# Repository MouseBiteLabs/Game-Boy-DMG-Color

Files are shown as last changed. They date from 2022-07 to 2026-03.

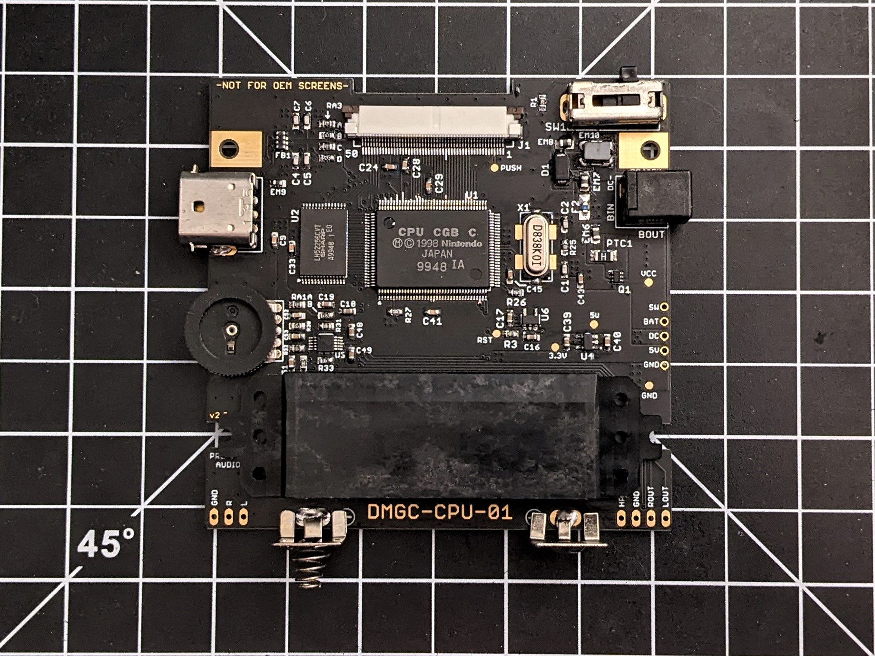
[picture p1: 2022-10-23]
DMGC-CPU-01/DMGC-CPU-01_2-0_FRONT.jpg

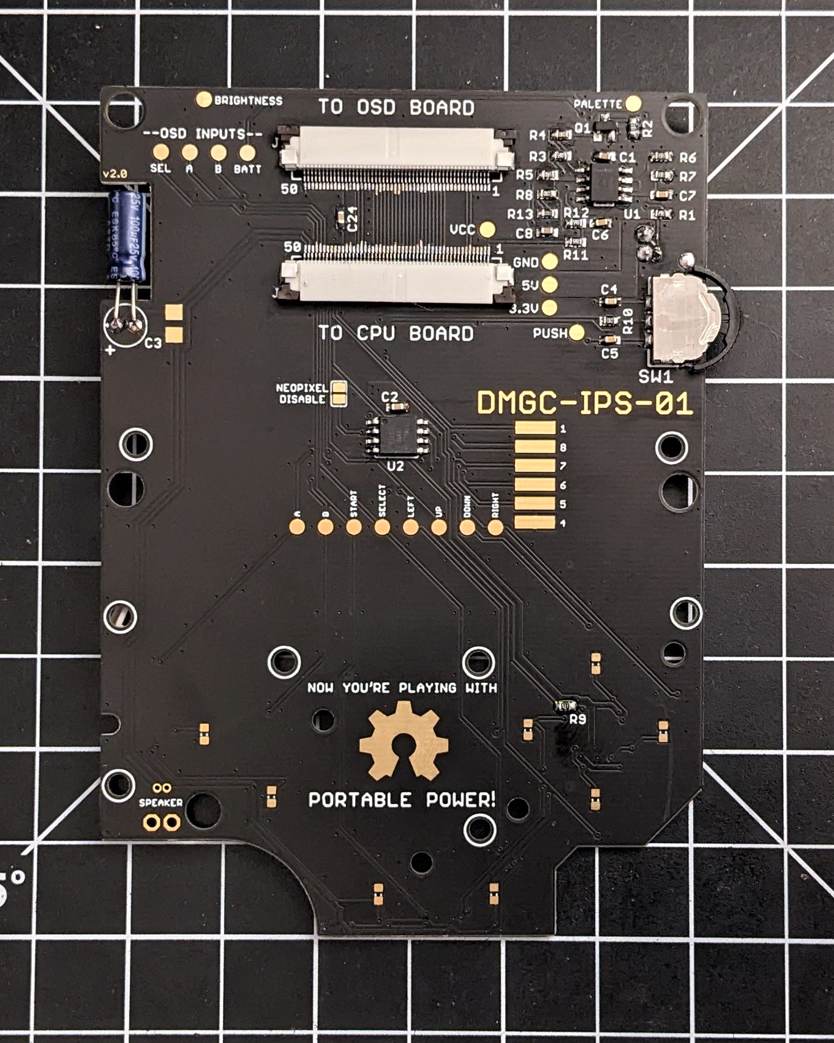
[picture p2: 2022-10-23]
DMGC-IPS-01/DMGC-IPS-01_2-0_BACK.jpg

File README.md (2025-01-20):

# Game Boy DMG Color

system

This is my design for an original Game Boy (model name DMG) with native Game Boy Color support, and a handful of improved features! This is an original creation - newly designed PCBs, with only some necessary components harvested from an original Game Boy and Game Boy Color (no hardware emulation – this project uses the original CPU). Here are the project goals:
-	An original Game Boy aesthetic, using the original Game Boy shell and interface (link port, volume wheel, power switch, etc.), but with the capability of playing both Game Boy and Game Boy Color games.
-	A nice, large IPS screen – the GBC Q5 XL IPS Backlight with OSD kit – with brightness and color palette control via the "navigation switch" housed where the contrast wheel used to be. (I will refer to the PCB attached to the Q5 screen as the “Q5 board”)
-	A modernized, efficient switch mode power supply that can run off 4x AA batteries or input from the DC jack, just like the original DMG. Testing shows that playing with NiMH AA batteries can yield more than 18 hours of gameplay at normal settings (AKA, the way I normally play it - maximum brightness and headphones). 
-	Louder, warmer sound through a modern audio amplifier.
-	The option for tactile switches for the face buttons - like the GBA SP.
-	The option for backlit buttons, with multiple color modes and brightness control.
-	No externally viewable case modifications, outside of trimming the DMG power switch cover for Game Boy Color game compatibility.

The code name for this project is DMGC. This console uses four PCBs, just as the original DMG model did - a CPU board (DMGC-CPU), display board (DMGC-IPS), power board (DMGC-PWR), and headphone board (DMGC-HDP). All circuit board assemblies have their own separate folders in this repository which contain detailed descriptions of operation, source files for schematics and board layouts (designed using Eagle), exported Gerber files, and some other relevant files. 

**Do you want to make one?** Then you NEED TO READ this entire page. Seriously. All your questions will be answered.

## Disclaimer

**Before I go any further, please read this VERY important disclaimer, if you are thinking about making this yourself. Don't let this picture happen to you!**



I made this project first and foremost **for my own purposes**. Nearly all of the features I have included are things I **personally** wanted. I have tried my hardest to make the project modular, if others would like to improve or change things easily, and I have also tried very hard to make the design somewhat less prone to potential errors during assembly (such as spacing out power pins on the FFC connectors). But in the end, every decision I made was for what I wanted the final product to be, with my skill level in mind.

Schematics, gerbers, and the BOM are provided in the various folders. If you choose to build this project yourself, be warned - this is a considerably advanced, and expensive build. You must be comfortable with the fact that you may lose or damage expensive components. **You are 100% liable for any damage done to your property or yourself. I am not responsible for any damage or loss of property incurred while attempting this project, or after completion of the project - you alone accept all risk.** While I am confident in this design, I cannot claim full compatibility with every system configuration. And there may be latent issues that have yet to crop up. I will update this repo if I encounter any, and if you see anything I may have missed, or some dubious design choice, feel free to ask questions or comment as such. Corrections are welcome. However, I **will not** obligate myself to providing tech support. You accept all risks and costs associated to this build if you choose to attempt it.



**DO NOT attempt this project if you are uncomfortable or inexperienced with detailed electronics troubleshooting, or are not proficient in soldering! You will AT MINIMUM need to be proficient in drag soldering and hot air reflowing. If you have not gained proficiency in these soldering skills, DO NOT ATTEMPT THIS PROJECT.**

If you attempt the build, start with trying to assemble DMGC-PWR-01. This is the toughest board to assemble, and it requires no donor components.

## Bill of Materials (BOM)

There are a handful of categories for the parts you need for this build. Please review all of them! The total BOM cost will come out to anywhere between $200 and $250 (NOT including the cost of a donor Game Boy Color console!) depending on the options you choose, which OEM parts you re-use, and any potential deals you can get on certain parts. Note that with the exception of a few components from a donor Game Boy Color, *most* of the electronic parts are brand new.

### I. Circuit Boards

First and foremost, the circuit boards. I have created these four boards myself, and you will need all of them:

1) <a href="https://mousebitelabs.etsy.com/listing/1317688422/game-boy-dmgc-cpu-board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">DMGC-CPU-01</a>: The CPU board, where the brains are held
2) <a href="https://mousebitelabs.etsy.com/listing/1331663235/game-boy-dmgc-ips-board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">DMGC-IPS-01</a>: The front display board
3) <a href="https://mousebitelabs.etsy.com/listing/1317694018/game-boy-dmgc-pwr-board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">DMGC-PWR-01</a>: The power supply board
4) <a href="https://mousebitelabs.etsy.com/listing/1331671237/game-boy-dmgc-hdp-board-headphone-board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">DMGC-HDP-01</a>: The board that holds the headphone jack

I have provided the zipped Gerbers and ordering details in each of the board folders above, <a href="https://www.pcbway.com/project/member/?bmbno=BC9D73E0-EF3D-4F">as well as shared projects on PCBWay.</a> For full disclosure, if you buy the PCBs from PCBWay, I will receive 10% of the total sale towards buying more boards from PCBWay. You can alternatively use these Gerbers at other PCB fabricators if you would like. 

<a href="https://www.pcbway.com/project/member/?bmbno=BC9D73E0-EF3D-4F">PCB from PCBWay</a>

I also sell them on my Etsy store, so you don't have to buy multiples! (Click the banner!)

<a href="https://mousebitelabs.etsy.com">PCB from Etsy</a> 

And finally, <a href="https://shop.insidegadgets.com/product/game-boy-dmg-color/">insideGadgets sells these boards partially assembled!</a>



### II. Brand New Electronic Parts

The DMGC uses mostly all-new parts. This isn't a direct-transfer style project! The master BOM with every electronic component required for the four circuit boards are provided in this root folder in Excel format. Furthermore, each folder for each board will contain their section of the BOM near the bottom of each README that contain all of the electronic components needed for that specific circuit board. Note that some parts may be out of stock at the links provided, but many can be found at alternate other retailers online, or have a proper substitute. <a href="https://www.mouser.com/ProjectManager/ProjectDetail.aspx?AccessID=6600c1bb14">Here is a saved cart from Mouser that contains all the parts in the BOM Excel, including some duplicates.</a> Double check to see if any parts are missing, and consider ordering multiples of some parts. There also may be some parts you want to remove (like the tactile switches).

**If a part is backordered, or out of stock** - check the Excel file, or the BOMs listed at the bottom of each board's folder in this repo. There may be alternate part options. You can also check for stock at places like Digikey. And you can always use Octopart.com to help find in-stock parts at other websites. I can't maintain the cart for every out-of-stock part, so please do some research :)

### III. Game Boy Electronic Parts

*This project requires at the very least a donor DMG console and a donor GBC console.*

There are a handful of parts that I have not located aftermarket substitutes for, and will therefore necessitate an original Game Boy console to salvage from. Please note that removing these parts is not a trivial task, and **requires advanced soldering and desoldering skills to be successful.**

The following parts are required from an original Game Boy Color console:

  -	U1 – CGB CPU (all revisions *except* REV E, which is *incompatible*)
  - X1 – 8.388 MHz crystal oscillator

The following parts can be salvaged from a Game Boy Color, but aftermarket options exist:

  - U2 – LH52256CVTXIZ (SRAM); alternate: https://mou.sr/3f8G0Mi
  - EM10 – input filter; alternate: https://mou.sr/3FiMvXw

The following parts are required from an original Game Boy (DMG) console:
  
  -	SW1 - Power switch
  -	DC jack
  -	Headphone jack

The following part is required from an original Game Boy (DMG), or a Game Boy Four Player Adapter:

  -	EXT port

The following parts can be salvaged from an original Game Boy (DMG), but aftermarket options exist:

  -	VR1 – Volume dial
  -	P1 – Cartridge connector

### IV. External Build Parts

The following is the high-level BOM - basically, the Game Boy part. Note that parts that deviate from the ones listed here (like different shell designs) might necessitate different fitment modifications, or end up being incompatible. Note that this list is not a comprehensive list of all the places you can get these parts. I encourage you to search around if you can't find what you want here.

-	**Shell:** I generally recommend the Funnyplaying "IPS Ready" ones if you don't want to trim anything, but the color and style options are limited. If you don't use these, then you're on your own for how to prepare it - generally, you can follow guides for preparing a Pocket for an IPS screen kit.
    - RGRS:	<a href="https://retrogamerepairshop.com/collections/game-boy-dmg-shells/products/game-boy-dmg-original-new-shells-factory-a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">Game Boy DMG Shell – Factory A</a> [Note: this one requires trimming!]
    - Funnyplaying: <a href="https://funnyplaying.com/products/dmg-ips-coustom-housing">DMG IPS Q5 Custom Housing</a>
- **Screen Kit:** This is the important one. You need this specific type of kit - the Q5 IPS with OSD. It goes by many names, the maker is Hispeedido (*not* FunnyPlaying). Kits that have the screen laminated to a GBC lens are *not* compatible, but kits that include a lit-up logo on the bottom part of the screen are fine to use. Make sure you DO NOT get any Game Boy DMG versions - they are not compatible! Also, be sure to test this screen kit before installing it, preferrably with an original Game Boy Color. Sometimes they arrive damaged, and once you've installed, it may not be possible to get a refund.
  - RGRS: <a href="https://retrogamerepairshop.com/products/game-boy-color-q5-ips-backlight-with-osd?variant=37646279213228">GBC Q5 XL IPS Backlight with OSD</a> OR <a href="https://retrogamerepairshop.com/collections/gbc-displays/products/game-boy-color-q5-osd-ips-kit-with-color-changing-logo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">Game Boy Color Q5 OSD IPS Kit with Color Changing Logo 
  - AliExpress: <a href="https://www.aliexpress.us/item/3256801650459088.html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">GBC Q5 IPS LCD Kit</a>
  - HHL: <a href="https://handheldlegend.com/products/game-boy-color-ips-lcd-q5-hispeedido">Game Boy Color IPS LCD Q5 - Hispeedido</a>  
- **Screen Centering Bracket:** You can find the design file for this bracket in the DMGC-IPS-01 folder. It's a custom designed bracket I made that *is required* for holding the screen in place. You will need access to a 3D printer for this part, or you can order it online from 3D printing services by uploading the file.
  - <a href="https://github.com/MouseBiteLabs/Game-Boy-DMG-Color/blob/main/DMGC-IPS-01/dmgc_q5_bracket.stl">DMGC Q5 Bracket 3D Model .stl File</a>
-	**Lens:** You must get the "IPS" style of lens, as the viewing area is larger.
    -	RGRS: <a href="https://retrogamerepairshop.com/collections/dmg-lenses/products/funnyplaying-dmg-q5-ips-lens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">FunnyPlaying DMG Q5 IPS Lens</a>
    - FunnyPlaying: <a href="https://funnyplaying.com/products/dmg-retro-pixel-ips-glass-lens">DMG RetroPixel IPS Glass Lens</a>
- **Buttons:** Funnyplaying models are generally OEM-like (IMO), but you can also use OEM ones. For the above build, I used Kitsch-Bent silicone buttons. Bonus: NES controller buttons fit inside the DMG.
  -	Kitsch-Bent: <a href="https://store.kitsch-bent.com/products/silicone-buttons?variant=40627510771907">Clear Silicone DMG Buttons</a>
  - RGRS: <a href="https://retrogamerepairshop.com/collections/dmg-buttons">DMG Buttons</a>
  - LabFifteen: <a href="https://labfifteenco.com/en-us/collections/game-boy-dmg-buttons">Game Boy DMG Buttons</a>
  - FunnyPlaying: <a href="https://funnyplaying.com/products/gb-dmg-custom-buttons">DMG Custom Buttons</a>  
- **Membranes:** Important, but very forgettable! You will need them even if you install tactile switches. You will, however, *not* need them if you use the Kitsch-Bent buttons.
  - RGRS: <a href="https://retrogamerepairshop.com/collections/dmg-buttons/products/funnyplaying-game-boy-dmg-silicone-button-contact-pad-membranes">FunnyPlaying Game Boy DMG Silicone Button Contact Pad Membranes
  - FunnyPlaying: <a href="https://funnyplaying.com/products/replacement-silicone-pads-for-gb-dmg">DMG Replacement Silicone Pads</a>  
- **Speaker:** There are tons of options for this as well, including using the OEM one.
  - RGRS: <a href="https://retrogamerepairshop.com/collections/dmg-audio/products/funnyplaying-clear-game-boy-dmg-original-speaker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">FunnyPlaying Clear Game Boy DMG Original Speaker</a>
  - FunnyPlaying: <a href="https://funnyplaying.com/products/clear-dmg-speaker">Clear DMG Speaker</a>
- **Battery Tabs:** This one is another part I commonly forget about. You can use a salvaged set of tabs, or order new ones.
  - RGRS: <a href="https://retrogamerepairshop.com/collections/dmg-power/products/game-boy-dmg-original-high-quality-replacement-battery-contact-terminals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">Game Boy DMG Original High Quality Replacement Battery Contact Terminals
- **Stickers:** Completely optional, but they can really bring a build together. Especially if you have custom DMG Color stickers!
  - Nextstopplease: <a href="https://nextstopplease.square.site/product/dmgc-label/230?cp=true&sa=true&sbp=false&q=false">DMGC Labels</a>

<b>Buying from RGRS? Consider helping out some cool people with these referral links:</b>
- <a href="https://retrogamerepairshop.com/?ref=ltyD2rUX">CodyWick</a>
- <a href="https://retrogamerepairshop.com/?ref=HSj4v5OO">JackV</a>

<b>Or use one of these discount codes at checkout:</b>
- Nataliethenerd
- B23N
- Tito

Note that the IPS kit I have listed is the *easiest* IPS kit to use that is compatible with this build. It includes an image centering feature, so you don't need to fiddle with centering it manually in the shell. Other kits likely would not center nicely in the DMG shell! <a href="https://retrogamerepairshop.com/collections/gbc-displays/products/game-boy-color-2-6-ips-high-brightness-drop-in-backlight-lcd-kit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">This kit works electrically, but requires you to center the image yourself.</a> If you end up making some sort of 3D-printed bracket to support this screen, feel free to share it here.

## Assembly

You can check out Tito's video on the DMGC to get an idea of how the assembly process generally goes.

MachoNacho DMGC Video (https://youtu.be/4U8Tqu7uxLo)

Here are some pictures of the assembly process *after* testing the functionality of all the boards separately. Detailed images of the circuit boards alone are shown in their respective folders. These pictures are of a previous revision, v1.2, but the process remains the same. You may notice some minor cosmetic differences in these pictures from the current revision boards.

**I highly recommend reading the information in the Troubleshooting and Testing folder above. In it, I detail the testing procedure that I follow before fully assembling a DMGC. It is far easier to do this than to have to disassemble things when something doesn't work.**

First, I started with the back half of the DMG shell. The PWR board needs five ~2.25" wires that wrap around the screw post on the side of the shell. In addition to the PWR board connections, the HDP board needs four ~2.6" wires. Also, the flat flex cable (FFC) should be inserted into the CPU board first, because the connector will be inaccessible after screwing the CPU board in the shell. After I soldered all the wires between the three boards and secured the FFC, I placed the assembly in the shell, and secured it with the proper screws. I put a game in the cartridge slot to keep the CPU board in place easier while assembling.

PXL_20220802_000205491 MP

Before placing the power switch cover in, I cut a notch in it so that it wouldn't prevent Game Boy Color games from being played in the system. In the left picture below I’m using Game Boy games, and in the right picture I'm using Game Boy Color. And you can see that the power switch is blocked from turning on by the GBC cartridge for the original model.



After the back half was done, I prepared the Q5 board solder pads. I cut six 30 gauge wire segments and soldered them on the brightness, palette, battery, and OSD input pads. These will be soldered to the rear of the IPS board after installed. You don't need to include a wire to the GND pad.



For the top half of the shell, as per instructions on a similar DMG IPS kit that uses the Q5 screen, I very carefully cut ~1 mm of plastic around the border of the viewing port, and trimmed any extra plastic to make the surface underneath the lens smooth (there are "IPS ready" shells that should not require this cut). I used a black paint marker to color in the edges of the newly cut plastic, so they would not be visible at an angle. And I trimmed two posts off of the shell so the screen would fit flush against it. 



Then I installed the front lens, and placed the screen, backed with the 3D printed bracket, into the front half of the shell. I made sure to clean up any stray fingerprints or dust while assembling this part. Once the bracket was placed and flush with the shell, I put the buttons in and placed the IPS board over top, slid the Q5 screen FFC into the connector on the PCB (making sure it fit without any added stress on any connections), and secured it all in place. Then I *very carefully* soldered the wires from the Q5 board onto the appropriate pads on the IPS board - making sure not to melt any plastic on the shell.



**Note: Be extremely careful with the screen. It is fragile. If you break it, you can sometimes buy one separately.

If you installed the 7-pin headers for programming the ATTINY easier, you might want to tape off the headers with kapton tape. If everything is installed correctly, these shouldn't interfere with anything on the CPU board after the halves are screwed together (C47 is the closest component), but you may want to consider it anyway.



After that, it was just a matter of connecting the FFC from the CPU to the IPS board, tucking it under the boards ensuring no kinks or sharp bends, and screwing it together. Once assembled, I opened the OSD menu for the IPS kit (Select + A + B) and changed the vertical and horizontal offsets (my values were 78 and 29, respectively) to center the image on the screen. The image centering function is one of the biggest reasons I chose this IPS kit.

I suggest running the color tests in the <a href="https://github.com/pinobatch/240p-test-mini/releases/">240p test suite ROM</a>, if you have a flash cart to run it on. It will tell you if you have any poor connections on the FFC lines - the screen might work, but you might be missing a connection on one of the 15 RGB pins! If your colors look off, reflow the connections on the top row of pins on the CPU and/or the FFC connectors (the issue may be on the CPU board, *or* the IPS board). This picture (provided by <a href="https://retrogamerepairshop.com/?ref=HSj4v5OO">JackV</a>) shows a before and after pic for reflowing a few mis-soldered color pins.



Next to an original DMG… one can really see the improvements!

PXL_20220816_034738908~2 (2)

## Auxilliary Controls
### Q5 XL IPS Backlight with OSD
-	Select + A + B: Open the OSD menu
-	Select + A: Enter
-	Select + B: Exit
-	A: Increase
-	B: Decrease

### Navigation Switch
-	Rock up: Advance screen brightness setting
-	Rock up/Hold: Toggle on-screen battery indicator
-	Rock down: Advance screen color pallete setting
-	Rock down/Hold: Toggle on-screen pixel grid
-	Push in: Toggle button LED color setting
-	Push in/Hold + D-pad Left: Decrease button LED brightness
-	Push in/Hold + D-Pad Right: Increase button LED brightness
-	Push in/Hold when turning on power switch: Disable LEDs until another power cycle

## Power Draw Measurements
For these estimates, battery life is calculated using four eneloop pro NiMH AA batteries (total of ~11800 mWh). Keep in mind that these are very rough estimates. I tried to be conservative in the power draw measurements, so hopefully these numbers represent a *mostly* worst case. Actual playtime *will* vary due to a variety of factors - changes in efficiency and performance as the battery voltage changes, differences in game audio, etc.

I measured the power draws using a MiniWare MDP-XP Mini Digital Power Supply, and estimated the average power draw shown on the display (I tried to bias towards a higher value). Input voltage was set to 4.4 V, just above the point where the power LED dims. I tested with the Legend of Zelda: Link's Awakening, letting the game sit on the title screen after the intro cinematic, where sound is relatively loud and the screen is mostly white. The audio gain on the test console is set to ~0.38 (see CPU board for more detail on this gain value - a higher gain can greatly impact power draw at high volumes out of the speaker).

| Test Criteria | Power Draw | Estimated Battery Life |
| --- | --- | --- |
| IPS max brightness, NeoPixel LEDs max brightness (white), speaker volume 100%, Everdrive X5	| 1150 mW	| 10.3 hr |
| IPS max brightness, NeoPixel LEDs off, speaker volume 100%, Everdrive X5 | 900 mW	| 13.1 hr |
| IPS max brightness, NeoPixel LEDs off, speaker volume 100%, original cartridge | 750 mW | 15.7 hr |
| IPS max brightness, NeoPixel LEDs off, headphones, Everdrive X5	| 725 mW	| 16.3 hr |
| IPS max brightness, NeoPixel LEDs off, headphones, original cartridge | 650 mW	| 18.2 hr |
| IPS min brightness, NeoPixel LEDs off, headphones, original cartridge	| 475 mW	| 24.8 hr |

*Note: If powering through the DC jack instead of batteries, an OEM adapter may not be able to supply enough power to the DMGC at maximum settings. Furthermore, <a href = "https://retrogamerepairshop.com/products/dmg-game-boy-original-dmg-usb-power-cord-adapter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">cables like these</a> will require at least ~200 mA output from the USB port for reliable operation at all settings. (USB 1.0 and 2.0 are likely not sufficient for higher loads, such as with the button LEDs on)*

## Audio Recordings and Spectrum
I mentioned the sound of the DMGC is "warmer" than an original GBC - it's bassier with less buzzing background noise (owing mostly to the modernized power supply). I connected the headphone jack to my computer's microphone input, and used Audacity to obtain line out recordings. Then I graphed the spectrum using Audacity's "plot spectrum" analysis tool. You can see the larger gain at the lower frequencies in the spectrum plot of the DMGC. I also took some recordings of the pro-sound output as well - it's even cleaner than from the amplifier. I'm not an audiophile, but I'm pretty sure the DMGC all-around sounds nicer, at least through headphones. Listen for yourself! (GitHub only allows for video files to be embedded, MP3 files are provided above)

### Original GBC Audio

https://user-images.githubusercontent.com/97127539/180215249-4b21aca1-a9fd-430a-a870-95bf4837e4da.mp4

### DMGC Audio

https://user-images.githubusercontent.com/97127539/180215280-5e533449-5116-4848-a94b-92f8979db334.mp4

### DMGC Audio (Pro-sound)

https://user-images.githubusercontent.com/97127539/197674317-792a8da5-ebd5-4ef6-9e8d-8eab0cbf9284.mp4

### Original GBC Audio Spectrum



### DMGC Audio Spectrum



### DMGC Audio (Pro-sound) Spectrum



## Possible Additions/Changes
Want to improve this project? Maybe try one of these things (because I probably won’t):
- This console uses 4x AAs instead of a single rechargeable battery in order to maintain the feel and weight of the original DMG model, but an obvious change to the build is to utilize a LiPo battery with proper battery management. The DC jack could be repurposed to charge the battery instead. With the advent of affordable rechargeable AAs, the appeal of the AC adapter is diminished, so this would be a good repurposing. However, the maximum output current of most DMG AC adapters is rated for ~200mA at ~6V, so charging would be considerably slower than, say, fast USB-C charging.
- Restoring the IR functionality of the GBC could also be done, as there is ample space for it on the circuit board and shell - I just do not trust myself with forming plastic to look nice, and it wasn't at all an important part of the build for me.
- Finding aftermarket equivalents for all the different required DMG parts would be ideal, instead of using a (hopefully broken) DMG for a donor console. For my personal build, I used original DMG components because I had a damaged console lying around, but you can easily find DMG-style volume wheels and cartridge connectors online. The tricky parts are as follows:
  - A GBC EXT port can be used in place of the DMG one (but would look kind of weird in the DMG EXT hole in the shell).
  - There are a few power switches I've ordered to try out in place of the DMG one, but I haven't gotten around to testing them yet. There's no one fully drop-in replacement that I've found, though, so it would require circuit modifications.
  - I haven't been able to locate a headphone jack exactly the same as the DMG one, but the circuit could be adapted to accept a different style.
  - The DC jack could be tricky. I haven't looked very hard for any kind of replacement for this.
- Any other of the various popular GBC mods could be incorporated if desired - bluetooth, overclocking, etc. With the ATTINY on the IPS board, one could incorporate button combinations to interface with these mods without the need of any additional buttons or (*shudder*) touch controls.
- I thought about adding LEDs to the *back* of the front PCB, so that light would emit out the edges of the console with a translucent or transparent shell, but I never got around to trying it out.

## Potential Issues/Annoyances
-	When the button LEDs are on max brightness, using the NeoPixel LEDs specifically (especially on the white color setting), a ~1 kHz whine can be heard through the speakers or headphones. I attempted to remove this whine with different methods – adding filtering to the supplies, using separate supplies for the audio/LEDs, etc. –  this lowered the noise amplitude, but I wasn’t able to remove it completely. And obviously adding a filter on the audio output is a no-go since 1 kHz is smack dab in the middle of the audible range. Changing to different color settings can reduce the volume of the whine, red in particular seems to be quite low, and setting the LEDs at lower brightness levels (or just completely off) removes it. So just don’t play with the LEDs on really bright if it bugs you! I kept the color sweep during power-on enabled on every color setting - if you want to disable the LEDs for the entire play session, hold the navigation dial in when you turn it on (but at that point... why did you bother adding the LEDs in the first place?)
-	The original DMG A/C adapter that plugs into the DC jack cannot support play with maximum settings (backlit buttons, maximum brightness, maximum speaker volume, flash cart). If you start up the Game Boy with less than maximum settings, then during gameplay increase the load on the power supply such as by increasing the screen brightness or maxing out the volume on the speakers, the console may shut off. If you're powering the console through the DC jack, I suggest using a USB adapter cable into a USB 3.0 port (or some style of USB wall charger)

## Frequently Asked Questions

I'll update this section as more people begin to build these.

**Q: How do I lower the brightness of the power LED? I can't see anymore.**

A: You can pick a different LED model with lower brightness, or you can simply increase the resistance of R1 on the IPS board. Higher resistance = lower brightness. I would try 10 kΩ first if 5.6 kΩ is too bright. (If you want to dim the low power level LED brightness, increase R2 resistance as well!)

**Q: My EM10 has an extra leg in-between two of the other ones. Can I use this part?**

A: Yes, just bend up the extra pin so that it doesn't contact any of the nearby pads. It is an unused anchor pin.

**Q: Why does the audio sound like [not normal]? (Usually asked while testing during the middle of a build)**

A: The audio will sound terrible if you do not have your IPS kit connected. You can use the CPU board's FFC connnector for the IPS kit if you would like to test it without the IPS board in the middle. Furthermore, the speaker will be muted if you do not install the headphone board.

**Q: Sometimes the power switch is finnicky and the system won't power on consistently. Sometimes the IPS screen will turn on, but only the backlight, not the actual image. What gives?**

A: Clean your power switch (without batteries inserted or power applied) by dripping isopropyl alcohol inside and flipping it off and on a few times. This will hopefully clear up debris or oxidation. Opening up a DMG power switch isn't the funnest thing to do. I have found that if the IPS kits receive intermittent power while turning on, it will lock out their image processing until you power cycle. It's not damaging, just annoying.

**Q: When I have the front and back halves of the DMGC separate, everything powers on correctly. But when I screw the two halves together, it doesn't turn on. Why?**

A: Check to make sure the wires connecting the CPU and PWR boards do not have long stubs of wire sticking up out of the CPU board. The IPS board's navigation dial has metal housing that can short these wire stubs together if they are too long. Trim them short so they don't touch the metal shielding.

**Q: Sometimes when I'm using batteries and turn the power switch on, nothing happens.**

-AND/OR-

**Q: Sometimes when I play my DMGC, and I set it on the table too hard, the game resets. Why?**

A: Usually this is because you're using NiMH AA batteries, like eneloop pros. These batteries have *slightly* shallower positive tabs than regular alkaline AA batteries. This makes contact from the batteries to the tabs not as robust as regular AA batteries. Unfortunately this is a problem on *ALL* DMG consoles, not specifically the DMGC. This could be due to a poor connection on any one of the four batteries inside the bay. You can swap out battery contacts that stick out a bit farther that make better contact with the batteries, or you can try reseating or literally spinning the batteries in the battery bay to make better contact. (Or, you could always use regular AA batteries or an A/C adapter!)

**Q: Can I use this with a DMG CPU?**

A: No, this is only for use with Game Boy Color CPUs. There are some other projects around that recreate the DMG, <a href="https://github.com/kamicane/DMG-01-B">like this one</a>.

**Q: I really like this project, but I just wish it was in a smaller, more cramped shell, with way worse battery life. Can you help?**

A: <a href="https://imgur.com/a/JgXPnYc">I'm working on it.</a>

## Acknowledgements
-	The board outlines and many of the footprints for the DMG components from <a href="https://gbdev.gg8.se/files/schematics/">this DMG recreation project</a> were used for reference on the original revision of the project, so very special thanks to Rolf, bit9, and nitro2k01!
-	Thank you to gekkio for their <a href="https://gbhwdb.gekkio.fi/">Game Boy repository</a> and <a href="https://github.com/Gekkio/gb-schematics">github</a>: I referenced many of the DMG and GBC resources during this build, even just for looking at pictures of different PCBs.
-	Immense thanks to the users of the r/Gameboy and gbdev discord servers for technical resources, troubleshooting/feedback, and suggestions. Could not have done this without your support. Shout out to kevtris for design feedback and lidnariq for troubleshooting support!
- Thank you to Tito, aka Macho Nacho, for <a href="https://www.youtube.com/watch?v=4U8Tqu7uxLo&ab_channel=MachoNachoProductions">his amazing video covering the project.</a>
-	Of course, huge thank you to everyone who has <a href="https://ko-fi.com/bucketmouse">donated and supported me</a>, and to those who have built their own DMGC! I love seeing pictures of builds, so feel free to share them with me on Twitter, <a href="https://discord.gg/Y5aDvCcpbX">discord</a>, or via email!

## License
<br />This work is licensed under a <a rel="license" href="http://creativecommons.org/licenses/by-sa/4.0/">Creative Commons Attribution-ShareAlike 4.0 International License</a>. You are able to copy and redistribute the material in any medium or format, as well as remix, transform, or build upon the material for any purpose (even commercial) - but you **must** give appropriate credit, provide a link to the license, and indicate if any changes were made.

This project is the culmination of nearly a full year of research, development, and testing. I have made this project completely open-source, and have put hundreds, if not *thousands* of hours of work into it, so that many people can enjoy it. **Please** give me appropriate credit where credit is due.

©MouseBiteLabs 2022

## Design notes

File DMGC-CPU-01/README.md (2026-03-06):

# DMGC-CPU-01

DMGC-CPU-01_2-3_scan
DMGC-CPU-01_2-0_ASSEMBLED

*The image above of the assembled board is of v2.0, not the current revision of v2.4. The differences in appearance are minor, see below.*

The CPU board houses the majority of the electronics in the DMGC. Parts harvested from the original GBC include the CPU, SRAM, and crystal oscillator. EM10 may be transferred as well, but a good enough replacement is included in the BOM if you need a new part. The power supply modifications, the new audio circuit, and a handful of omissions like the IR communication and some of the now-unnecessary LCD pins differentiate this build from the original GBC. But many connections and component values are pulled from the official GBC schematic (linked below).

For a technical explanation of the CPU board, please view the README in the Technical folder.

## Board Characteristics
The zipped folder contains all the gerber files for this board. 

-	Layers: 2
-	Thickness: 1.2 mm
-	Surface Finish: ENIG or HASL
-   **NOTE: For v2.4, when ordering PCBs, add this note to the order: "The file milling.gbr contains outlines for plated slots. Please add plated slots on the PCB according to this layer." V2.5 does not require this note.**

*HASL will work, but will potentially be more difficult for soldering fine-pitch parts like the CPU and FFC connector.*

<a href="https://www.etsy.com/listing/1317688422/game-boy-dmgc-cpu-board">**I sell this board on Etsy, so you don't have to buy multiples from board fabricators.**</a>

You can alternatively use the zipped folder at any board fabricator you like. You may also buy the board from PCBWay using this link (disclosure: I receive 10% of the  sale value to go towards future PCB orders):

<a href="https://www.pcbway.com/project/shareproject/Game_Boy_DMG_Color_DMGC_CPU_01_2f5c743d.html">PCB from PCBWay</a> 

## Customization Options

This section will explain all of the different customization options available on this board while assembling.

### Adjusting Volume Range

You can adjust the maximum volume coming out of the speakers and headphones by modifying R30 and R32 values. Increase R30 and R32 to decrease the maximum volume; decrease R30 and R32 to increase the maximum volume. Choose the same values for both of these resistors, otherwise you'll have lopsided audio channels. After some trial and error, here's my approximations of some different values of resistors:
- Choosing 100 kΩ for a gain of ~0.18 will yield about the same volume as a stock GBC. 
- Using 47 kΩ seemed to hit a sweet spot for my tastes for a gain of ~0.38 - not too loud, not too quiet.
- The lowest value I tried out was 33 kΩ, but this was *considerably* loud. It also began to have an actual impact in the battery voltage. I suspect values lower than about 20 kΩ will greatly reduce battery life.

### Pro-Sound Output

Added in version 2.0, opposite of the regular headphone outputs, are a set of audio outputs denoted as "pre-pot audio." The left and right channels connect directly to the VR1-S01 and VR1-S02 nodes, which allows you to grab the audio unfiltered, unamplified, right from the GBC CPU (through a protection resistor/capacitor combo). This is colloquailly known as the "pro-sound" mod, and is typically used in conjunction with a *second* audio jack. Audiophiles like to use this raw output with their audio equipment (note that using the pro-sound output as input to an external amplifier does not disable the speaker or headphones - the potentiometer still controls volume for those audio outputs). You could use this jack for headphones if you want (and it will disable the speaker), but it will always be one volume - about as loud as the original GBC at max volume. The audio coming out of these pins does sound incredibly clean - check out the recordings in the root folder. These outputs should make the system compatible with any pro-sound headphone boards, <a href="https://www.retromodding.com/products/gameboy-pcb-mount-pro-sound-v3">like this one.</a>

### Adding Reset Button Functionality

Version 2.0 also introduces a test pad labelled "RST" that connects directly to the /RESET pin. If this pin is pulled to GND, when it's released it the system will reset back to the boot screen. If you wire this pad to a button that connects the pad to GND when pressed, you basically have added a reset button to your DMGC. 

There are also pads near the FFC connector that are added labelled "PUSH" and "ROCK DOWN". These connect to the rocker switch on the DMGC-IPS-01 board (version 2.0 and later). The PUSH pad becomes connected to GND when the rocker switch is pushed in and floats when not pressed (as long as you remove R10 on the DMGC-IPS-01 board). The ROCK_DOWN pad connects to GND when the rocker switch is rocked down, and floats when not pressed (as long as you remove C5 on the DMGC-IPS-01 board).

In a normal configuration, pushing in on the rocker switch will control the button LEDs, and rocking down will swap the Q5 color settings, but if you don't want to use one of these features, then adding a wire from the PUSH or ROCK DOWN pad to RST pad will turn the rocker switch into a reset button for the system for that specific action and replace its normal function.

**CAUTION: Remember to remove R10 or C5 on the IPS board if you plan to use this feature!!!**





## Bill of Materials

Here, I have provided links to components I used personally (or suitable replacements). This BOM is also included in Excel format in the root folder.

| Reference Designators | Qty | Value/Part Number | Package | Description | Comment | Source |
| --- | --- | --- | --- | --- | --- | --- |
| +,- | 2 | | | Battery terminals  | Can be salvaged from DMG instead | [https://retrogamerepairshop.com/collections/dmg-power/products/game-boy-dmg-original-high-quality-replacement-battery-contact-terminals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](https://retrogamerepairshop.com/collections/dmg-power/products/game-boy-dmg-original-high-quality-replacement-battery-contact-terminals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) |
| C1 | 1 | 18pF | 0603 | Capacitor (MLCC) | Should be X5R (or better); at least 1% tolerance; at least 16V | [https://www.mouser.com/ProductDetail/YAGEO/CC0603FRNPO9BN180?qs=vTakOoo5QyL0KzYUzHPSUw%3D%3D](https://www.mouser.com/ProductDetail/YAGEO/CC0603FRNPO9BN180?qs=vTakOoo5QyL0KzYUzHPSUw%3D%3D) |
| C2 | 1 | 27pF | 0603 | Capacitor (MLCC) | Should be X5R (or better); at least 1% tolerance; at least 16V | [https://www.mouser.com/ProductDetail/603-C0603FRNPO9BN270](https://www.mouser.com/ProductDetail/603-C0603FRNPO9BN270) |
| C4 | 1 | 22pF | 0603 | Capacitor (MLCC) | | [https://www.mouser.com/ProductDetail/YAGEO/CC0603JRNPO9BN220?qs=vTakOoo5QyIVMYOUTI%2F4zA%3D%3D](https://www.mouser.com/ProductDetail/YAGEO/CC0603JRNPO9BN220?qs=vTakOoo5QyIVMYOUTI%2F4zA%3D%3D) |
| C5, C6, C7 | 3 | 100pF | 0603 | Capacitor (MLCC) | | [https://www.mouser.com/ProductDetail/YAGEO/CC0603JPNPO9BN101?qs=7s%252B3O6pAiyAo%2FUxNqKltRA%3D%3D](https://www.mouser.com/ProductDetail/YAGEO/CC0603JPNPO9BN101?qs=7s%252B3O6pAiyAo%2FUxNqKltRA%3D%3D) |
| C9, C10, C29, C33, C41, C45 | 6 | 0.01uF | 0603 | Capacitor (MLCC) | Should be X5R (or better), at least 16V | [https://www.mouser.com/ProductDetail/KEMET/C0603C103J5RACTU?qs=BimOss5pjlFJEfKhlb7g1g%3D%3D](https://www.mouser.com/ProductDetail/KEMET/C0603C103J5RACTU?qs=BimOss5pjlFJEfKhlb7g1g%3D%3D) |
| C16, C17, C18, C19, C39, C40, C48, C49, C51 | 9 | 1uF | 0603 | Capacitor (MLCC) | Should be X5R (or better), at least 16V | [https://www.mouser.com/ProductDetail/KEMET/C0603C105K4RACTU?qs=STjISULpmtZNMAZGR4X39Q%3D%3D](https://www.mouser.com/ProductDetail/KEMET/C0603C105K4RACTU?qs=STjISULpmtZNMAZGR4X39Q%3D%3D) |
| C24, C28, C43, C52, C53 | 5 | 0.1uF | 0603 | Capacitor (MLCC) | Should be X5R (or better), at least 16V | [https://www.mouser.com/ProductDetail/?qs=l5k%252BbMnNDknCtKnMv1oEgA%3D%3D](https://www.mouser.com/ProductDetail/?qs=l5k%252BbMnNDknCtKnMv1oEgA%3D%3D) |
| C47 | 1 | 150pF | 0603 | Capacitor (MLCC) | | [https://www.mouser.com/ProductDetail/KEMET/C0603C151J5GACTU?qs=V6nSPVTm7vxbAvL0weNH%252BQ%3D%3D](https://www.mouser.com/ProductDetail/KEMET/C0603C151J5GACTU?qs=V6nSPVTm7vxbAvL0weNH%252BQ%3D%3D) |
| D1 | 1 | PMEG2010AEH | SOD-123 | Schottky diode | Most schottky diodes should be suitable (at least 1A, 16V) | [https://www.mouser.com/ProductDetail/?qs=LOCUfHb8d9u7lcjEnyhX1g%3D%3D](https://www.mouser.com/ProductDetail/?qs=LOCUfHb8d9u7lcjEnyhX1g%3D%3D) |
| DC | 1 | | | DC jack | | Salvaged (DMG) |
| EM6-EM8 | 3 | FBMH2012HM221-T | 0805 | Filter | | https://mou.sr/3YT6y8F |
| EM9 | 1 | BLM18BD102SN1D | 0603 | Filter | | [https://www.mouser.com/ProductDetail/Murata-Electronics/BLM18BD102SN1D?qs=h3IWXJJGQQWi4eZyJq6ScQ%3D%3D](https://www.mouser.com/ProductDetail/Murata-Electronics/BLM18BD102SN1D?qs=h3IWXJJGQQWi4eZyJq6ScQ%3D%3D) |
| EM10 | 1 | 744235601 | | Common mode filter | Can be salvaged from GBC instead | [https://www.mouser.com/ProductDetail/Wurth-Elektronik/744235601?qs=BXmE%252BJ0Y7xYO4MPd53j2NQ%3D%3D](https://www.mouser.com/ProductDetail/Wurth-Elektronik/744235601?qs=BXmE%252BJ0Y7xYO4MPd53j2NQ%3D%3D) |
| F1 | 1 | 2.5A | 1206 | Fuse | | [https://www.mouser.com/ProductDetail/Panasonic/ERB-RG2R50V?qs=Z3CaLxJiOJK8SjHyp%252BdV%2FQ%3D%3D](https://www.mouser.com/ProductDetail/Panasonic/ERB-RG2R50V?qs=Z3CaLxJiOJK8SjHyp%252BdV%2FQ%3D%3D) |
| F2 | 1 | 1A | 1206 | Fuse | | [https://www.mouser.com/ProductDetail/Littelfuse/0466001.NR?qs=ar9f0rk5DXDy6tpNfF8WnQ%3D%3D](https://www.mouser.com/ProductDetail/Littelfuse/0466001.NR?qs=ar9f0rk5DXDy6tpNfF8WnQ%3D%3D) |
| FB1 | 1 | BLA31AG601SN4D | 1206 | Ferrite Bead | | [https://www.mouser.com/ProductDetail/Murata-Electronics/BLA31AG601SN4D?qs=2ahBf5rJw09FDcUVkQibEg%3D%3D](https://www.mouser.com/ProductDetail/Murata-Electronics/BLA31AG601SN4D?qs=2ahBf5rJw09FDcUVkQibEg%3D%3D) |
| P1 | 1 | | | Cart connector | Can be salvaged from DMG instead | [https://www.aliexpress.com/item/3256802533298738.html?spm=a2g0o.order_list.0.0.5ee21802yek6HF](https://www.aliexpress.com/item/3256802533298738.html?spm=a2g0o.order_list.0.0.5ee21802yek6HF) |
| P2 | 1 | | | Link port | | Salvaged (DMG) |
| P3 | 1 | 62684-502100AHLF  | | FFC connector | | [https://www.mouser.com/ProductDetail/?qs=HL%252BYNjdyZ0vzwc9E0QYY2g%3D%3D](https://www.mouser.com/ProductDetail/?qs=HL%252BYNjdyZ0vzwc9E0QYY2g%3D%3D) |
| PTC1 | 1 | 1.1A Hold | 1206 | Resettable Fuse | | [https://www.mouser.com/ProductDetail/Littelfuse/1206L110THYR?qs=CPcc0c%2Fon9HuH5Zb2mgbPg%3D%3D](https://www.mouser.com/ProductDetail/Littelfuse/1206L110THYR?qs=CPcc0c%2Fon9HuH5Zb2mgbPg%3D%3D) |
| Q1 | 1 | SI1443EDH | SOT363 | P-channel MOSFET | | [https://www.mouser.com/ProductDetail/Vishay-Semiconductors/SI1443EDH-T1-GE3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](https://www.mouser.com/ProductDetail/Vishay-Semiconductors/SI1443EDH-T1-GE3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) |
| R1 | 1 | 1k | 0603 | Resistor | | [https://www.mouser.com/ProductDetail/YAGEO/RC0603FR-071KL?qs=VU8sRB4EgwApHsk4rF%2F3zg%3D%3D](https://www.mouser.com/ProductDetail/YAGEO/RC0603FR-071KL?qs=VU8sRB4EgwApHsk4rF%2F3zg%3D%3D) |
| R3, R31, R33 | 3 | 18k | 0603 | Resistor | | [https://www.mouser.com/ProductDetail/YAGEO/RC0603FR-1018KL?qs=qpJ%252B%252B%252Bdg6p1T2VMMxU7GeA%3D%3D](https://www.mouser.com/ProductDetail/YAGEO/RC0603FR-1018KL?qs=qpJ%252B%252B%252Bdg6p1T2VMMxU7GeA%3D%3D) |
| R25 | 1 | 1.5M | 0603 | Resistor | Recommended at least 1% tolerance | [https://www.mouser.com/ProductDetail/YAGEO/RC0603FR-071M5L?qs=VU8sRB4EgwAP38Z8qzPx9Q%3D%3D](https://www.mouser.com/ProductDetail/YAGEO/RC0603FR-071M5L?qs=VU8sRB4EgwAP38Z8qzPx9Q%3D%3D) |
| R26 | 1 | 5.6k | 0603 | Resistor | | [https://www.mouser.com/ProductDetail/YAGEO/RC0603FR-075K6L?qs=2cAdsCoAWRHvOVv%2Fp%252BkS0g%3D%3D](https://www.mouser.com/ProductDetail/YAGEO/RC0603FR-075K6L?qs=2cAdsCoAWRHvOVv%2Fp%252BkS0g%3D%3D) |
| R27 | 1 | 100 | 0603 | Resistor | | [https://www.mouser.com/ProductDetail/YAGEO/RC0603FR-07100RL?qs=NEN%2FsE%2FLsvPIwIWKCOS4%2FA%3D%3D](https://www.mouser.com/ProductDetail/YAGEO/RC0603FR-07100RL?qs=NEN%2FsE%2FLsvPIwIWKCOS4%2FA%3D%3D) |
| R36 | 1 | 100k | 0603 | Resistor | | [https://www.mouser.com/ProductDetail/YAGEO/RC0603FR-07100KL?qs=e1ok2LiJcmaihem8Va5%2Fsw%3D%3D](https://www.mouser.com/ProductDetail/YAGEO/RC0603FR-07100KL?qs=e1ok2LiJcmaihem8Va5%2Fsw%3D%3D) |
| R30, R32 | 2 | 47k | 0603 | Resistor | | [https://www.mouser.com/ProductDetail/YAGEO/RC0603FR-1047KL?qs=EiqXWrxQq600ZhhpLJs%252BtA%3D%3D](https://www.mouser.com/ProductDetail/YAGEO/RC0603FR-1047KL?qs=EiqXWrxQq600ZhhpLJs%252BtA%3D%3D) |
| RA1A, RA1B | 2 | 510 | 0603 | Resistor | | [https://www.mouser.com/ProductDetail/YAGEO/RC0603FR-07510RL?qs=gt6vzsuosg04lV7mPQHzdw%3D%3D](https://www.mouser.com/ProductDetail/YAGEO/RC0603FR-07510RL?qs=gt6vzsuosg04lV7mPQHzdw%3D%3D) |
| RA3A-RA3D | 4 | 270 | 0603 | Resistor | | [https://www.mouser.com/ProductDetail/YAGEO/RC0603FR-07270RL?qs=diQw95jMAePl%252BPNr4oNP6Q%3D%3D](https://www.mouser.com/ProductDetail/YAGEO/RC0603FR-07270RL?qs=diQw95jMAePl%252BPNr4oNP6Q%3D%3D) |
| SW1 | 1 | | | Power switch | | Salvaged (DMG) |
| U1 | 1 | GBC CPU | QFP-128 | CPU | | Salvaged (GBC) |
| U2 | 1 | LH52256CVTXIZ | TSOP-28 | RAM | Replacement: https://mou.sr/3f8G0Mi | Salvaged (GBC) |
| U3 | 1 | LM4853 | VSSOP-10 | Audio amplifier | | [https://www.mouser.com/ProductDetail/Texas-Instruments/LM4853MM-NOPB?qs=QbsRYf82W3F2psFI2da2Dw%3D%3D](https://www.mouser.com/ProductDetail/Texas-Instruments/LM4853MM-NOPB?qs=QbsRYf82W3F2psFI2da2Dw%3D%3D) |
| U4 | 1 | NCP161ASN330T1G | SOT23-5 | LDO | Can also use TLV70233QDBVRQ1, probably | [https://www.mouser.com/ProductDetail/863-NCP161ASN330T1G](https://www.mouser.com/ProductDetail/863-NCP161ASN330T1G) |
| U6 | 1 | TPS3840DL35 | SOT23-5 | Supervisory IC | Could feasibly use TPS3840DL37 or 40 if 35 is out of stock | [https://www.mouser.com/ProductDetail/Texas-Instruments/TPS3840DL35DBVR?qs=7MVldsJ5UawbjRj7dP73rA%3D%3D](https://www.mouser.com/ProductDetail/Texas-Instruments/TPS3840DL35DBVR?qs=7MVldsJ5UawbjRj7dP73rA%3D%3D) |
| VR1 | 1 | 10k | | Volume wheel | Can be salvaged from DMG instead | [https://aliexpi.com/qg1M](https://aliexpi.com/qg1M) |
| X1 | 1 | 8.388608MHz | 7.5X5-4-PAD | Crystal oscillator | Potential replacement (not very space-friendly): https://mou.sr/3D5AUbH | Salvaged (GBC) |

## Revision History

### v2.5
- Added space for adding <a href="https://shop.insidegadgets.com/product/gba-clockxcontrol/">ClockxControl by insideGadgets</a>

### v2.4
- Changed some reference designators for more consistency to source PCBs
- Expanded slot for FFC to feed through to back of board

### v2.3

- Nudge volume dial to better center it in the shell

### v2.2

- Added more clearance on screwhole on cart connector
- Adjusted screwhole placement near power switch
- Removed unnecessary vestigal dots on X1 and EM10 silkscreen
- Fixed tstop layer offset on SRAM package
- Added CLK1/2 on backside silkscreen
- Adjusted X1 through-hole location
- Nudged volume dial out a bit
- Add note about trimming wire stubs on PWR board connections
- Cleaned up some trace layouts/silkscreen

### v2.1

- Fixed silkscreen text error on link port
- Added through-holes for potential crystal oscillator replacement
- Added test pad that connects to the rock-down function of the navigation dial on the IPS board
- Moved version number text above cart connector footprint

### v2.0

- Changed holes to slots where applicable
- Made board/part measurements more accurate
- Added dedicated output pins for pro-sound output next to the negative battery tab
- Updated crystal oscillator footprint to allow for later crystal packages
- Added a test pad that connects to the push-in trigger for the rocker switch on the IPS board
- Added a test pad connected to the reset line on the CPU for potential mods (pull to GND to reset the Game Boy)
- Added LP line from CPU to FFC connector for potential use with another IPS kit

### v1.3

- Added test points to back of the board
- Shifted FFC connector down a few mm

### v1.2

- Release version

## License
<br />This work is licensed under a <a rel="license" href="http://creativecommons.org/licenses/by-sa/4.0/">Creative Commons Attribution-ShareAlike 4.0 International License</a>. You are able to copy and redistribute the material in any medium or format, as well as remix, transform, or build upon the material for any purpose (even commercial) - but you **must** give appropriate credit, provide a link to the license, and indicate if any changes were made.

©MouseBiteLabs 2022

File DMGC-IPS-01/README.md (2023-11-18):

# DMGC-IPS-01

DMGC-IPS-01_2-3_scan
DMGC-IPS-01_2-0_ASSEMBLED

*The image above of the assembled board is of v2.0, not the current revision of v2.4. The differences are very minor, see below.*

The IPS board is in the front of the DMG shell. This holds the IPS screen kit (and has pads for interfacing with it), has the dimmable power LED, button inputs along with pads for optional LEDs, a navigation switch on the side for changing settings on the IPS screen and the backlit buttons, and the speaker.

For a technical explanation of the CPU board, please view the README in the Technical folder.

## Board Characteristics

The zipped folder contains all the gerber files for this board.
-	Layers: 2
-	Thickness: 1.2 mm
-	Surface Finish: ENIG or HASL (SEE NOTE!)

*ENIG is required for reliable button press detection; you can use HASL if you are using tactile switches.*

<a href="https://www.etsy.com/listing/1331663235/game-boy-dmgc-ips-board">**I sell this board on Etsy, so you don't have to buy multiples from board fabricators.**</a>

You can alternatively use the zipped folder at any board fabricator you like. You may also buy the board from PCBWay using this link (disclosure: I receive 10% of the  sale value to go towards future PCB orders):

<a href="https://www.pcbway.com/project/shareproject/Game_Boy_DMG_Color_DMGC_IPS_01_82a454c9.html">PCB from PCBWay</a>

## Customization Options

This section will explain all of the different customization options available on this board while assembling.

### Tactile Switches

Version 2.0 introduced the option for including tactile switches for the buttons, much like the Game Boy Advance SP had. If you do not wish to use these kinds of buttons, the button contacts are still set up to act just like the regular set up with membranes.



In this image, tactile switches are on the left, and pads for simple membranes are on the right. Either method for button presses works perfectly fine. But make sure you put them in the correct way. The little "wings" on the switches should be oriented where there is blank board space.

If you're doing tactile switches on the start and select buttons, you should do a trace cut as indicated where the white lines are pointing. If you don't, the membranes can still activate the start/select buttons on the exposed area without actuating the tactile switch. You may also want to tape over the exposed copper not underneath the switches while soldering them on to avoid getting stray solder on the exposed traces and ruin the A E S T H E T I C.



### Power LED Brightness

Increase the value of R1 to decrease the brightness of the power LED during normal battery levels. Increase the value of R2 to decrease the brightness of the power LED during low battery levels. It is suggested to try changing resistances in ~5 kΩ increments.

### Backlit Buttons

There are a few different avenues to take with respect to the button LEDs. You can use the RGB NeoPixels, discrete always-on LEDs, or none at all.

1) **No Button LEDs:** You do not need to populate LED10-LED17, R9, R22-R29, C2, or U2. Carry on.

2) **Always-on Single Color Backlit Buttons:** If you only want backlit buttons with non-controllable LEDs, you can omit R9, C2, and U2. 

You must isntead install R22-R29, as well as the discrete 0603 LEDs. An 0603 LED will fit on half of the 4-pin RGB LED pads, from VDD to DO. The pads for this are indicated by the arrows. The picture below shows which pads to use for discrete LEDs (view of the D-pad) - the A indicates the anode of the diode. There are spaces for a resistor for each LED on the back of the board (R22 to R29, circled in red below). If you're using the RGB LEDs, or no LEDs at all, the resistors aren't necessary. R22-R29 control the brightness of the LEDs, so keep in mind a higher resistance means lower brightness.



3) **RGB Backlit Buttons:** If you would like RGB LEDs behind the buttons, you must install LED10-LED17, R9, C2, and U2. Do not populate R22-R29.

When you solder the LEDs on, I recommend taping off the button contacts to make sure you don't get solder on them. It won't damage them to the point of non-function, but it can potentially reduce their useful lifetime and accurate detection depending on the severity. (But more importantly, it's not A E S T H E T I C)



If you install the LEDs and determine they just aren't for you, but don't want want to spend time removing the LEDs themsleves, then bridging the solder pad labeled "NEOPIXEL DISABLE" will ground the navigation switch push function, preventing the LEDs from turning on at all.

#### Programming the ATTINY85

An easy way to program the ATTINY with the code for the backlit buttons is to use an Arduino Uno or Arduino Mega. Check out these tutorials for how to program ATTINY chips with them:

-	<a href="https://www.instructables.com/How-to-Burn-ATTiny85-Using-Arduino-Mega/">Instructables post for programming an ATTINY85 with an Arduino Mega</a>
-	<a href="https://www.instructables.com/How-to-Program-an-Attiny85-From-an-Arduino-Uno/">Instructables post for programming an ATTINY85 with an Arduino Uno</a>

The code is provided above (the .ino file) and you will likely need to install Adafruit's NeoPixel library as well to get it to compile correctly. That can be found here:

- <a href="https://learn.adafruit.com/adafruit-neopixel-uberguide/arduino-library-installation">Installing Adafruit's NeoPixel Library to Arduino IDE</a>

If you're programming the ATTINY while it's installed on the IPS board, be sure to remove the cables from J1 and J2, otherwise your Arduino will attempt to backfeed the Gameboy and/or the IPS screen kit.

You can use the 7-pin connector on the side of the IPS board to connect to the ATTINY if it's already on the PCB. (You don't need the 3.3V pin to program, it's there for helping you develop your own ATTINY code if you want to use it)



**NOTE: VERSION DIFFERENCE**

On the v2.0 and v2.1 boards, pins 1 and 8 are flipped! And the 3.3V pin does not exist.



### Adding Reset Button Functionality

- If you are using the push function of the navigation switch to reset the console instead of controlling the button LEDs (see more info on the CPU README), then **make sure to remove R10.** You will not have the ability to control Neopixel LEDs with this change (without other code/hardware modifications).
- If you are using the rock down function of the navigation switch to reset the console instead of controlling the Q5 palette setting (see more info on the CPU README), then **make sure to remove C5.** You will not have the ability to use the palette swap function of the Q5 kit with this change (but who really cares, amirite?)





### Alternate OSD Controls

You don't need to use the SEL, A, and B pads at the top of the board for the OSD controls. You can alternatively use the button pads in the middle of the board instead. For example, if you intend to use LSDJ on the DMGC, you might run into a conflict with pressing A + B + Select. This is a specific combination for control in LSDJ. So instead for OSD control, you can run wires down to the middle of the board. Instead of A, B, and Select, you could pick A, B, and Start for example. Just keep in mind you have to press all three at the same time to open the menu, so don't pick Left and Right as two of the inputs, for example.



## Bill of Materials

Here, I have provided links to components I used personally (or suitable replacements). This BOM is also included in Excel format in the root folder.

| Reference Designators | Qty | Value/Part Number | Package | Description | Comment | Source |
| --- | --- | --- | --- | --- | --- | --- |
| B1-B8 | 8 | SKRRABE010 | | Tactile switch | Optional, can be omitted if you don't want clicky SP-style buttons (SKRRAA is less clicky, SKRRAC is more clicky) | [https://www.mouser.com/ProductDetail/688-SKRRAB](https://www.mouser.com/ProductDetail/688-SKRRAB) |
| C1, C2, C6, C7, C8, C24 | 6 | 0.1uF | 0603 | Capacitor (MLCC) | Should be X5R (or better), at least 16V | [https://www.mouser.com/ProductDetail/?qs=l5k%252BbMnNDknCtKnMv1oEgA%3D%3D](https://www.mouser.com/ProductDetail/?qs=l5k%252BbMnNDknCtKnMv1oEgA%3D%3D) |
| C3 | 1 | 100uF | | Capacitor (Aluminum electrolytic) | Board has space for a 100uF SMD tantalum electrolytic instead | [https://www.mouser.com/ProductDetail/KEMET/ESK107M010AC3AA?qs=9RUIYXQlAdBiO30krUyznA%3D%3D](https://www.mouser.com/ProductDetail/KEMET/ESK107M010AC3AA?qs=9RUIYXQlAdBiO30krUyznA%3D%3D) |
| C4, C5 | 2 | 100pF | 0603 | Capacitor (MLCC) | | [https://www.mouser.com/ProductDetail/YAGEO/CC0603JPNPO9BN101?qs=7s%252B3O6pAiyAo%2FUxNqKltRA%3D%3D](https://www.mouser.com/ProductDetail/YAGEO/CC0603JPNPO9BN101?qs=7s%252B3O6pAiyAo%2FUxNqKltRA%3D%3D) |
| C9, C10 | 2 | 27pF | 0603 | Capacitor (MLCC) | | [https://www.mouser.com/ProductDetail/603-C0603FRNPO9BN270](https://www.mouser.com/ProductDetail/603-C0603FRNPO9BN270) |
| FFC Cable | 1 | 15020-0541 | | Flat Flexible Cable | Gold plated preferred, but alternate part can work too. Note that 15020-0541 must be bent in the proper direction for good fitment | [https://www.mouser.com/ProductDetail/Molex/15020-0541?qs=pwzmk436yFR5fXbQvbR%2F1w%3D%3D](https://www.mouser.com/ProductDetail/Molex/15020-0541?qs=pwzmk436yFR5fXbQvbR%2F1w%3D%3D) |
| J1, J2 | 2 | 62684-502100AHLF  | | FFC connector | | https://www.mouser.com/ProductDetail/?qs=HL%252BYNjdyZ0vzwc9E0QYY2g%3D%3D |
| J3 | 1 | TSM-107-01-T-SH | | Surface Mount Terminal Strip | Optional for assembly, only helpful for programming the ATTINY | [https://www.mouser.com/ProductDetail/200-TSM10701TSH](https://www.mouser.com/ProductDetail/200-TSM10601TSH) |
| LED1 | 1 | 151033RS03000 | 3mm | Red LED | | [https://www.mouser.com/ProductDetail/Wurth-Elektronik/151033RS03000?qs=LlUlMxKIyB1%252BAw6bWFN43w%3D%3D](https://www.mouser.com/ProductDetail/Wurth-Elektronik/151033RS03000?qs=LlUlMxKIyB1%252BAw6bWFN43w%3D%3D) |
| LED10-LED17 | 8 | WS2812 | 2020 | RGB LED | Link leads to a 10-pack. Discrete 0603-size LEDs can be used instead | [https://www.mouser.com/ProductDetail/Adafruit/4684?qs=DPoM0jnrROWIv9%2FMCIm5vw%3D%3D](https://www.mouser.com/ProductDetail/Adafruit/4684?qs=DPoM0jnrROWIv9%2FMCIm5vw%3D%3D) |
| Q1 | 1 | 2N7002 | SOT23 | N-channel MOSFET | | [https://www.mouser.com/ProductDetail/Nexperia/2N7002NXBKR?qs=%252B6g0mu59x7J2ddJstTJGkQ%3D%3D](https://www.mouser.com/ProductDetail/Nexperia/2N7002NXBKR?qs=%252B6g0mu59x7J2ddJstTJGkQ%3D%3D) |
| R1, R14 | 2 | 10k | 0603 | Resistor | | [https://www.mouser.com/ProductDetail/YAGEO/RC0603FR-0710KL?qs=grNVn54RoB%252B3GtjbJj3wJQ%3D%3D](https://www.mouser.com/ProductDetail/YAGEO/RC0603FR-0710KL?qs=grNVn54RoB%252B3GtjbJj3wJQ%3D%3D) |
| R22-R29 | 8 | 10k | 0603 | Resistor | Only if using discrete LEDs for LED10-LED17 (adjust resistance for brightness) | [https://www.mouser.com/ProductDetail/YAGEO/RC0603FR-0710KL?qs=grNVn54RoB%252B3GtjbJj3wJQ%3D%3D](https://www.mouser.com/ProductDetail/YAGEO/RC0603FR-0710KL?qs=grNVn54RoB%252B3GtjbJj3wJQ%3D%3D) |
| R2, R6, R7 | 3 | 18k | 0603 | Resistor | | [https://www.mouser.com/ProductDetail/YAGEO/RC0603FR-1018KL?qs=qpJ%252B%252B%252Bdg6p1T2VMMxU7GeA%3D%3D](https://www.mouser.com/ProductDetail/YAGEO/RC0603FR-1018KL?qs=qpJ%252B%252B%252Bdg6p1T2VMMxU7GeA%3D%3D) |
| R3, R5, R11, R12 | 4 | 402k | 0603 | Resistor | | [https://www.mouser.com/ProductDetail/YAGEO/RC0603FR-07402KL?qs=e5TEs1AaK9ZgNZ9JLlILuQ%3D%3D](https://www.mouser.com/ProductDetail/YAGEO/RC0603FR-07402KL?qs=e5TEs1AaK9ZgNZ9JLlILuQ%3D%3D) |
| R4 | 1 | 100 | 0603 | Resistor | | [https://www.mouser.com/ProductDetail/YAGEO/RC0603FR-07100RL?qs=NEN%2FsE%2FLsvPIwIWKCOS4%2FA%3D%3D](https://www.mouser.com/ProductDetail/YAGEO/RC0603FR-07100RL?qs=NEN%2FsE%2FLsvPIwIWKCOS4%2FA%3D%3D) |
| R8, R10 | 2 | 100k | 0603 | Resistor | | [https://www.mouser.com/ProductDetail/YAGEO/RC0603FR-07100KL?qs=e1ok2LiJcmaihem8Va5%2Fsw%3D%3D](https://www.mouser.com/ProductDetail/YAGEO/RC0603FR-07100KL?qs=e1ok2LiJcmaihem8Va5%2Fsw%3D%3D) |
| R9 | 1 | 510 | 0603 | Resistor | | [https://www.mouser.com/ProductDetail/YAGEO/RC0603FR-07510RL?qs=gt6vzsuosg04lV7mPQHzdw%3D%3D](https://www.mouser.com/ProductDetail/YAGEO/RC0603FR-07510RL?qs=gt6vzsuosg04lV7mPQHzdw%3D%3D) |
| R13 | 1 | 15k | 0603 | Resistor | | [https://www.mouser.com/ProductDetail/YAGEO/RC0603FR-1015KL?qs=EiqXWrxQq61HhvsANs7j4w%3D%3D](https://www.mouser.com/ProductDetail/YAGEO/RC0603FR-1015KL?qs=EiqXWrxQq61HhvsANs7j4w%3D%3D) |
| Speaker | 1 | 8Ω | | Speaker | Can also used salvaged DMG speaker | [https://retrogamerepairshop.com/products/funnyplaying-clear-game-boy-dmg-original-speaker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](https://retrogamerepairshop.com/products/funnyplaying-clear-game-boy-dmg-original-speaker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) |
| SW1 | 1 | COM-08184 | | Navigation switch | | [https://www.mouser.com/ProductDetail/SparkFun/COM-08184?qs=WyAARYrbSnYOIhcg6ARCiQ%3D%3D](https://www.mouser.com/ProductDetail/SparkFun/COM-08184?qs=WyAARYrbSnYOIhcg6ARCiQ%3D%3D) |
| U1 | 1 | LMV358 | SOIC-8 | Op-amp | | [https://www.mouser.com/ProductDetail/Texas-Instruments/LMV358IDR?qs=EIjG%252BN7kn%252BmCHnTyCQRw3Q%3D%3D](https://www.mouser.com/ProductDetail/Texas-Instruments/LMV358IDR?qs=EIjG%252BN7kn%252BmCHnTyCQRw3Q%3D%3D) |
| U2 | 1 | ATTINY85 | SOIC-8 (5.3mm wide) | Microcontroller | Only if using NeoPixels (might need to buy the ATTINY from eBay or AliEx) | [https://www.mouser.com/ProductDetail/556-ATTINY85V10SU](https://www.mouser.com/ProductDetail/556-ATTINY85V10SU) |

## Revision History

### v2.4

- Added desensitizing capacitors (C9, C10) to reduce accidental touch inputs on IPS kit

### v2.3

- Moved R9 to avoid interference with post
- Moved warning text
- Added more power LED polarity indication

### v2.2

- Removed start button from PB5 on ATTINY85, added pull-up resistor
- Added 3.3V connection to programming header
- Added option for larger tactile switch on start/select
- Expanded pads for tactile switches for easier soldering

### v2.1

- Fixed cosmetic error in A button tstop layer
- Added options for start/select tactile switches
- Added warning about programming on silkscreen text
- Added trace that connects to a test pad on the CPU board for the rock-down function of the navigation dial
- ~~Connected start button to PB5 on ATTINY85~~ Reworked

### v2.0

- Made board/part measurements more accurate
- Added option for tactile switches for D-pad and A/B buttons
- Added extra ground and LP line on FFC connectors for potential use with another IPS kit
- Added optional solder pad to disable NeoPixel LEDs permanently
- Added pads for kinked header pins to program the ATTINY85 easier
- Added plated vias for potential Micro JST connector for the speaker

### v1.3

- Fixed Schmitt trigger circuit for power LED dimming
- Moved Q5 battery detection (BATT) to op-amp output instead of voltage divider output

### v1.2

- Release version

## License
<br />This work is licensed under a <a rel="license" href="http://creativecommons.org/licenses/by-sa/4.0/">Creative Commons Attribution-ShareAlike 4.0 International License</a>. You are able to copy and redistribute the material in any medium or format, as well as remix, transform, or build upon the material for any purpose (even commercial) - but you **must** give appropriate credit, provide a link to the license, and indicate if any changes were made.

©MouseBiteLabs 2022

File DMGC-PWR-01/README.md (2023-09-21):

# DMGC-PWR-01

DMGC-PWR-01_2-0_black
DMGC-PWR-01_2-0_ASSEMBLED_black

*Note: This image shows v2.0. There is minimal difference between this and v2.3.*

The PWR board has gone through a few iterations. Because the system will run with 4x AA batteries or the DC jack input, the range of input voltages is relatively wide - anywhere between ~4 V up to ~8 V, plus margin. The output voltage must be maintained at 5 V. The logical choice would be a buck-boost converter. Thus, the DMGC-PWR-01 utilizes the TPS630702 (or TPS63070 or TPS630701) – a buck-boost converter with only a few external parts required for operation, that accepts anywhere between 2 V and 16 V to produce a 5 V output.

This board is likely the most complex part of the build. I spent a lot of time tuning the circuit to produce the exact results I wanted with ample protection downstream of the converters.

For a technical explanation of the CPU board, please view the README in the Technical folder.

## Board Characteristics
The zipped folder contains all the gerber files for this board.
-	Layers: 2
-	Thickness: 1.2 mm or smaller
-	Surface Finish: ENIG or HASL

*HASL is acceptable, but might introduce a bit of difficulty soldering the QFN chip owing to the possibly uneven surface compared to an ENIG finish.*

<a href="https://www.etsy.com/listing/1317694018/game-boy-dmgc-pwr-board">**I sell this board on Etsy, so you don't have to buy multiples from board fabricators.**</a>

You can alternatively use the zipped folder at any board fabricator you like. You may also buy the board from PCBWay using this link (disclosure: I receive 10% of the sale value to go towards future PCB orders):

<a href="https://www.pcbway.com/project/shareproject/Game_Boy_DMG_Color_DMGC_PWR_01_f8f2e84a.html">PCB from PCBWay</a>

## Configuring for Different TPS chips on U2

For TPS63070 or TPS630702, R8 needs to be 523k and R9 needs to be 100k, as indicated in the BOM.

For TPS630701, you need to short R8 with a solder bridge/wire or a zero ohm resistor, and remove R9 completely.

**It is critical you configure the board correctly, otherwise you may damage your system.**

## Using in an Original DMG (UNTESTED!)

This board can (probably) be used as a replacement to the original DMG power board, provided you are using an IPS screen that only requires a 5 V output. This board will not supply voltages for the LCD, so it cannot be used in an unmodded DMG.



Follow the silkscreen on the back of the board to connect wires to the DMG motherboard, as shown below (image from Gekkio's Game Boy Hardware Database: https://gbhwdb.gekkio.fi/consoles/dmg/). The red wire on the main DMG CPU board indicates pin 1. The blue box on the back of the DMG CPU board indicates the connection for the BAT hole.



IF you happen to test this (at your own risk!) let me know your results.

## Bill of Materials

Here, I have provided links to components I used personally (or suitable replacements). This BOM is also included in Excel format in the root folder.

| Reference Designators | Qty | Value/Part Number | Package | Description | Comment | Source |
| --- | --- | --- | --- | --- | --- | --- |
| C1, C5, C6 | 3 | 10uF | 0603 | Capacitor (MLCC) | Should be X5R (or better), at least 16V | [https://www.mouser.com/ProductDetail/Murata-Electronics/GRM188R61E106KA73J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](https://www.mouser.com/ProductDetail/Murata-Electronics/GRM188R61E106KA73J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) |
| C3, C4 | 2 | 22uF | 1206 | Capacitor (MLCC) | Should be X5R (or better), at least 16V | [https://www.mouser.com/ProductDetail/Samsung-Electro-Mechanics/CL31A226KAHNNNE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](https://www.mouser.com/ProductDetail/Samsung-Electro-Mechanics/CL31A226KAHNNNE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) |
| C7 | 1 | 47uF | 1206 | Capacitor (MLCC) | Should be X5R (or better), at least 16V | [https://www.mouser.com/ProductDetail/Murata-Electronics/GRM31CR61C476ME44K?qs=QzBtWTOodeVeYV6UhCOqow%3D%3D](https://www.mouser.com/ProductDetail/Murata-Electronics/GRM31CR61C476ME44K?qs=QzBtWTOodeVeYV6UhCOqow%3D%3D) |
| C8, C9, C11 | 3 | 0.1uF | 0603 | Capacitor (MLCC) | | [https://www.mouser.com/ProductDetail/?qs=l5k%252BbMnNDknCtKnMv1oEgA%3D%3D](https://www.mouser.com/ProductDetail/?qs=l5k%252BbMnNDknCtKnMv1oEgA%3D%3D) |
| C10 | 1 | 0.01uF | 0603 | Capacitor (MLCC) | | [https://www.mouser.com/ProductDetail/KEMET/C0603C103J5RACTU?qs=BimOss5pjlFJEfKhlb7g1g%3D%3D](https://www.mouser.com/ProductDetail/KEMET/C0603C103J5RACTU?qs=BimOss5pjlFJEfKhlb7g1g%3D%3D) |
| F1 | 1 | 1A | 0603 | Fuse | | [https://www.mouser.com/ProductDetail/Vishay-Beyschlag/MFU0603FF01000P100?qs=oI046glRurtlP8n%252B3l7CPg%3D%3D](https://www.mouser.com/ProductDetail/Vishay-Beyschlag/MFU0603FF01000P100?qs=oI046glRurtlP8n%252B3l7CPg%3D%3D) |
| L1 | 1 | 1.5uH | 1212 | Inductor | Saturation current should be at least 2A | [https://www.mouser.com/ProductDetail/70-IHLP1212BZER1R5M1](https://www.mouser.com/ProductDetail/70-IHLP1212BZER1R5M1) |
| Q1 | 1 | MMBT3906 | SOT23 | PNP BJT | | [https://www.mouser.com/ProductDetail/Micro-Commercial-Components-MCC/MMBT3906HE3-TP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](https://www.mouser.com/ProductDetail/Micro-Commercial-Components-MCC/MMBT3906HE3-TP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) |
| Q2, Q4, Q5 | 3 | 2N7002 | SOT23 | N-channel MOSFET | | [https://www.mouser.com/ProductDetail/Nexperia/2N7002NXBKR?qs=%252B6g0mu59x7J2ddJstTJGkQ%3D%3D](https://www.mouser.com/ProductDetail/Nexperia/2N7002NXBKR?qs=%252B6g0mu59x7J2ddJstTJGkQ%3D%3D) |
| Q3 | 1 | MMBT3904 | SOT23 | NPN BJT | | [https://www.mouser.com/ProductDetail/Nexperia/MMBT3904VL?qs=cnAQGvEIVkKbCwIpHJoHxQ%3D%3D](https://www.mouser.com/ProductDetail/Nexperia/MMBT3904VL?qs=cnAQGvEIVkKbCwIpHJoHxQ%3D%3D) |
| Q6 | 1 | SI1443EDH | SOT363 | P-channel MOSFET | | [https://www.mouser.com/ProductDetail/Vishay-Semiconductors/SI1443EDH-T1-GE3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](https://www.mouser.com/ProductDetail/Vishay-Semiconductors/SI1443EDH-T1-GE3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) |
| R1, R4, R7, R9, R10, R11, R16 | 7 | 100k | 0603 | Resistor | R9 should have at least 1% tolerance | [https://www.mouser.com/ProductDetail/YAGEO/RC0603FR-07100KL?qs=e1ok2LiJcmaihem8Va5%2Fsw%3D%3D](https://www.mouser.com/ProductDetail/YAGEO/RC0603FR-07100KL?qs=e1ok2LiJcmaihem8Va5%2Fsw%3D%3D) |
| R2, R3, R5, R13, R14 | 5 | 10k | 0603 | Resistor | | [https://www.mouser.com/ProductDetail/YAGEO/RC0603FR-0710KL?qs=grNVn54RoB%252B3GtjbJj3wJQ%3D%3D](https://www.mouser.com/ProductDetail/YAGEO/RC0603FR-0710KL?qs=grNVn54RoB%252B3GtjbJj3wJQ%3D%3D) |
| R15 | 1 | 1k | 0603 | Resistor | | [https://www.mouser.com/ProductDetail/YAGEO/RC0603FR-071KL?qs=VU8sRB4EgwApHsk4rF%2F3zg%3D%3D](https://www.mouser.com/ProductDetail/YAGEO/RC0603FR-071KL?qs=VU8sRB4EgwApHsk4rF%2F3zg%3D%3D) |
| R8 | 1 | 523k | 0603 | Resistor | At least 1% tolerance. Not needed if using TPS630701 | [https://www.mouser.com/ProductDetail/YAGEO/RC0603FR-07523KL?qs=TkC2zyCLazpzUFWuXe7EHg%3D%3D](https://www.mouser.com/ProductDetail/YAGEO/RC0603FR-07523KL?qs=TkC2zyCLazpzUFWuXe7EHg%3D%3D) |
| R12 | 1 | 20k | 0603 | Resistor | | [https://www.mouser.com/ProductDetail/YAGEO/RC0603FR-0720KL?qs=VU8sRB4EgwCsxfrjtEIKPQ%3D%3D](https://www.mouser.com/ProductDetail/YAGEO/RC0603FR-0720KL?qs=VU8sRB4EgwCsxfrjtEIKPQ%3D%3D) |
| U1 | 1 | TPS3840DL35 | SOT23-5 | Supervisory IC | Could feasibly use TPS3840DL32 if 35 is out of stock | [https://www.mouser.com/ProductDetail/Texas-Instruments/TPS3840DL35DBVR?qs=7MVldsJ5UawbjRj7dP73rA%3D%3D](https://www.mouser.com/ProductDetail/Texas-Instruments/TPS3840DL35DBVR?qs=7MVldsJ5UawbjRj7dP73rA%3D%3D) |
| U2 | 1 | TPS63070, TPS630701, TPS630702 | 15-VQFN-HR | Buck-boost converter | Might be difficult to find. TPS630702 preferred, but all will work. Check https://octopart.com/search?q=tps63070&currency=USD&specs=0 | [https://www.mouser.com/ProductDetail/Texas-Instruments/TPS630702RNMT?qs=vLWxofP3U2wR9GhA3fXurw%3D%3D](https://www.mouser.com/ProductDetail/Texas-Instruments/TPS630702RNMT?qs=vLWxofP3U2wR9GhA3fXurw%3D%3D) |
| U3 | 1 | TPS3702CX50 | SOT23-6 | Supervisory IC | Optional IF you fully test the power board and confirm proper 5V operation | [https://www.mouser.com/ProductDetail/595-TPS3702CX50DDCR](https://www.mouser.com/ProductDetail/595-TPS3702CX50DDCR) |

## Revision History

### v2.3
- Moved some components
- Removed C2 (not needed on previous revisions either)
- Fixed DMG connection silkscreen
- Changed RC time constant for undervoltage detection
- Added test points across the board

### v2.2
- Added F1 back
- Added DMG connections notation on silkscreen

### v2.1
- Moved R12/R13 to front of the board
- Removed F1

### v2.0 (for sale)
- Release version

## License
<br />This work is licensed under a <a rel="license" href="http://creativecommons.org/licenses/by-sa/4.0/">Creative Commons Attribution-ShareAlike 4.0 International License</a>. You are able to copy and redistribute the material in any medium or format, as well as remix, transform, or build upon the material for any purpose (even commercial) - but you **must** give appropriate credit, provide a link to the license, and indicate if any changes were made.

©MouseBiteLabs 2022

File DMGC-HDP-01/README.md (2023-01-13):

# DMGC-HDP-01



*The image above is of v2.0, not the current revision of v2.1. The differences are very minor, see below.*

This little board is quite simple. You can transplant all of the parts from the original DMG headphone board to this one. This board also uses an original DMG headphone jack. Modifications to the circuit would be required to use an off-the-shelf jack.

## Board Characteristics
The zipped folder contains all the gerber files for this board.
-	Layers: 2
-	Thickness: 1.2 mm or 1.6 mm
-	Surface Finish: HASL
- **NOTE: When ordering PCBs, add this note to the order: "The file milling.gbr contains outlines for plated slots. Please add plated slots on the PCB according to this layer."**

<a href="https://www.etsy.com/listing/1331671237/game-boy-dmgc-hdp-board-headphone-board">**I sell this board on Etsy, so you don't have to buy multiples from board fabricators.**</a>

You can alternatively use the zipped folder at any board fabricator you like. You may also buy the board from PCBWay using this link (disclosure: I receive 10% of the  sale value to go towards future PCB orders):

<a href="https://www.pcbway.com/project/shareproject/Game_Boy_DMG_Color_DMGC_HDP_01_bdacd78d.html">PCB from PCBWay</a>

## Circuit Overview



On the top of the board: pin 1 is the left output, pin 2 is the right output, pin 3 is the GND reference, and pin 4 is the headphone detect pin which is normally connected to GND through the headphone jack (when headphones are placed in the jack, pin 4 will be disconnected from GND).

R1 and R2 are included to pull down the negative sides of the DC blocking capacitors C1 and C2 when headphones are not connected – without them, the outputs would be floating. This will prevent inrush current during headphone insertion, which I have seen cause issues with the LM4853 in the past.

On v2.1, C1 and C2 can be replaced with tantalum electrolytic capacitors if you would like - the pads are for size 1411 (3528 metric).

## Using the Original DMG Headphone Board

You can easily use the original DMG board instead of ordering this one, just be sure to put 1 kΩ resistors from the right output and left output to ground. Otherwise, when plugging in headphones, the system might shut itself off.



## Bill of Materials

All of the parts from the original headphone board can be transplanted here (except the two 1k resistors). You can even use the original headphone board if you want, just add the 1k resistors as indicated on the schematic. This BOM is also included in Excel format in the root folder.

| Reference Designators | Qty | Value/Part Number | Package | Description | Comment | Source |
| --- | --- | --- | --- | --- | --- | --- |
| C1, C2 | 2 | 100uF | | Capacitor (Aluminum electrolytic) | Can be salvaged from DMG instead | [https://www.mouser.com/ProductDetail/Panasonic/ECE-A0JKA101I?qs=WYPlz5ezODCWQbvWRFj8Mg%3D%3D](https://www.mouser.com/ProductDetail/Panasonic/ECE-A0JKA101I?qs=WYPlz5ezODCWQbvWRFj8Mg%3D%3D) |
| L1, L2, L3 | 3 | 3.3uH | | Filter | Surface mount replacement: https://www.mouser.com/ProductDetail/Murata-Electronics/BLM18BD102SN1D?qs=h3IWXJJGQQWi4eZyJq6ScQ%3D%3D | Salvaged (DMG) |
| JACK | 1 | | | Headphone jack | | Salvaged (DMG) |
| R1, R2 | 2 | 1k | 0603 | Resistor | | [https://www.mouser.com/ProductDetail/YAGEO/RC0603FR-071KL?qs=VU8sRB4EgwApHsk4rF%2F3zg%3D%3D](https://www.mouser.com/ProductDetail/YAGEO/RC0603FR-071KL?qs=VU8sRB4EgwApHsk4rF%2F3zg%3D%3D) |

## Revision History

### v2.1 (for sale)

- Add surface mount pads for tantalum capacitors, size 1411 (3528 metric)

### v2.0

- Changed holes to slots where applicable
- Made board/part measurements more accurate
- Added pads for SMT inductors for L1-L3

### v1.2

- Tented a single via

### v1.1

- Release version

## Resources
-	<a href="https://gbdev.gg8.se/files/schematics/">Rolf, bit9, and nitro2k01’s DMG schematics and layouts</a>

## License
<br />This work is licensed under a <a rel="license" href="http://creativecommons.org/licenses/by-sa/4.0/">Creative Commons Attribution-ShareAlike 4.0 International License</a>. You are able to copy and redistribute the material in any medium or format, as well as remix, transform, or build upon the material for any purpose (even commercial) - but you **must** give appropriate credit, provide a link to the license, and indicate if any changes were made.

©MouseBiteLabs 2022

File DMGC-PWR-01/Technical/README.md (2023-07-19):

# Technical Design Document

This write-up serves as a technical explainer for the DMGC-PWR-01. This board is the powerhouse of the cell.

## Schematic and CPU Board Interfacing

There are five wires that connect to the CPU board power supply circuitry. Pin 1 is the GND reference and pin 2 is the 5 V output from the PWR board. Pin 4, VCC, is the input voltage, which is always powered from the CPU board. SW is the output of half the power switch on the CPU board - connected to VCC when on, floating when off (ultimately tied to GND through R16 on the PWR board). On the CPU board, pin 3 is connected to the DC jack output, but on this board I connect this to VCC as well, so that either batteries or the DC jack will power this board. A different revision might utilize the DC jack for something else, such as charging a LiPo battery, which is why I left these pins separate.



The battery voltage, VCC, is applied to the buck-boost input voltage pin, without routing through the power switch on the CPU. Instead, the power switch controls the buck-boost converter’s enable pin through a load switch circuit.

## Buck-Boost Converter (U2)

U2 can be TPS63070, TPS630701, or TPS630702. TPS630701 is a fixed 5 V buck-boost, while the other two have adjustable output via a voltage divider. The only difference between TPS63070 and TPS630702 is that the latter has an output discharge function - when the output is disabled, a low impedance (~200 Ω) is connected to the rail internally to quickly discharge the output capacitors. If you have a choice, I would recommend using the TPS630702 over the other two, and the TPS630701 over the TPS63070 just because it's a bit more convenient (and foolproof) to use the fixed output version of the chip. But any three of them will work perfectly fine.

The bottom third of the schematic is the entire buck-boost stage. I followed the TPS63070 datasheet for choosing values of the input and output capacitance, the inductor, and the feedback resistors. R8 and R9 set up a voltage divider for setting the output of the adjustable TPS630702 or TPS63070 – if the TPS630701 is used instead, which is the 5 V fixed output version, then R8 should be short circuited and R9 can be removed. **If you leave R8 and R9 at the values they are with the fixed 5 V chip, the output will shoot up to ~11V. I strongly recommend testing this power supply board separately from the rest of the system to ensure the 5 V output is correct and steady, without frying anything else downstream.**

The buck-boost chip is activated when the EN pin is higher than 800 mV (there is an internal ~70 microsecond delay before activation after this voltage is reached). This pin is controlled by the PSU_EN net, which is influenced by two chips – U3 (overvoltage protection) and U1 (undervoltage detection). If no errors are detected in the power supply, then PSU_EN will pull up to VCC_LATCH and activate U2. If either an overvoltage on the 5 V line or an undervoltage on the battery supply is detected, the PSU_EN net is pulled to GND and latched off until the power switch is cycled. R5, R12, and R13 set up voltage dividers that ensure if the EN pin passes 800 mV, the gate-source voltage on Q2 will be at least 2.4 V, meaning the latching circuit will be set up before the 5 V supply is generated (VGSth of Q2 is ~2.1 V, max). R13 also ensures the EN pin is pulled to GND when the power switch is turned off. Detailed operation on the PSU_EN net can be found below. 

F1 is a 1 A fuse on the 5 V output, which in hindsight is probably overkill, since the CPU board has protections that will likely always trip first (the 1 A PTC specifically). When testing the PWR board, I shorted the 5 V supply to GND to see if the fuse would pop, and the PTC opened up first every time I tried. But, I have plenty of 1 A fuses lying around, so there’s little reason not to include it just in case, since the TPS63070 chips can output up to 3.6 A. A fuse could prevent a feed-the-fault type of error, however rare that scenario likely is.

## Overvoltage Protection (U3)

Onto the protection circuitry - let's get the easy one out of the way first. U3 is a TPS3702 IC. This chip monitors the 5 V output on the SENSE pin. If it’s above a certain value, the output on the OV pin will be pulled low. Otherwise, OV is left floating (it's an open-drain output), so it doesn’t affect the output of the PSU_EN net during normal operation.

The specific part I have chosen is the TPS3702CX50. With the SET pin tied to GND, this sets the overvoltage threshold to 5.45 V. If the supply ever passes this point, then the overvoltage pin will pull PSU_EN low, and the latching circuit will keep it off until the power switch is cycled.

The overvoltage protection is likely overkill as well, as long as the buck-boost circuit is set up correctly and soldered properly. Since the adjustable TPS63070 chips measure the feedback through the FB pin, it will maintain the 5 V as long as no solder bridges or poor solder connections cause the wrong voltage to be measured by the chip (assuming the rest of the circuit is set up properly). You can omit U3, C9, and C10 to remove the overvoltage detection without impacting the operation of rest of the circuit.

## Undervoltage Detection (U1)

U1 is a TPS3840 chip which monitors the voltage on the batteries via the VDD pin. When it detects the voltage has gone below a specific threshold, the /RESET pin is pulled low. This output is open-drain, so it does not affect the PSU_EN net while not in an error state.

The specific part I chose was the TPS3840DL35. The DL indicates the /RESET is an active-low open-drain output. (PL would indicate active-low push-pull output, PH would indicate active-high push-pull, both of which aren’t suitable for my specific application). The threshold voltage is determined by the last two numbers, which for my selection is 35 for 3.5 V. I chose this threshold based on the guidelines from <a href="https://data.energizer.com/pdfs/nickelmetalhydride_appman.pdf">this application note from Energizer.</a> This documentation recommends using a voltage cutoff of ~75% of nominal voltage for a pack of NiMH AA batteries (what I will most commonly be using in my personal console). Nominal voltage of a NiMH AA battery is 1.2 V, so for four of them in series, the 75% level is 3.6 V. So the 3.5 V cutoff is close enough, and as a bonus, it's a part used on the CPU board already.

The VDD pin of U1 isn’t directly powered by the battery voltage. C1 and R7 on the battery voltage filter out any fast power supply transients. I found that during the start-up sequence, the loads on the 5 V supply will draw a considerable amount of current from the batteries, causing their voltage to dip about a volt max (this is normal, and the PTC on the CPU board does not drop the supply more than a few tens of millivolts). Furthermore, loud audio can introduce kHz range ripple on the battery voltage when their charge is low, so the low pass filter will smooth that out. It's not important for undervoltage lockout to occur immediately after the 3.5 V threhold is passed during a transient event, so this doesn't negatively impact performance or protection while the console is being used. Also, the current draw of the TPS3840 is less than a microamp, so the voltage drop across R7 is negligible and it also won't have any perceptible impact to battery life despite always being connected to the batteries.

The CT pin on this chip introduces a delayed start function. Adding a 1 uF capacitor to this pin will cause the /RESET output to be held low for approximately 620 milliseconds no matter what the supply voltage is. This is really only useful in the event you put the batteries in while the power switch is already on, because the delay only applies the first time power is applied to the chip. The wait period lets all the input capacitors charge up sufficiently and allows enough time for the input undervoltage latch to be set up before trying to generate the 5 V supply.

You might be asking - why am I including external input undervoltage detection on this board? Can't you just put a voltage divider on the enable pin of U2? Well...

## Latching Circuit

The original design of the PWR board had a funny problem, and didn't include the undervoltage lockout chip or latching circuitry. When the buck-boost enable pin was pulled low to disable the output once the batteries discharged enough, everything would turn off and thus remove the load from the batteries. When the current draw out of the batteries suddenly dropped to almost nothing, the battery voltage would rise back up, as expected. Unfortunately, this voltage would soon re-enable the buck-boost chip, starting up the 5 V supply. But... that would increase the load on the batteries, the voltage would drop below the enable pin threshold, and the system would shut off again. And that cycle would repeat. A bootloop! Not the graceful death the original Game Boy experienced when the batteries ran out of juice.

So in order to fix this, I introduced the undervoltage detection chip along with a latching circuit, so that as soon as the batteries died the *first* time, the system would keep itself shut off until the power switch was cycled. I found this strategy in <a href="https://www.ti.com/lit/an/snva836a/snva836a.pdf">this very helpful application note from Texas Instruments</a>. (You know, Texas Instruments should have sponsored this project, because I sure do use a lot of their parts)

The latching circuit consists of Q1 through Q4 and R1 through R4. You can read the application note for the full series of events, but basically turning on Q2 with a sufficient gate-source voltage sets up the latch. The next time the gate of Q2 (the PSU_EN net) is pulled to GND by the /RESET pin, Q4 is turned on to conduct and the /MR pin (master reset) is also pulled low. On the TPS3840, whenever /MR is low, /RESET will also automatically be pulled low no matter if VCC is above or below the undervoltage trip point. So even if the voltage rises back up above the trip limit, /RESET will keep Q4 conducting, which keeps /MR low as well. So the only way to reset the whole thing is to turn the power switch off and reset the latch.

## Load Switch

VCC is applied to the latching circuit through a load switch circuit, rather than the power switch directly. The power switch, which is connected to the SW net, controls the gate-source voltage of Q5, an N-channel FET. R15 and C11 set up an RC delay for switch debouncing, and R16 is a pull-down resistor for when the power switch is turned off. R14 is a pull-up resistor that keeps Q6, a P-channel FET, off whenever Q5 is off. When the power switch is turned on, Q5 conducts and pulls the gate of Q6 to GND. This allows the battery voltage VCC to turn on the latching circuit. Furthermore, if PSU_EN is not being pulled to GND by the supervisory ICs (if the battery voltage is higher than 3.5 V), then the enable pin of the buck-boost will pass the 800 mV threshold needed to turn on the 5 V supply (after a built-in 70 microsecond delay).

The benefit to using a load switch instead of the power switch directly is the contact resistance of the 30+ year old power switches is no longer a factor in operation. One common issue in old Game Boys is a voltage drop across a dirty power switch, because the entire system current flows through the switch. Sometimes, if the switch is particularly oxidized or dirty, the entire Game Boy could fail to turn on. Instead of having to clean out a power switch, a non-trivial task (especially for a DMG), a dirty power switch will still be able to properly control Q5, as long as contact resistance isn't higher than like, 100 kΩ. (And in that case, increase R16 to like 1 MΩ, and you might be ok!)

## Resources
-	<a href="https://www.ti.com/lit/ds/symlink/tps63070.pdf?ts=1647052355945">TPS63070 datasheet</a>
-	<a href="https://www.ti.com/lit/ds/symlink/tps3840.pdf?ts=1656386735143">TPS3840 datasheet</a>
-	<a href="https://www.ti.com/lit/ds/symlink/tps3702.pdf?ts=1656335717520">TPS3702 datasheet</a>
-	<a href="https://www.ti.com/lit/an/snva836a/snva836a.pdf">Latching a Voltage Supervisor Application Note</a>
-	<a href="https://data.energizer.com/pdfs/nickelmetalhydride_appman.pdf">Nickel Metal Hydride (NiMH) Handbook and Application Manual</a>

## License
<br />This work is licensed under a <a rel="license" href="http://creativecommons.org/licenses/by-sa/4.0/">Creative Commons Attribution-ShareAlike 4.0 International License</a>. You are able to copy and redistribute the material in any medium or format, as well as remix, transform, or build upon the material for any purpose (even commercial) - but you **must** give appropriate credit, provide a link to the license, and indicate if any changes were made.

©MouseBiteLabs 2022

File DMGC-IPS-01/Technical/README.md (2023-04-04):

# Technical Design Document

This write-up serves as a technical explainer for the DMGC-IPS-01. This board is mainly responsible for user interface.

## FFC Connectors
There are two FFC connectors on the board - one to take the input from the CPU board, the other is for the Q5 board to connect to. The former is detailed in the CPU board section, and the latter simply omits a few pins to connect to the Q5 board, such as the speaker and button inputs. Notably, the connector going to the CPU board must be reversed due to the FFC cable connecting it to the CPU board.



## Speaker
I detail the operation of the audio amplifier on the CPU board in that corresponding README. I mention that a DC blocking capacitor needs to be included in series with the speaker output. That’s what C3 is for, a 100 uF capacitor. There are two capacitors called out as C3 – a space for an aluminum electrolytic capacitor, and one for an electrolytic tantalum (or other surface mount varieties - do you fancy yourself a film cap?). The surface mount pad is size 3528, sized up for compatibility with many different types of SMT capacitor sizes. If you install the through-hole electrolytic, bend it down into the notch on the board. I have a ton of aluminums and they’re cheaper, so that’s the one I used. The speaker itself is an aftermarket FunnyPlaying model.



## Power LED and Dimming Circuit
The power LED is a standard 3mm red LED. For low power detection, I used a simple Schmitt trigger circuit.



When the power switch on the CPU board is turned on, the input to the buffer (U1B) is half the battery voltage, from the voltage divider made from R11 and R12 (C6 is for noise filtering purposes). This output is connected to the Q5 board's BATT solder pad for battery level indication. Since the Q5 kit expects a GBC battery voltage, which uses 2x AA batteries, cutting the 4x AA battery voltage in half will scale it properly. The Q5 board itself uses a voltage divider for scaling the battery voltage, so the voltage on the BATT pad must be from a low impedance source so as not to ruin the scaling factor - therefore, it must come off of the op-amp output itself, rather than the voltage divider.

The ½ battery voltage is then cut in half again via the voltage divider made by R6 and R7. The ¼ battery voltage is compared with the inverting input on the other half of U1. R3 provides hysteresis on the comparator circuit (i.e. Schmitt trigger), and C7 and C8 are for noise filtering (can likely be omitted). When the combined voltage of the 4x AAs drops below ~4.35 V, the battery level is considered low and the LED will noticeably dim. My testing came up with this voltage as approximately 30 to 45 minutes of playtime left if at max brightness with headphones in, testing from fully charged batteries.

The output of the op-amp is set at 5 V when the battery level is high, which turns on Q1; it is driven to GND when the battery level is low, which turns Q1 off. Therefore, the brightness of the LED during normal power is dictated only by the resistance of R1. When the combined battery voltage drops below the low battery threshold, R2 is placed in series with the LED as well, which dims the LED. I played around with these values to find ones that didn't burn my retinas for normal brightness, and produced a noticeably dimmed power LED when the low voltage detection is tripped.

## Navigation Switch
This takes place where the contrast wheel used to be. On the Q5 board, there are two capacitive touch sensors - one for changing brightness, one for changing the color palette. Instead of using the touch sensors in the DMGC, the navigation switch will toggle these inputs by connecting a series capacitance to ground to simulate a touch. This also has the benefit of not having to modify the driver board in any way, and instead just requiring soldered wires to the board where capacitive sensors were connected.



Rocking up on the dial will toggle the brightness setting, rocking it down will toggle the color palette setting. Rocking up and holding it will toggle the battery level display on the screen, and rocking it down and holding it will toggle the pixel grid. Pushing in on the switch grounds the ATTINY85's PB3 pin (which is pulled up externally to 3.3V), if installed. Using the code I provide in the main IPS folder, pushing in will advance to the next color of the button LEDs, and holding it while pressing left or right on the D-pad will change the brightness of the LEDs.

## Q5 Board Pads
There are six test points at the top of the IPS board for short wires to connect to the Q5 board. The Q5 board includes pads for the select, B, and A buttons for navigation in the OSD. There's also a battery pad, which is for measuring the battery life, as mentioned. And finally, there are two pads for brightness control and color palette swapping, which connect to the capacitive touch sensor inputs on the Q5 board. Before installation, stripped wires should be soldered to these corresponding pads on the Q5 board, so they may be soldered to the IPS board after assembly.



## Button LEDs and ATTINY85
One popular feature for Game Boy mods are backlit buttons. On the front PCB I included spaces for eight WS2812B-2020 RGB LEDs. These are controlled via an ATTINY85 with the Adafruit NeoPixel library. You can program the ATTINY in any number of ways, but I added pads for <a href="https://www.mouser.com/ProductDetail/200-TSM10601TSH">kinked header pins</a> to hopefully make it a bit easier. You may want to tape off these pins with kapton tape, but they should not interfere with any component on the CPU board when assembled if installed correctly.



There are nine color settings - red, orange, yellow, green, cyan, blue, purple, white, and off. These settings can be changed in the code (or additional settings could be appended) by changing the RGB values in the arrays. Pushing in on the navigation switch will toggle between these settings. Pushing and holding it in, and then pressing left or right will change the brightness of the LEDs. The settings are saved every time the brightness or color is changed, and will be reloaded when turning on the Game Boy. This feature was inspired by NiceMitch's RGB LED flex PCB for GBC.

Code for the ATTINY85 is located in the main IPS folder, however because I wrote this months ago (and forgot to comment it sufficiently...) I have forgotten how some of the code actually works. There's certainly room for improvement (and some really dumb inclusions). But there *is* a nice startup effect to match the Game Boy Color boot sequence that a friend (jokingly) suggested I include. *Are you happy, Mike?*

*NOTE: If you are programming the ATTINY after it is already soldered to the IPS board, be sure to disconnect the ribbon cable going to the CPU board and the ribbon cable going to the Q5 kit.*

If you hold the navigation switch in as you turn on the console, the LEDs will be disabled until power is cycled. (This is probably more for my benefit as I used it while testing very discharged batteries to skip the start-up LED sequence)

Always-on discrete LEDs are also an option - an 0603 LED will fit on half of the 4-pin RGB LED pads, from VDD to DO. The pads for this are indicated by the arrows. The picture below shows which pads to use for discrete LEDs (view of the D-pad) - the A indicates the anode of the diode. There are spaces for a resistor for each LED on the back of the board (R22 to R29, circled in red below). If you're using the RGB LEDs, or no LEDs at all, the resistors aren't necessary.



## Q5 IPS Screen Bracket
I designed a bracket for holding the screen in place. This is placed between the screen and the DMGC-IPS-01 board. The model is available for download in the main IPS board folder. <a href="https://funnyplaying.com/products/dmg-retro-pixel-ips-lcd-holder">It is similar to Funnyplaying's model.</a>



## Resources
-	<a href="https://gbdev.gg8.se/files/schematics/">Rolf, bit9, and nitro2k01’s DMG schematics and layouts</a>
-	<a href="https://learn.adafruit.com/adafruit-neopixel-uberguide/downloads">Adafruit NeoPixel Resources</a>
-	<a href="https://github.com/HandHeldLegend/gbc-rgb-led-2.0">NiceMitch’s RGB LED flex PCB for GBC</a>
-	<a href="https://www.instructables.com/How-to-Burn-ATTiny85-Using-Arduino-Mega/">Instructables post for programming an ATTINY85 with an Arduino</a>

## License
<br />This work is licensed under a <a rel="license" href="http://creativecommons.org/licenses/by-sa/4.0/">Creative Commons Attribution-ShareAlike 4.0 International License</a>. You are able to copy and redistribute the material in any medium or format, as well as remix, transform, or build upon the material for any purpose (even commercial) - but you **must** give appropriate credit, provide a link to the license, and indicate if any changes were made.

©MouseBiteLabs 2022

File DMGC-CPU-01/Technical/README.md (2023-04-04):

# Technical Design Document

This write-up serves as a technical explainer for the DMGC-CPU-01. This board houses the CPU and all associated main functions of the DMGC.

## Power Supply
The majority of the crucial power supply circuitry is on the PWR board, but the CPU board still has some portion of power supply interfacing. 



(I know the symbols for the fuses and filters are incorrect. I needed an 0603 package for the board and was too lazy to assign the parts the correct symbols. But I guess technically… they are all resistors in some form.)

-	As mentioned on the main README, the DMGC uses the power switch to control the enable pin on the converters on the PWR board. Therefore, the battery voltage is always connected to the PWR board converter inputs. This way, system current does not pass through the switch, which can be dirty or oxidized and introduce unwanted voltage drops at higher currents.
-	A downside of connecting the batteries directly to the input of the converter – as soon as the last battery completes the circuit by touching the terminals, the input capacitance is immediately charged up. This causes a considerably large inrush current – up to about 2 A by my measurements. In order to limit this inrush current, I utilize PTC1, a Polyswitch. This is a resettable overcurrent protection device. As current reaches 1 A, the resistance of the PTC will increase until power to the console is essentially cut off. For short bursts, like for the inrush current from the batteries, the resistance will quickly return to its normally low value. Nominal operation of the DMGC should only see currents up to 250 mA at worst cases - meaning the voltage drop across the PTC under normal operation will be negligible.
-	Furthermore, because the batteries are always connected to at least some of the system, the current draw while the switch is off must be as small as possible to reduce the amount of quiescent current that would drain the batteries. Only capacitors and high impedance loads are therefore connected to the VCC line on the CPU and PWR boards.
-	Because there is still a risk of the batteries being short circuited before reaching the PTC on the board, the positive battery terminal is immediately followed by a ~2.5 amp fuse to open the circuit if the batteries are accidentally short circuited. Also, F2 is in series with the output of the DC jack to protect from overcurrents if batteries aren’t being used to power the console.
-	Pins 3 and 4 on the DC jack are normally closed when the AC adapter is not plugged in, and open when it is plugged in. This ensures the batteries and AC adapter cannot power the Game Boy simultaneously, and prevent accidental backfeeding into the opposing power source.
-	Q1 is a P-channel FET used for reverse polarity protection. This is more efficient than a series diode because while the P-FET is conducting, there is a much smaller voltage drop than if a diode was being used. D1 is reverse polarity protection for the DC jack input, where efficiency is much less important than running on batteries. 
-	R1 connects to the 5 V rail when the power switch is turned off, ensuring quick discharge and reducing the chance of strange operation during a slower power down.
-	U4 is a simple linear regulator for generating the 3.3 V supply necessary for the RAM and the CPU core. I considered using a SMPS instead, but the current requirements are so low, it seemed slightly overkill.
-	The filters (EM6, 7, 8, and 10) are likely fine to exclude, but it doesn't hurt to include them just in case some weird high frequency components have the potential to screw something up down the line. I don't really have the capability (or desire) to properly test what effects removing them may have, but I suspect they're mostly for FCC compliance.
-	Finally, there are five wires leading from the CPU board to the PWR board – VCC (battery voltage), SW (battery voltage after switch), DC (input from the DC jack), 5V (supply from the PWR board), and a GND reference. I also added test points for each of the three voltages as well for troubleshooting purposes.

## FFC Connector

For this build, as mentioned, I'm using the GBC Q5 XL IPS Backlight with OSD kit. It comes with a separate circuit board to properly drive the IPS screen (which I’m henceforth calling the “Q5 board”). In order to determine which pins were necessary for the Q5 board, I looked at the cable connected to the board and noted which traces actually go somewhere. The pins in red are unused, the ones in blue are used. The pin names are from the GBC schematic. Some of the unused pins are used for other functions on the connector to connect to the IPS board.



-	Pin 1 and 2 are connected to the output of the power switch. This is sent to the IPS board, which uses it for battery level detection to control the brightness of the power LED, and has a pad for connection to the OSD kit (after a voltage divider). As the kit is for the GBC, cutting the battery voltage in half simulates 2x AA batteries like the GBC uses.
-	Pins 33 and 34 are used for GND. This just reduces the current through one individual pin on the FFC connector. Probably not necessary, but who knows. Maybe you'd want to put bluetooth or Wi-Fi or a media server on the front display board, I'm not your dad.
-	Pins 38 and 39 are similarly doubled up for the 5 V supply. I wanted to keep some empty space around these pins to reduce the likelihood of shorting something to the power rail when soldering the FCC connector on, specifically the buttons (which are referenced to the 3.3 V supply in the CPU).
-	Pins 41 to 48 are used for the face buttons.
-	Pins 49 and 50 are for the speaker.
-	TEST1 is used for GND on this cable, but I kept the ground connection to just a few pins to reduce the chance for ground loops between the CPU and IPS boards. But on the IPS board connector to the Q5 board, this TEST1 pin is connected to GND.
-   Pin 4 connects to a test pad called PUSH. This pad connects to the rocker switch on the IPS board through the FFC, specifically the push-in function of the rocker switch. You can use this for all sorts of shenanigans if you want to try being clever with it.
-	The CLS and LP pins aren’t used by this kit, but is by another kit that is potentially usable.

## Audio Amplifier
The new audio driver on the CPU board is powered by the LM4853. This TI chip is perfectly suited for the Game Boy - it has stereo inputs and headphone outputs, and mono speaker output. Makes it quite easy to implement without extra circuitry shenanigans.



-	The four outputs on the right are for the DMGC-HDP board. (This board has the DC blocking capacitors needed for the headphones)
-	The headphone detect pin (HP_SWITCH) is connected to GND when the headphone jack is empty, and is pulled up to 5 V via R36 when headphones are inserted. This switches the output on the audio amplifier between the speakers and headphones. C51 is for debouncing the headphone detection.
-	C18/C19 are DC blocking capacitors and RA1A/RA1B are current limiting resistors, so when the volume is turned all the way down, the S01 and S02 pins aren’t overloaded.
-	C52/C53 are DC blocking capacitors so only the AC audio signal passes to the amplifier.
-	The ratio of R30/R31 and R32/R33 set the amplification of the audio amp - increase R30 and R32 to decrease the output volume.
    - The audio gain has quite a large effect on the power draw of the system when using the speaker. I did not do any tests with an audio gain greater than ~0.6. A sufficiently larger gain than this will drain batteries faster if the volume is turned up.
-	The shutdown pin should be tied to GND to allow the amp to work. I made two different revisions that tied this to 5 V instead. Oops. (The output on the headphones will sound really quiet and the speaker won't work if the chip is shutdown)
-	The speaker output *shouldn't* need a DC blocking capacitor, as the LM4853 outputs to the speaker as a bridge tied load (BTL). However, I found that if a DC blocking capacitor is not included, a strange issue is possible in specific situations. There’s a very brief moment when plugging the headphones in where the right output channel is shorted to ground (ring and sleeve are connected inside the jack). When this happens, the right output DC blocking cap is connected to GND, and causes a large surge of current from the power supply to charge it up. In my testing, this sometimes would cause a brownout, causing the power supply to shut off. So I have included a spot for one of these caps in series with the speaker on the IPS board.
-	Added in version 2.0, opposite of the regular headphone outputs, are another set of audio outputs that are completely optional. These are denoted as "pre-pot audio," and include a left, right, and ground connection. The left and right connect directly to the VR1-S01 and VR1-S02 nets, which allows you to grab the audio unfiltered, unamplified, right from the GBC CPU (through a protection resistor/capacitor combo). This is colloquailly known as the "pro-sound" mod, and is typically used in conjunction with a *second* audio jack. Audiophiles like to use this raw output with their audio equipment (note that using the pro-sound output as input to an external amplifier does not disable the speaker or headphones - the potentiometer still controls volume for those audio outputs). You could use this jack for headphones if you want (and it will disable the speaker), but it will always be one volume - about as loud as the original GBC at max volume. The audio coming out of these pins does sound incredibly clean - check out the recordings in the root folder. 

## CPU Reset
The last major change to the CPU board is the reset IC. I’ve replaced the original PST9135N with a TPS3840DL35. These chips pull the /RESET pin on the CPU low when the voltage supply drops below 3.5 V (/RESET set to low turns off the CPU). The TPS3840DL35 does the same thing. The reason this chip is included is to hold the CPU off while powering down so no random instructions are made while the game is turning off.

R3 and C17 introduces a time delay on the /RESET pin during start-up, to allow the rest of the power supplies to stabilize before letting the CPU operate. This is called a "power-on reset" circuit, and I used values that the original GBC schematic used. (The DMG, GBC, and GBA all use the same odd 18 ms time constant!)

As described in the main CPU README, you can modify the board to manually reset the DMGC by pulling the /RESET pin to GND with the rocker switch.



## Resources
-	<a href="https://console5.com/techwiki/images/e/e6/Nintendo_GBC_Schematic.png">GBC schematic</a>
-	<a href="https://gbdev.gg8.se/files/schematics/">Rolf, bit9, and nitro2k01’s DMG schematics and layouts</a>
-	<a href="https://www.ti.com/lit/ds/symlink/lm4853.pdf?ts=1656384256966&ref_url=https%253A%252F%252Fwww.google.com%252F">LM4853 datasheet</a>
-	<a href="https://www.youtube.com/watch?v=IrB-FPcv1Dc&ab_channel=Afrotechmods">Reverse polarity protection explanation</a>

## License
<br />This work is licensed under a <a rel="license" href="http://creativecommons.org/licenses/by-sa/4.0/">Creative Commons Attribution-ShareAlike 4.0 International License</a>. You are able to copy and redistribute the material in any medium or format, as well as remix, transform, or build upon the material for any purpose (even commercial) - but you **must** give appropriate credit, provide a link to the license, and indicate if any changes were made.

©MouseBiteLabs 2022

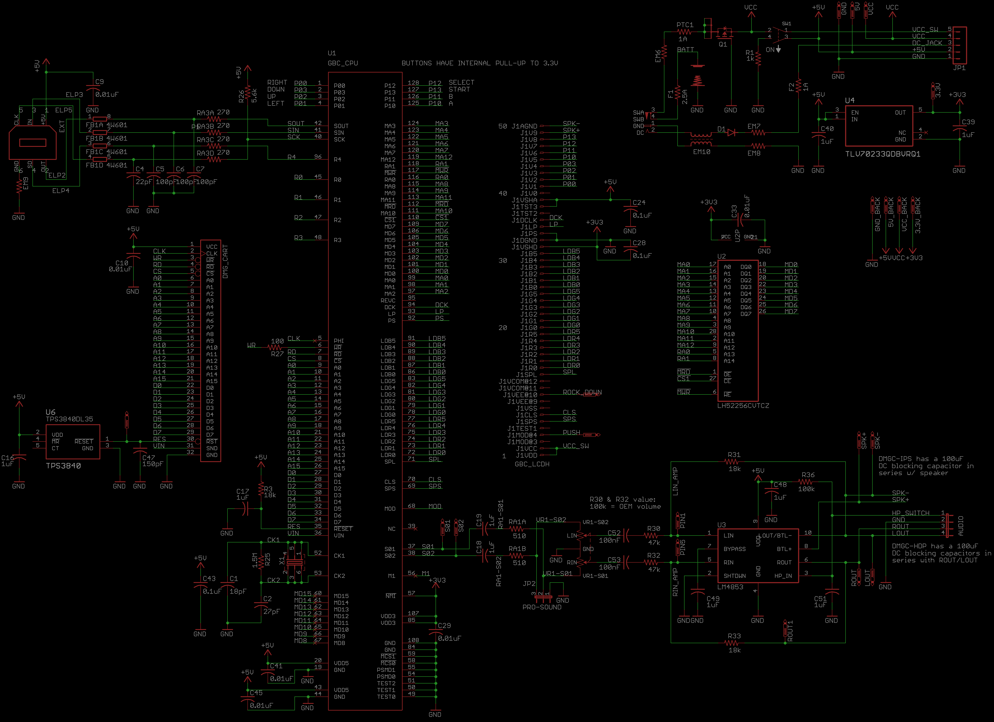
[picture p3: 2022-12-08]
DMGC-CPU-01/Technical/schematic.png

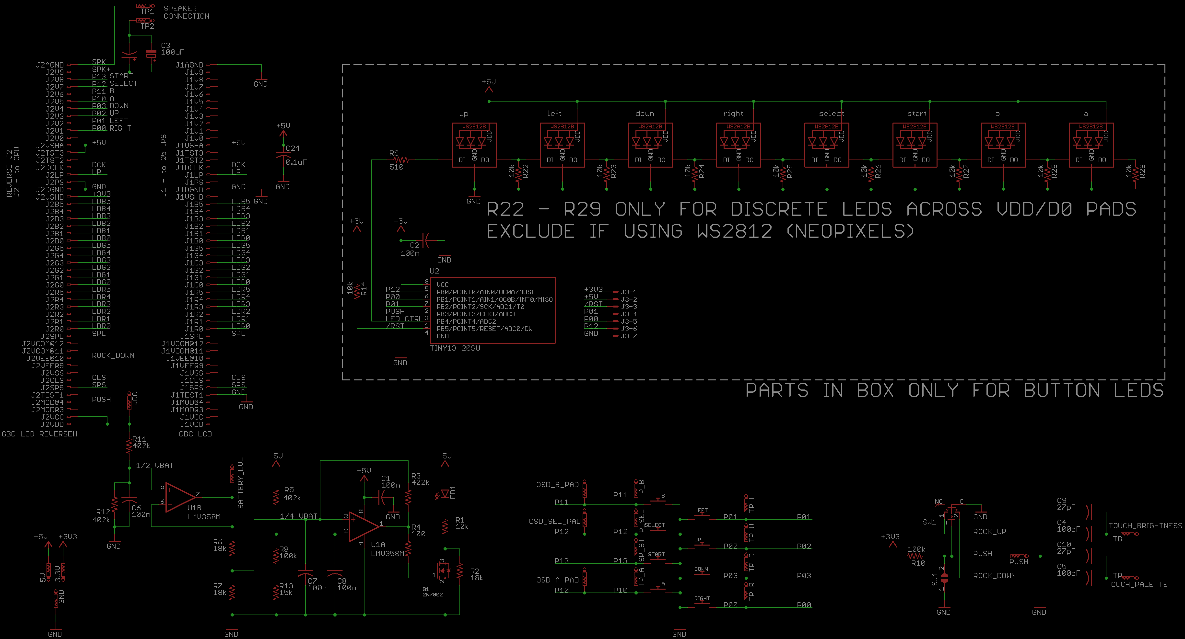
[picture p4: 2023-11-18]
DMGC-IPS-01/schematic.png

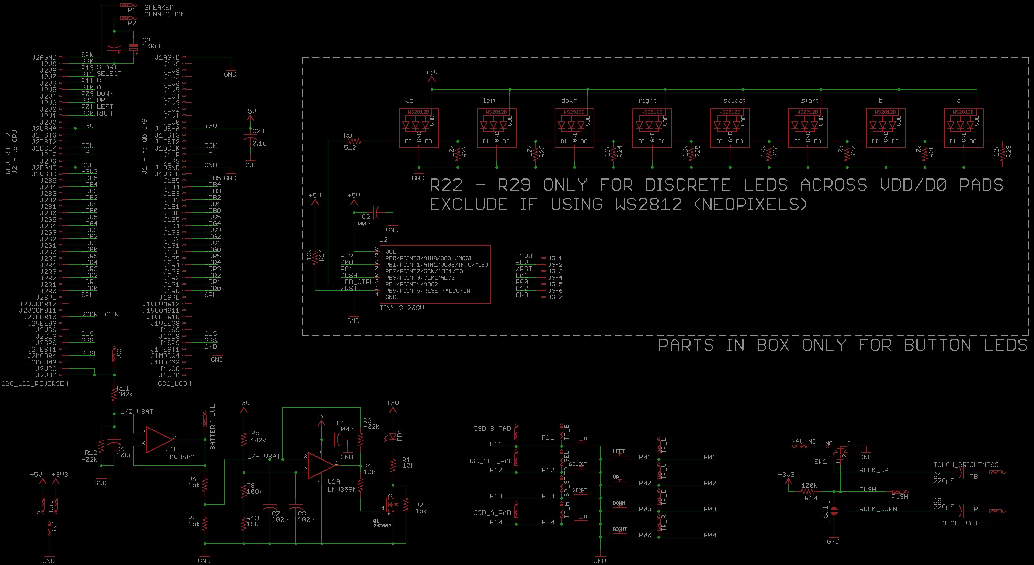
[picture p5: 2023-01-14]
DMGC-IPS-01/Technical/schematic.png

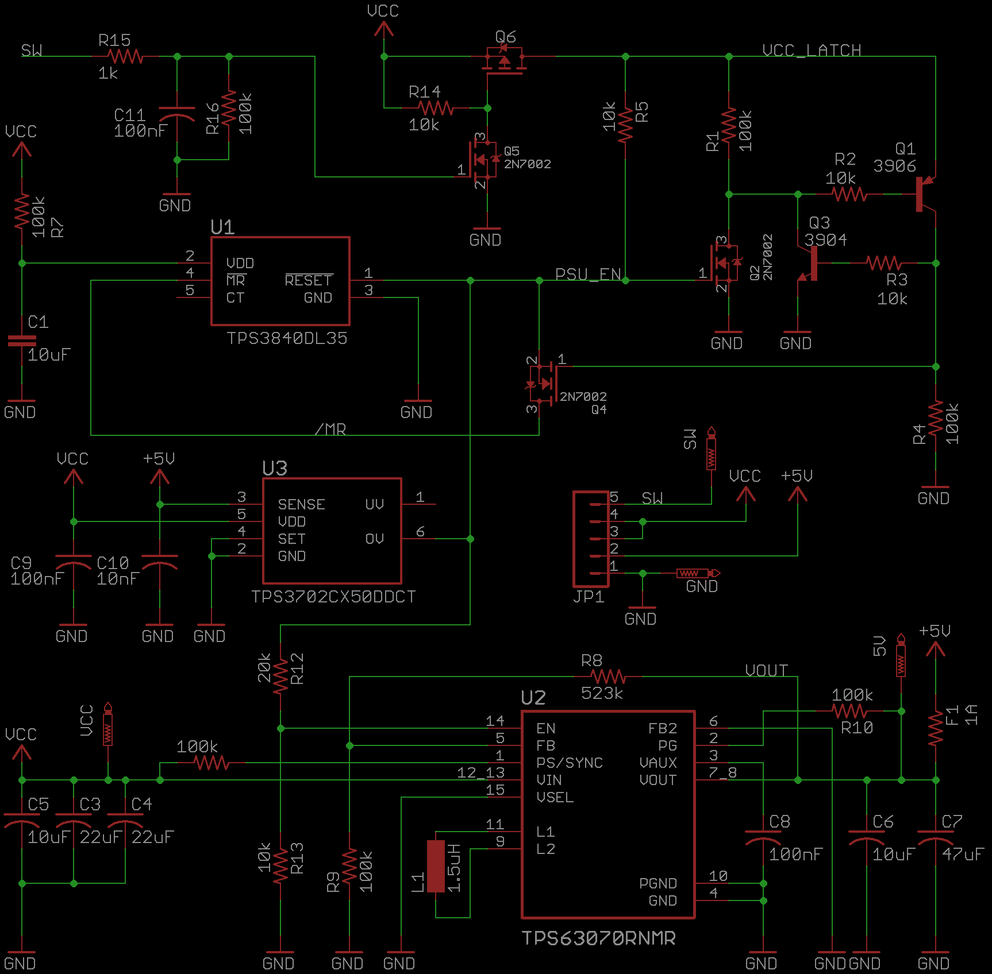
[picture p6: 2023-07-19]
DMGC-PWR-01/Technical/schematic_2-3.png

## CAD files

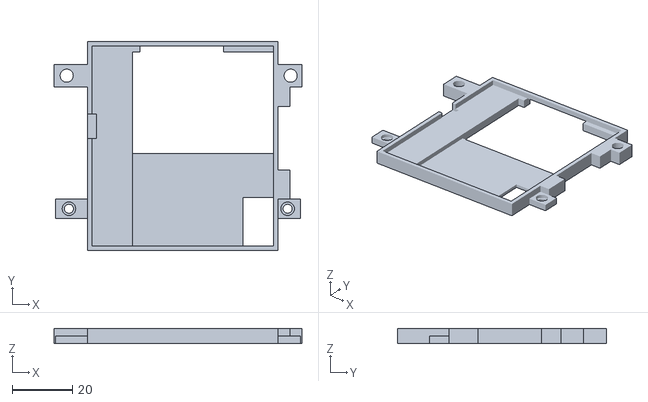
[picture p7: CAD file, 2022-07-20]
DMGC-IPS-01/dmgc_q5_bracket.stl
82.0 x 69.0 x 5.00

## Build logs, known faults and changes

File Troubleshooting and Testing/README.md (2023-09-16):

# Troubleshooting and Testing

Here is where I will collect some troubleshooting advice. I may expand the sections as time goes on for specific board troubleshooting advice. For now, this should cover most issues.

## Suggested Testing Before Final Assembly

This is the order of testing I usually go in when assembling a DMGC. I recommend testing boards as you go *before* you completely connect everything together and put into the DMG shell. This way you can easily catch errors early on, making troubleshooting easier, and lowering the chance for catastrophic mistakes. I'm not going to give detailed troubleshooting instructions here, just some general tips, mostly for catching power issues. This should cover the most common issues.

*If you're taking on this project in the first place, I expect you'll be able to take troubleshooting further than what I detail here ;D*

### 1) Testing the output of the power switch

First, you should populate the following parts on the CPU board:



Then, if you place the CPU board (by itself) in the DMG shell and insert batteries, you can check the voltage with a multimeter on the VCC pad and SW hole that go to the PWR board. If you are testing with an A/C adapter, then you'll only be able to measure the voltage on the DC pin, so test with batteries first. 

VCC should *always* read the battery voltage, and SW should read zero when the power switch is off, and the same voltage as VCC when the power switch is on.

If VCC does not read any voltage, measure the voltage right at the battery terminals and check if it's zero there as well - sometimes using NiMH batteries in DMG shells causes poor contact with the battery tabs, because some NiMH batteries have shallower positive terminals than alkalines. If you get voltage at the terminals, then check all the parts in line between the battery tab and the VCC net in the diagram.

- Check if F1 is blown.
- Check Q1 orientation.
- Check EM10 orientation. (Check with a meter in continuity mode if the top two pins are connected, and if the bottom two pins are connected - the ones connected by a horizontal line are the ones that should show connectivity).
- Check if pins 3 and 4 on the DC jack are connected. If they are not, then the switch is likely dirty, corroded, or damaged somehow. If you don't want to use the DC jack, you can connect pins 3 and 4 together with a wire.
- If you are testing voltages by using an A/C adapter plugged into the DC jack, make sure D1 is in the correct orientation and F2 isn't blown.

If SW doesn't read a voltage with the switch on, your power switch is potentially damaged or too dirty/oxidized.

If you want to test the power board by itself without the CPU board, use this set up to test.



You need to switch voltage onto the SW pin - you cannot short SW to the input power and start up the board. Doing so will activate the undervoltage lockout, and it'll appear that the board does not work.

### 2) Testing DMGC-PWR-01

*This step assumes you have the correct voltages on VCC and SW from step 1.*

This step will test the 5 V output of the PWR board. Connect the PWR board to the CPU board with the requisite five wires (they should measure ~2.25"), but remove the 5 V wire from the CPU board side. This way, you can apply the input voltage (battery or DC jack) to the PWR board without powering the rest of the CPU board.
Place the CPU board in the back DMG shell and insert batteries, or use the DC jack input. Turn the power switch on, and check with a multimeter that the 5 V wire indeed reads 5 V.

If you get something else, check these things:
- Check for good solder joints on all parts.
- Check the orientation of Q6. Pins 1, 2, 5, and 6 should all have continuity, and should not have continuity with pins 3 and 4. It's a small part with hard to read markings, so it might be backwards.
- Are you using TPS630701? If you are, make sure you have shorted R8 with a solder bridge, and didn't actually include a resistor there. You also don't need R9 in the circuit, but it won't hurt to include it. If you don't short R8 and you use the TPS630701, your output will shoot past 5 V.
- Check the resistance across R9, or the pads of R9. If it's short circuited, that means you likely have a solder bridge from U2's feedback pin to GND (which would cause the output to shoot higher than 5 V). Also check for continuity across R13. If it's shorted, that means you have shorted the enable pin to GND, which will always keep U2 off.
	- Generally, U2 is usually at the heart of most problems, at least as far as I've seen. It's a difficult chip to solder properly. If you detect any shorts, reflow U2 with flux, or consider removing it completely and resoldering it.
- If you don't have a short across R8 or R9 and you're using the TPS63070 or TPS630702, check the resistance values of these resistors. If they are wrong, you can get the incorrect voltage on the 5V output.
- Check the orientation of U3. Also, if it's easy to do, try removing U3 completely and checking the output again with the power switch on. If the output now reads *above* 5 V, then double check R8 and R9 mentioned earlier.

### 3) Testing DMGC-CPU-01

*This step assumes you have a stable 5 V coming out of the PWR board.*

First, without the batteries or DC jack inserted, do a resistance check on the 5 V pad on the CPU board to GND. When the power switch is off, it should read 1 kΩ. When the power switch is on, you should get a higher resistance, tens or hundreds of kΩ. If you get a very low resistance in either position, you have a short circuit somewhere on the CPU board, and the PWR board will shut off. If you don't have that issue, connect the 5 V wire to the CPU board.

**NOTE: Trim all five wire stubs poking out of the CPU board holes so they are flush against the CPU board after soldering them in. If the stubs stick out too far, they can touch the IPS board's navigation dial metal shielding and short circuit.**

Turn power on, and do a voltage check on the CPU board's 5 V pad and 3.3 V pad to verify you're getting 5 V and 3.3 V, respectively. If you don't, this could point to a solder bridge somewhere on the CPU board, or a dead part. (Hopefully it's not your CPU!)

### 4) Testing operation of the IPS kit

*This step assumes you have a stable 5 V and 3.3 V supply on the CPU board.*

Before testing anything, if you have a stock Game Boy Color, consider testing the kit in that before using it here. These kits can come defective.

Did you know you can connect the Q5 IPS kit to the CPU board directly, without the DMGC-IPS-01? Well, you can, at least at the time of writing. Plug it into the FFC connector, J1, and make sure no metallic surface is shorting between the kit's board or the back of the display and the CPU board. Turn power on, and you should get the GBC splash screen.

You can test a game at this point too. If you put a game in the cart slot, it should start to run normally. If you get a garbled logo, or it otherwise doesn't start up properly, then you might have a dirty cart slot or poor connection from the cart connector to the CPU.

If the screen doesn't turn on at all - no backlight or anything - check to make sure your 5 V output is still at 5 V. If it's not, then turn off power, remove the screen kit, and test again to see if the 5 V output comes back. Again, if you have a working GBC to test with, you should check to see if the kit does the same thing there.

If you get a garbled image, or no image at all (but the screen still lights up), check these things:

- Make sure the bales of the FFC connectors are in all the way, and the cable is seated all the way in. Try to clean out any flux that might be hiding inside the connector.
- Check for solder bridges on all the pins of the CPU, FFC connector, and RAM. *Note that some adjacent pins are supposed to be connected together on the FFC connector - check the schematic.*
- Check to make sure all legs of the CPU, FFC, and RAM have a good connection to the board. Missing any one of these pins could cause the screen to not work.
- Once again, try the IPS kit inside an actual Game Boy Color, if you have one available to test.

If you have an image on the screen, but it has odd colors, or freezes, or something else, check the section at the bottom of this post for information on specific troubleshooting tips for the CPU and RAM.

If you still have problems with the IPS kit not working properly, you can continue to step 5 to check the audio output. This might point you to a problem elsewhere on the CPU board.

### 5) Testing DMGC-HDP-01 and audio output

*This step assumes you have a stable 5 V and 3.3 V supply on the CPU board.*

As mentioned in the previous step, you can check this without a screen kit installed. **If you do not include the screen kit, the audio will likely sound a bit distorted. This is normal.**

Connect the headphone board to the CPU board with the four requisite wires (they should measure ~2.6"). Then, you can plug in headphones to the headphone jack to see if the CPU is operating normally. Make sure the volume dial isn't turned all the way down. If you're unsure which way turns the volume up, just put it somewhere in the middle.

When you turn the power on, you should hear the GBC start-up chime. If you don't:

- Do a resistance check between the HP and GND pins on the audio board (or on the connections on the CPU board). When headphones are removed, you should read a short circuit. When headphones are plugged in, you shouldn't - you can read anywhere from 1 kΩ to something higher (depending on the type of headphone board you're using). If this check fails, you likely have a dirty or damaged headphone jack (especially if it's a salvaged DMG jack).
- Check the resistances of the volume dial pins.
	- Check the resistance between pins VR1-S01 and RIN, and then again for VR1-S02 and LIN. You should read a resistance between 0 and 10 kΩ depending on where the volume dial is. Reading 0 ohms means maximum volume, 10 kΩ is minimum volume.
	- Check the resistance from VR1-S01 to GND, and VR1-S02 to GND. This should be 10 kΩ.
	- Getting any resistance higher than 10 kΩ means you have a damaged or dirty volume dial.
- Check your soldering around U3 on the CPU board, and make sure all the correct parts are included and placed in the right positions.
- Check to make sure there are no solder bridges on the CPU or anywhere else on the CPU board, and make sure there are solid connections on each leg of the CPU to the board. Some crucial pins may be lifted.
- If you have the parts, you can check the audio out of the pro-sound output. If you get sound out of the pro-sound outputs, but not the regular headphone outputs, then you have an issue somewhere between the CPU and the headphone board. Follow the schematic to troubleshoot.
- You can solder a DMG speaker, in series with a 100 uF capacitor, to the back of the DMG board (pads SPK+ and SPK-). Make sure HP is connected to GND. You should get audio out of the speaker this way.

If you can't get an image on the IPS screen, and you also still cannot get audio output from the headphone jack, then you likely have some kind of issue with the CPU - not necessarily a dead CPU, but something that affects it, like a solder bridge, lifted pin, wrong part value, or a damaged part.

### 6) Testing DMGC-IPS-01

*This step assumes the IPS kit works on the CPU board.*

At this point, you have the majority of systems tested on the build. The IPS board doesn't have much else to test. Note that when testing the IPS board outside of the shell, you *need to make sure you aren't short circuiting anything between the IPS and CPU boards.* So if you're going to place the board on top of the CPU board for testing, make sure you put a piece of paper or non-conductive material between the boards. Or, just keep the IPS board off of the CPU board.

Make sure the power LED turns on when you turn the power on (did you put it in backwards?) and make sure you get a good image on the screen kit. If the image appears garbled, or doesn't appear at all, do the checks I mentioned in the CPU board troubleshooting sections:

- Check for any solder bridges on the two FFC connectors. When checking for shorts, some adjacent pins on the connectors are supposed to be connected - check the schematic. 
- Check for any lifted pins or poor solder joints on the FFC connector pins. The connectors themselves sometimes have the pins lifted a bit when you place them on the board, so you might have to bend them down a bit before soldering. You can even check for continuity from the pin to the board using a meter - it's small and tight, but can be helpful.
- Make sure the cables are inserted in the connectors all the way and the bales are pressed in all the way. Clean out any leftover flux that might be inside the connectors when you soldered them on.

At this point you should also have the speaker installed. If after turning the system on, you don't get any sound, check the HP and GND pins on the headphone board or CPU board - the HP pin should be shorted to GND when headphones are not inserted. If the HP pin is not shorted to GND, then the speaker won't output any sound. You have a dirty or damaged headphone jack - clean or replace. You can manually short HP to GND with a wire to check the audio output of the speaker if you'd like.

## Troubleshooting Common Issues Related to CPU and RAM

Depending on the problem you're encountering, it could be worth reflowing the pins on the CPU that correspond to the aspect you're having problems with.
- For miscolored screens, reflow the top display pins.
- For *glitchy* screens, or frozen/all-white screens, reflow the SRAM pins.
- If you're missing button inputs, reflow the bottom left corner button pins.
- If you have games that don't start up properly and hang at the Nintendo logo during start-up, display a glitchy Nintendo logo, or randomly freeze during gameplay, reflow the cartridge pins and clean your cartridge connector. The freezing may also be caused by poorly connected SRAM as well.
- Three link port pins are on the bottom right, but there is one lone one at the top.
- In general, reflowing the clock and power pins (colored red, pink, and black) can solve problems as well.



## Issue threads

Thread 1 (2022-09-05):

Add ProSound mod by default

8lall0, 2022-09-05:
Hi,
i was thinkin' that adding by default the prosound mod on a pcb level would be a nice improvement.

For reference: https://guides.brit.co/guides/mod-your-dmg-gameboy-with-prosound-stereo-jack

That's with the help of an external audio jack, but can be done with internal jack too (i modded two DMGs with that, no issues)

MouseBiteLabs, 2022-09-06:
The problem with doing that is you lose the amplification from the LM4853 for the headphones, so the max volume isn't as high as I would like it. That's why I added the solder pads so you could cut the traces and jumper to the potentiometer outputs if you wanted the speaker to still be amplified, but the headphone output to be the "pro-sound" quality.

Or if you wanted a second jack, you could just grab LOUT, ROUT, and GND from the pot just like in the link you sent!

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

MouseBiteLabs, 2022-10-14:
Just an update - I was thinking about your comment more, and checked the site you linked again and realized you meant just adding a more convenient location for connection to a "pro-sound" headphone jack. So I've included that! Also working on a headphone board with an optional pro-sound headphone jack. New rev of boards should be arriving soon.

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

Closed 2022-09-06.

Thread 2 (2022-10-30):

LSDJ Specific - conflict with ips shortcuts

8lall0, 2022-10-30:
I use LSDJ to make music, and i was thinking that select+a+b is both an LSDJ action and the ips menu shortcut, probably there is a conflict that should at least be noted on the readme :)

8lall0, 2022-10-30:
Closing because i got confused, Sorry!

MouseBiteLabs, 2022-10-31:
I can add a note for that definitely! I've never used that software before but adding the pro-sound output was partly motivated by users of LSDJ so I guess I should note it haha.

The only reason I used A/B/Sel is because that's the default the IPS kit uses.

It is worth noting that you don't *have* to use the A/B/Sel pads at the top of the board for the OSD menu. You could run longer wires down to the middle of the board and pick whatever buttons you want, I put pads for each button there for specifically that reason. You could do left, down, and A if you really wanted lol.

Closed 2022-10-30.

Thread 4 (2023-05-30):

Wrong thickness - Can i have trouble?

8lall0, 2023-05-30:
I accidentaly made boards with the wrong thickness (1.6), is it gonna affect my build?

Closed 2023-05-30.

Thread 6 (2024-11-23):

Adding to optional 10K resistors to bypass the touch sensor of the IPS Q5 screen

ahmadexp, 2024-11-23:
I
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
 was getting false clicks by the touch sensor of the IPS Q5 screen.
I removed the TTP223 chip (both sides) and shorted pin 1 and 3 on the foot print, then I added a 10k pull-up between pin 1 and 5.
Then on the IPS-01 PCB board I removed C4 and C5 and used a 10 ohm instead (can be shorted as well) and everything works very well.
Now I was wondering, maybe we can have the pull up resistors added to the IPS-01 PCB as an optional feature. I attached a sketch for more clarity.

MouseBiteLabs, 2024-11-23:
Doing that would endanger the Q5 driver board, since it generates its own 3.3V supply independent of the one on the DMGC. In fact, I killed a Q5 driver board in this exact manner.

C4 and C5 are meant to desensitize the touch inputs, if you're still getting triggers you can try upping the capacitance to 220pF

MouseBiteLabs, 2024-11-23:
Edited the comment, mislabeled the desensitizing caps.
Also to be clear, removing the touch ICs on the driver board is perfectly fine. Originally I was going to have that as part of the process for building but didn't want people to potentially endanger a $50 screen kit if I could help it lol

ahmadexp, 2024-12-03:
Makes Total sense. I appreciate your comment and I am super thankful to your project.
One other trick I found which makes it safe[r] is to have the pull up on the IPS board done after removing the touch IC and placing two 0402 resistors directly on the pads of the touch IC. That way things should be safe for the IPS board. Anyways, I got rid of the the touch sensor once for all.

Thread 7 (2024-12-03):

Power LED suggestion

ahmadexp, 2024-12-03:
First of all, I LOVE my DMGC so much and I am the world thankful to you.
I was wondering, if you would consider adding a 3mm RGB LED driven by a WS2811 IC, placed on the chain of the rest of the Neo Pixel LEDs. That would, the color and the brightness of the power LED can be adjusted too. Just an idea though.
I will try to dead bug the WS2811 chip on mine to see how that turns and share the result with you.

MouseBiteLabs, 2024-12-04:
Are there 3mm addressable RGB LEDs? I haven't seen any

On Tue, Dec 3, 2024, 12:43 AM Ahmad Byagowi ***@***.***>
wrote:

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

ahmadexp, 2024-12-05:
I have never tested it myself but I came across this; the WS2811 is an IC with NeoPixel interface and the LED PWM outputs. So, a 3mm LED can be driven by it. What I am not sure about is the voltage requirements.

ahmadexp, 2024-12-06:
I also looked into the 3mm RGB LEDs and they are much harder to find that what I thought. There is one available that is also common anode which can be used with the WS2811
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

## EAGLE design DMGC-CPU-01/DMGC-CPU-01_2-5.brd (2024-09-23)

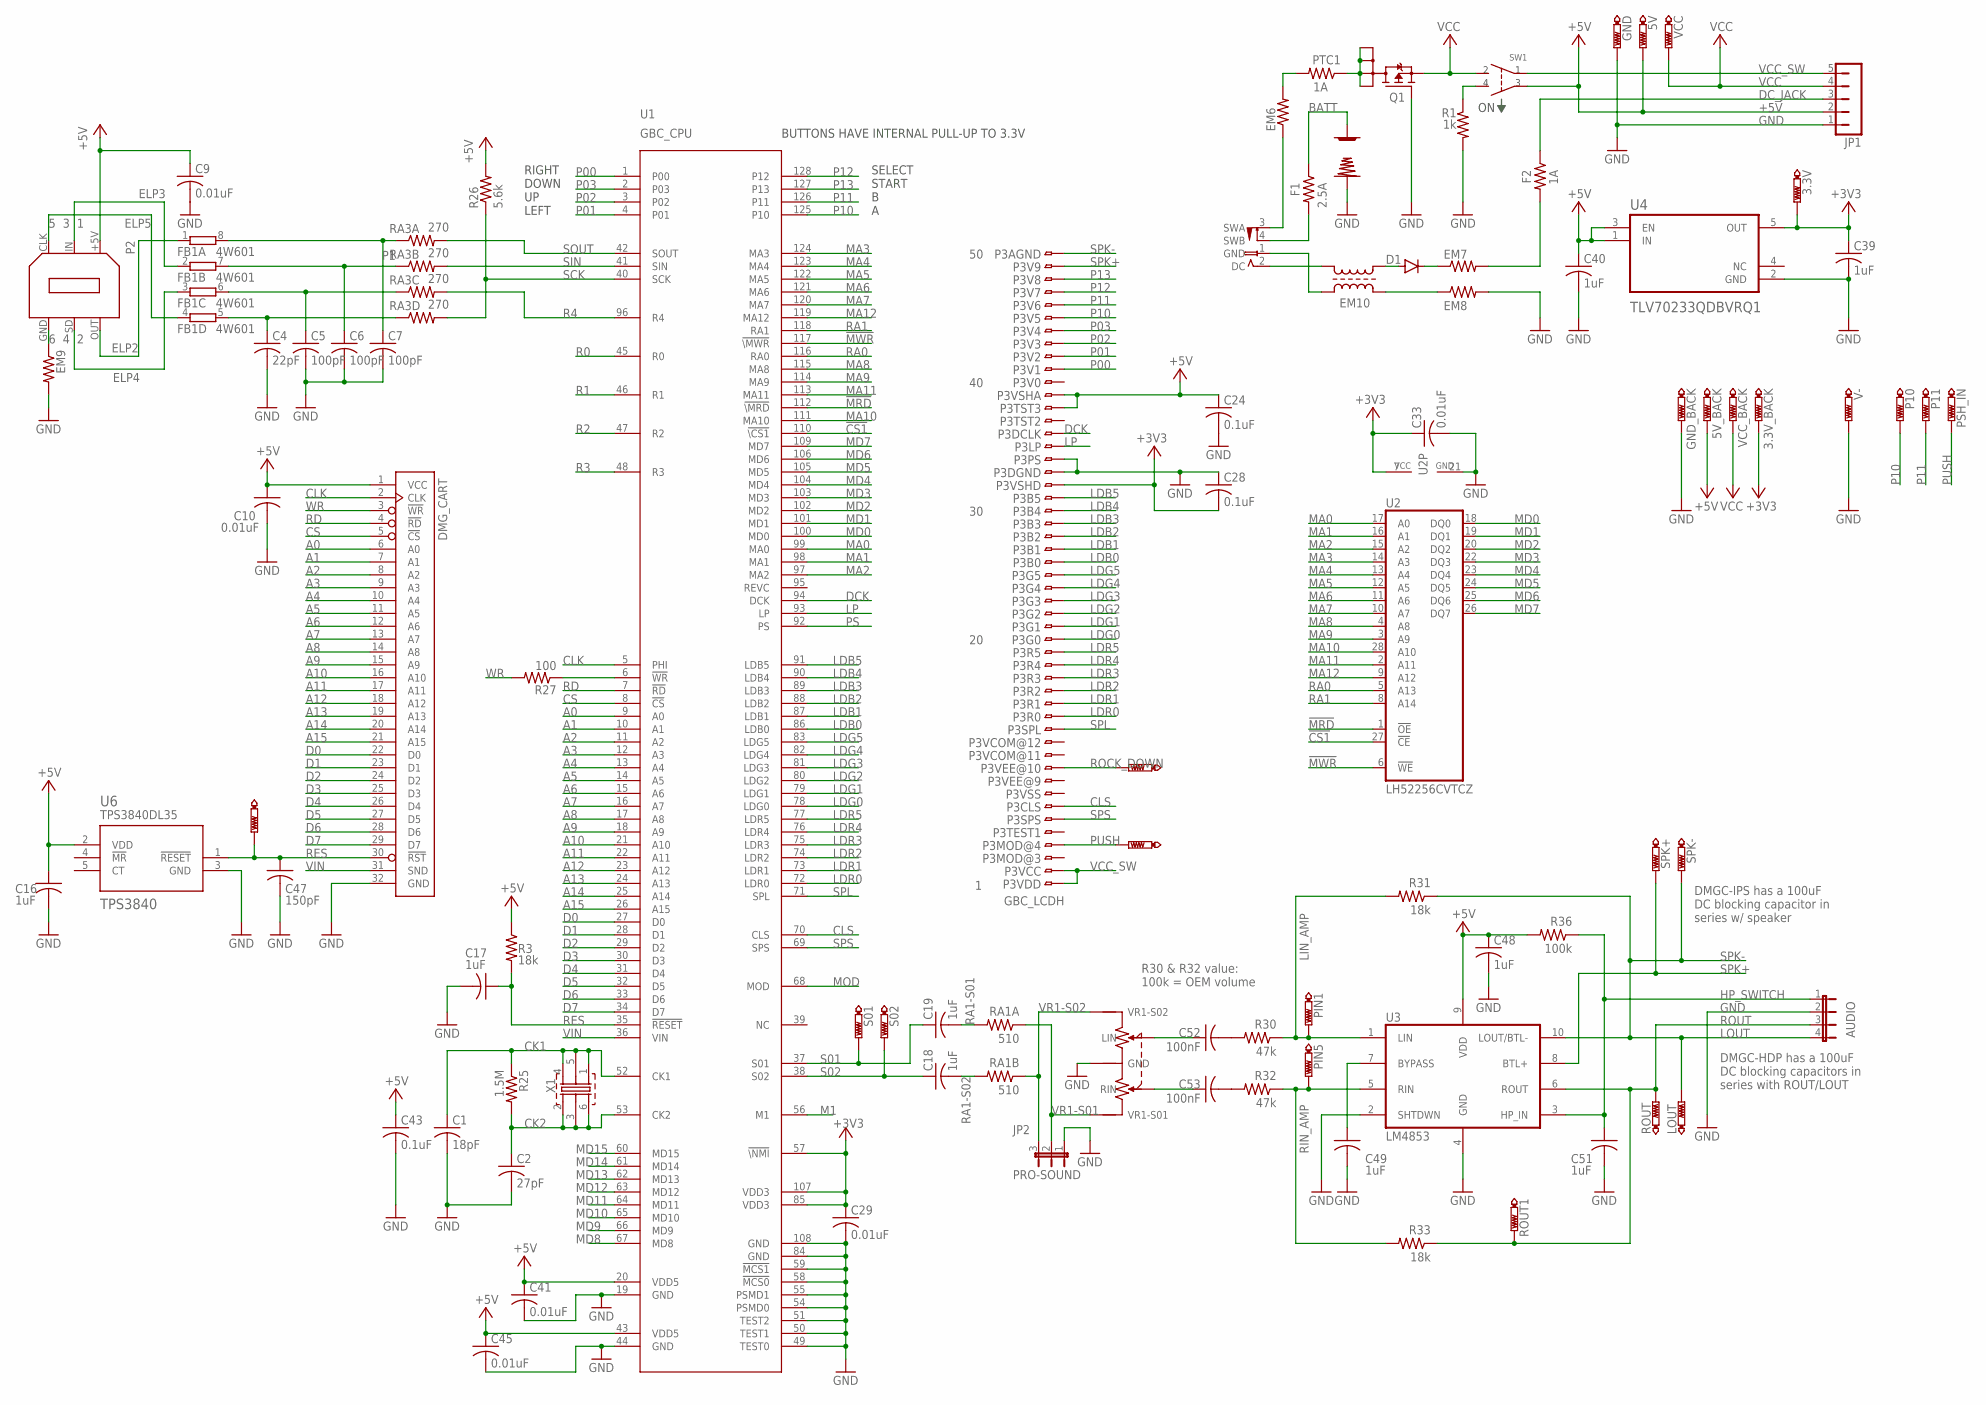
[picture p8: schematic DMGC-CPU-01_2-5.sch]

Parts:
3.3V, 3.3V_BACK, 5V, 5V_BACK: PTR1B1,27; B1,27
+: DMG_BAT_POS
-: DMG_BAT_NEG
AUDIO: JP4E; JP4
C1: 18pF; C0603
C2: 27pF; C0603
C4: 22pF; C0603
C5, C6, C7: 100pF; C0603
C9, C10, C29, C33, C41, C45: 0.01uF; C0603
C16, C17, C18, C19, C39, C40, C48, C49, C51: 1uF; C0603
C24, C28, C43: 0.1uF; C0603
C47: 150pF; C0603
C52, C53: 100nF; C0603
D1: CGRM4001-G; SOD-123_MINI-SMA
DC: DMG_DCJACK
EM6, EM7, EM8: BLM21P221SG; R0805
EM9: BLM21P221SG; R0603
EM10: ACM4532-801-2PA; ACM4532
F1: 2.5A; R1206
F2: 1A; R1206
FB1: 4W601; EXB38V
GND: PTR1B1,27; B1,27
GND_BACK: PTR1B1,27; B1,27
JP1: JP5
JP2: JP2E; JP2
LOUT: PTR1B1,27; B1,27
P1: DMG_CART
P2: LINKPORTDMG-LINK-SHORT; DMG_EXT
P3: GBC_LCDH; 62684-502100AHLF
P10, P11: PTR1B1,27; B1,27
PIN1, PIN5: PTR1B1,27; B1,27
PSH_IN: PTR1B1,27; B1,27
PTC1: 1A; R1206
PUSH: PTR1B1,27; B1,27
Q1: SI1401EDH; SOT363_INFINEON
R1: 1k; R0603
R3, R31, R33: 18k; R0603
R25: 1.5M; R0603
R26: 5.6k; R0603
R27: 100; R0603
R30, R32: 47k; R0603
R36: 100k; R0603
RA1A, RA1B: 510; R0603
RA3A, RA3B, RA3C, RA3D: 270; R0603
ROCKDOWN: PTR1B1,27; B1,27
ROUT, ROUT1: PTR1B1,27; B1,27
RST: PTR1B1,27; B1,27
S01, S02: PTR1B1,27; B1,27
SPK+: PTR1B1,27; B1,27
SPK-: PTR1B1,27; B1,27
SW1: DMG_SW
U1: GBC_CPU; QFP-128
U2: LH52256CVTCZ; TSOP1-28
U3: LM4853; VSSOP10
U4: TLV70233QDBVRQ1; SOT95P280X145-5N
U6: TPS3840; SOT-23-5
V-: PTR1B1,27; B1,27
VCC: PTR1B1,27; B1,27
VCC_BACK: PTR1B1,27; B1,27
VR1: DMG_VOL
X1: 8.388608MHZ12SMX-B-4-PAD; 7.5X5-4-PAD

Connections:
!CS1: U1.110 (!\CS1), U2.27 (!CE)
!MRD: U1.112 (!\MRD), U2.1 (!OE)
!MWR: U1.117 (!\MWR), U2.6 (!WE)
+3V3: 3.3V.TP, 3.3V_BACK.TP, C28.2, C29.1, C33.1, C39.1, P3.32, U1.57 (!\NMI), U1.85 (VDD3), U1.107 (VDD3), U2.7 (VCC), U4.5 (OUT)
+5V: 5V.TP, 5V_BACK.TP, C9.1, C10.1, C16.1, C24.1, C40.1, C41.1, C43.1, C45.1, C48.1, JP1.2, P1.1 (VCC), P2.+5V, P3.38, P3.39, R3.1, R26.2, R36.2, SW1.P$3 (3), U1.20 (VDD5), U1.43 (VDD5), U3.9 (VDD), U4.1 (IN), U4.3 (EN), U6.2 (VDD)
A0: P1.6 (A0), U1.9 (A0)
A1: P1.7 (A1), U1.10 (A1)
A2: P1.8 (A2), U1.11 (A2)
A3: P1.9 (A3), U1.12 (A3)
A4: P1.10 (A4), U1.13 (A4)
A5: P1.11 (A5), U1.14 (A5)
A6: P1.12 (A6), U1.15 (A6)
A7: P1.13 (A7), U1.16 (A7)
A8: P1.14 (A8), U1.17 (A8)
A9: P1.15 (A9), U1.18 (A9)
A10: P1.16 (A10), U1.21 (A10)
A11: P1.17 (A11), U1.22 (A11)
A12: P1.18 (A12), U1.23 (A12)
A13: P1.19 (A13), U1.24 (A13)
A14: P1.20 (A14), U1.25 (A14)
A15: P1.21 (A15), U1.26 (A15)
BATT: +.P$1, F1.1
BATT_DC: DC.3 (SWA), EM6.1
CK1: C1.1, R25.1, U1.52 (CK1), X1.1, X1.4, X1.5
CK2: C2.1, R25.2, U1.53 (CK2), X1.2, X1.3, X1.6
CLK: P1.2 (CLK), U1.5 (PHI)
CLS: P3.7, U1.70 (CLS)
CS: P1.5 (!CS), U1.8 (!CS)
D0: P1.22 (D0), U1.27 (D0)
D1: P1.23 (D1), U1.28 (D1)
D2: P1.24 (D2), U1.29 (D2)
D3: P1.25 (D3), U1.30 (D3)
D4: P1.26 (D4), U1.31 (D4)
D5: P1.27 (D5), U1.32 (D5)
D6: P1.28 (D6), U1.33 (D6)
D7: P1.29 (D7), U1.34 (D7)
DCK: P3.36, U1.94 (DCK)
DC_JACK: F2.1, JP1.3
ELP2: FB1.1, P2.OUT
ELP3: FB1.2 (1), P2.IN
ELP4: FB1.3 (1), P2.SD
ELP5: FB1.4 (1), P2.CLK
EM10_EM8: EM8.1, EM10.3
EM10_GND: DC.1 (GND), EM10.2
EM10_POS: DC.2 (DC), EM10.1
GND: -.P$1, AUDIO.2, C1.2, C2.2, C4.2, C5.2, C6.2, C7.2, C9.2, C10.2, C16.2, C17.2, C24.2, C28.1, C29.2, C33.2, C39.2, C40.2, C41.2, C43.2, C45.2, C47.2, C48.2, C49.2, C51.2, EM8.2, EM9.2, GND.TP, GND_BACK.TP, JP1.1, JP2.1, P1.32 (GND), P2.SHIELD (GND), P2.SHIELD1 (GND), P3.33, P3.34, Q1.3 (G), R1.2, SW1.P$7 (GND), SW1.P$8 (GND), U1.19 (GND), U1.44 (GND), U1.49 (TEST0), U1.50 (TEST1), U1.51 (TEST2), U1.54 (PSMD0), U1.55 (PSMD1), U1.58 (!MCS0), U1.59 (!MCS1), U1.84 (GND), U1.108 (GND), U2.21 (GND), U3.2 (SHTDWN), U3.4 (GND), U4.2 (GND), U6.3 (GND), V-.TP, VR1.P$1 (GND), VR1.P$6 (GND), VR1.P$7 (GND)
HP_SWITCH: AUDIO.1, C51.1, R36.1, U3.3 (HP_IN)
LDB0: P3.26, U1.86 (LDB0)
LDB1: P3.27, U1.87 (LDB1)
LDB2: P3.28, U1.88 (LDB2)
LDB3: P3.29, U1.89 (LDB3)
LDB4: P3.30, U1.90 (LDB4)
LDB5: P3.31, U1.91 (LDB5)
LDG0: P3.20, U1.78 (LDG0)
LDG1: P3.21, U1.79 (LDG1)
LDG2: P3.22, U1.80 (LDG2)
LDG3: P3.23, U1.81 (LDG3)
LDG4: P3.24, U1.82 (LDG4)
LDG5: P3.25, U1.83 (LDG5)
LDR0: P3.14, U1.72 (LDR0)
LDR1: P3.15, U1.73 (LDR1)
LDR2: P3.16, U1.74 (LDR2)
LDR3: P3.17, U1.75 (LDR3)
LDR4: P3.18, U1.76 (LDR4)
LDR5: P3.19, U1.77 (LDR5)
LIN_AMP: PIN1.TP, R30.1, R31.2, U3.1 (LIN)
LP: P3.35, U1.93 (LP)
M1: U1.56 (M1)
MA0: U1.99 (MA0), U2.17 (A0)
MA1: U1.98 (MA1), U2.16 (A1)
MA2: U1.97 (MA2), U2.15 (A2)
MA3: U1.124 (MA3), U2.14 (A3)
MA4: U1.123 (MA4), U2.13 (A4)
MA5: U1.122 (MA5), U2.12 (A5)
MA6: U1.121 (MA6), U2.11 (A6)
MA7: U1.120 (MA7), U2.10 (A7)
MA8: U1.115 (MA8), U2.4 (A8)
MA9: U1.114 (MA9), U2.3 (A9)
MA10: U1.111 (MA10), U2.28 (A10)
MA11: U1.113 (MA11), U2.2 (A11)
MA12: U1.119 (MA12), U2.9 (A12)
MD0: U1.100 (MD0), U2.18 (DQ0)
MD1: U1.101 (MD1), U2.19 (DQ1)
MD2: U1.102 (MD2), U2.20 (DQ2)
MD3: U1.103 (MD3), U2.22 (DQ3)
MD4: U1.104 (MD4), U2.23 (DQ4)
MD5: U1.105 (MD5), U2.24 (DQ5)
MD6: U1.106 (MD6), U2.25 (DQ6)
MD7: U1.109 (MD7), U2.26 (DQ7)
MD8: U1.67 (MD8)
MD9: U1.66 (MD9)
MD10: U1.65 (MD10)
MD11: U1.64 (MD11)
MD12: U1.63 (MD12)
MD13: U1.62 (MD13)
MD14: U1.61 (MD14)
MD15: U1.60 (MD15)
MOD: U1.68 (MOD)
unnamed: C7.1, FB1.8 (2), RA3A.1
unnamed: C6.1, FB1.7 (2), RA3B.1
unnamed: C52.2, R30.2
unnamed: C53.2, R32.2
unnamed: C5.1, FB1.6 (2), RA3C.1
unnamed: C52.1, VR1.P$3 (LIN)
unnamed: R27.1, U1.6 (!WR)
unnamed: C4.1, FB1.5 (2), RA3D.1
unnamed: C53.1, VR1.P$2 (RIN)
unnamed: R1.1, SW1.P$4 (4)
unnamed: D1.C, EM7.1
unnamed: EM7.2, F2.2
unnamed: EM6.2, PTC1.2
unnamed: EM9.1, P2.GND
unnamed: C49.1, U3.7 (BYPASS)
P00: P3.41, U1.1 (P00)
P01: P3.42, U1.4 (P01)
P02: P3.43, U1.3 (P02)
P03: P3.44, U1.2 (P03)
P10: P3.45, P10.TP, U1.125 (P10)
P11: P3.46, P11.TP, U1.126 (P11)
P12: P3.47, U1.128 (P12)
P13: P3.48, U1.127 (P13)
PFET_DRAIN: PTC1.1, Q1.1 (D1), Q1.2 (D2), Q1.5 (D5), Q1.6 (D6)
PS: U1.92 (PS)
PUSH: P3.4, PSH_IN.TP, PUSH.TP
R0: U1.45 (R0)
R1: U1.46 (R1)
R2: U1.47 (R2)
R3: U1.48 (R3)
R4: RA3C.2, U1.96 (R4)
RA0: U1.116 (RA0), U2.5 (A13)
RA1: U1.118 (RA1), U2.8 (A14)
RA1-S01: C19.2, RA1A.2
RA1-S02: C18.2, RA1B.2
RD: P1.4 (!RD), U1.7 (!RD)
RES: C17.1, C47.1, P1.30 (!RST), R3.2, RST.TP, U1.35 (!RESET), U6.1 (!RESET)
RIN_AMP: PIN5.TP, R32.1, R33.2, U3.5 (RIN)
ROCK_DOWN: P3.10, ROCKDOWN.TP
ROUT: AUDIO.3, R33.1, ROUT.TP, ROUT1.TP, U3.6 (ROUT)
RPP: D1.A, EM10.4
S01: C19.1, S01.TP, U1.37 (S01)
S02: C18.1, S02.TP, U1.38 (S02)
SCK: R26.1, RA3D.2, U1.40 (SCK)
SIN: RA3B.2, U1.41 (SIN)
SOUT: RA3A.2, U1.42 (SOUT)
SPK+: P3.49, SPK+.TP, U3.8 (BTL+)
SPK-: AUDIO.4, LOUT.TP, P3.50, R31.1, SPK-.TP, U3.10 (LOUT/BTL-)
SPL: P3.13, U1.71 (SPL)
SPS: P3.6, U1.69 (SPS)
SW1B: DC.4 (SWB), F1.2
VCC: JP1.4, Q1.4 (S), SW1.P$2 (2), VCC.TP, VCC_BACK.TP
VCC_SW: JP1.5, P3.1, P3.2, SW1.P$1 (1)
VIN: P1.31 (SND), U1.36 (VIN)
VR1-S01: JP2.2, RA1A.1, VR1.P$5 (VR1-S01)
VR1-S02: JP2.3, RA1B.1, VR1.P$4 (VR1-S02)
WR: P1.3 (!WR), R27.2

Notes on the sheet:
5 3 1
6 4 2
BUTTONS HAVE INTERNAL PULL-UP TO 3.3V
SELECT START B A
RIGHT DOWN UP LEFT
TPS3840DL35
R30 & R32 value: 100k = OEM volume
LOUT
DMGC-IPS has a 100uF DC blocking capacitor in series w/ speaker
DMGC-HDP has a 100uF DC blocking capacitors in series with ROUT/LOUT
PRO-SOUND

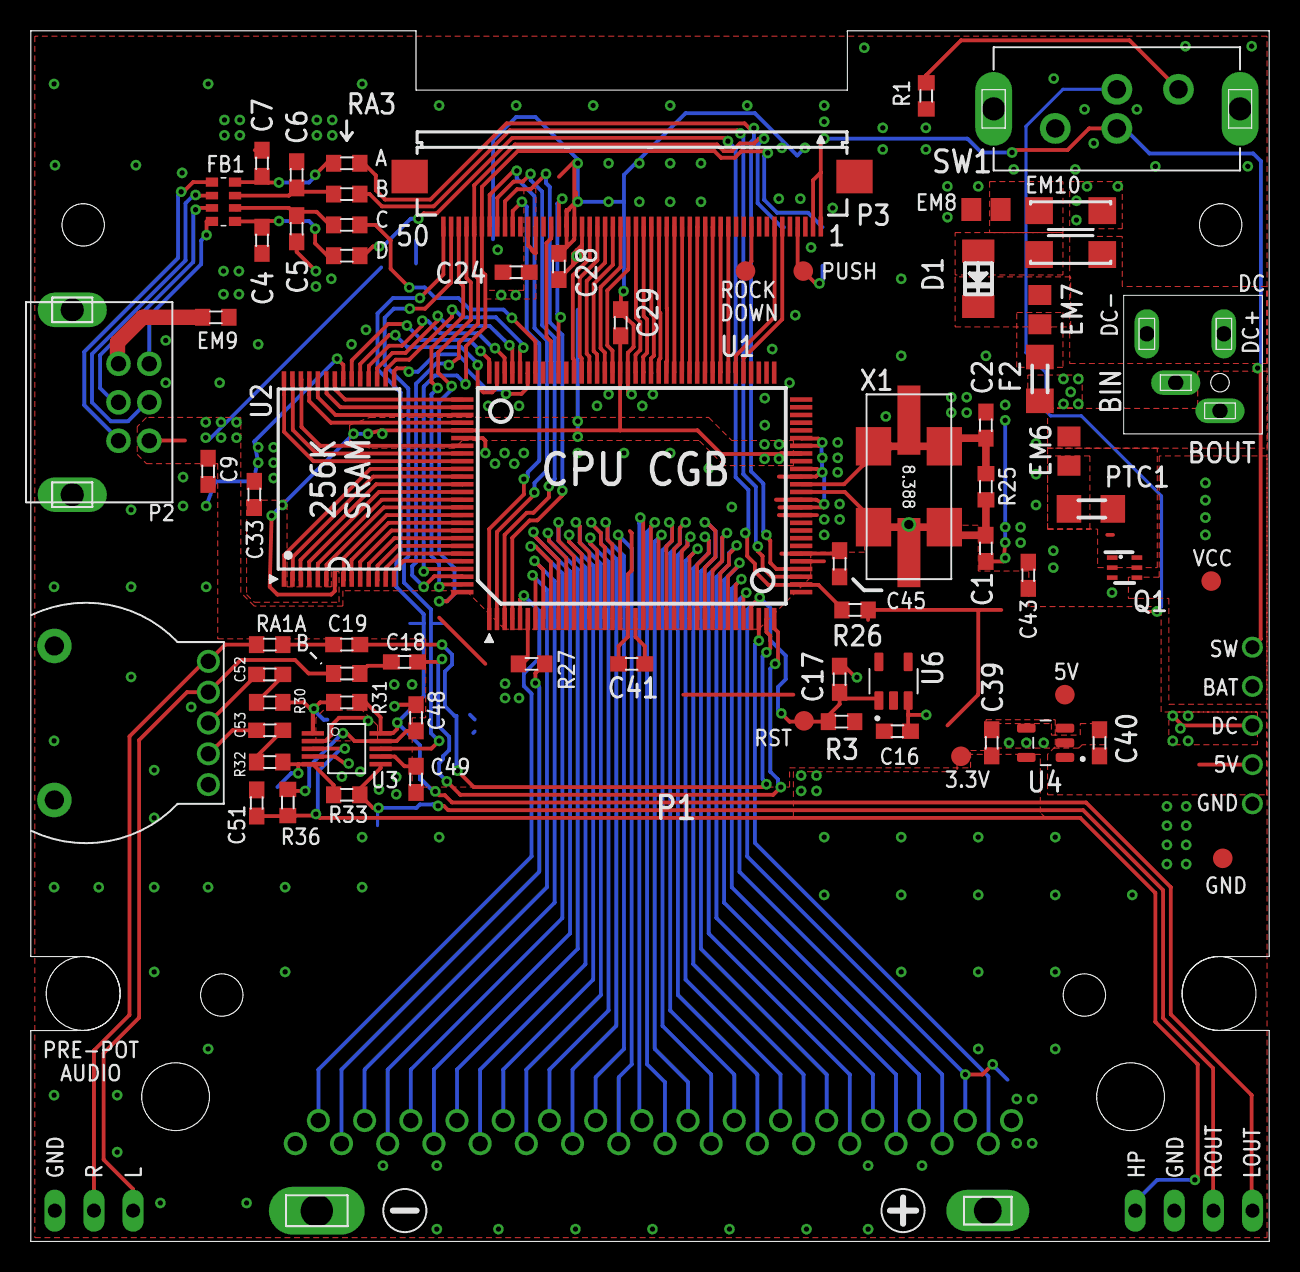
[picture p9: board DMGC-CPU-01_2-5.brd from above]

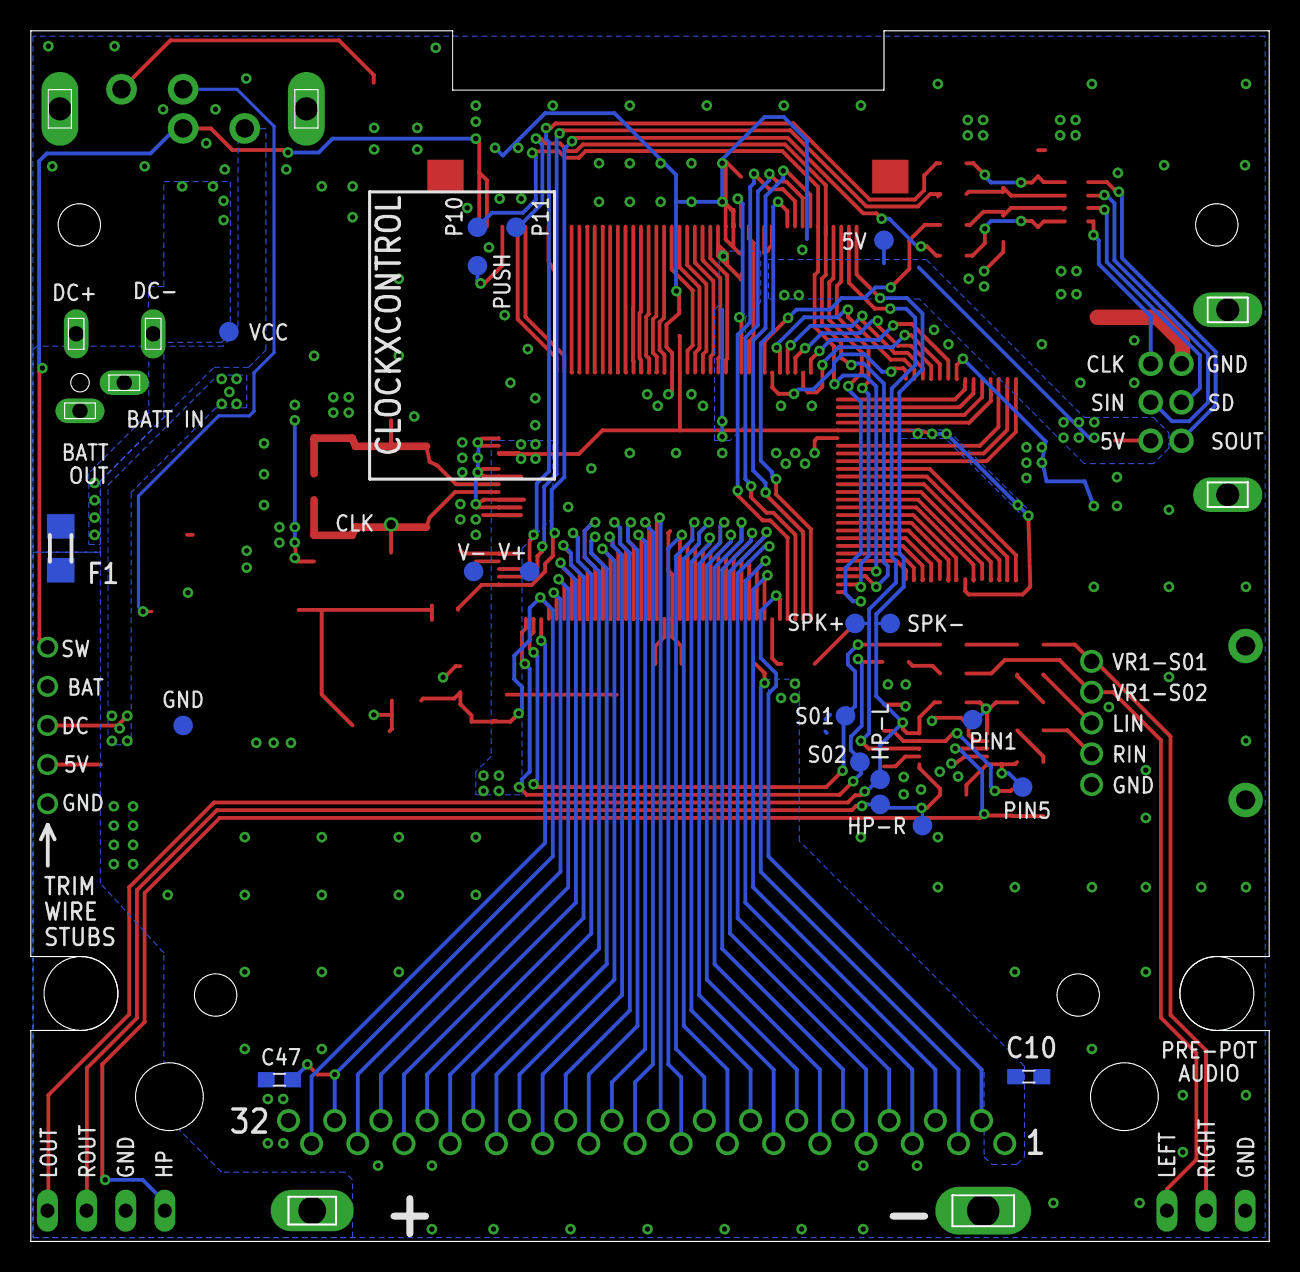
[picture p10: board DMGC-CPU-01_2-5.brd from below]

Board: 2 copper layers, 80.4 x 78.6 mm, 95 parts (20 on the bottom side), 140 nets.

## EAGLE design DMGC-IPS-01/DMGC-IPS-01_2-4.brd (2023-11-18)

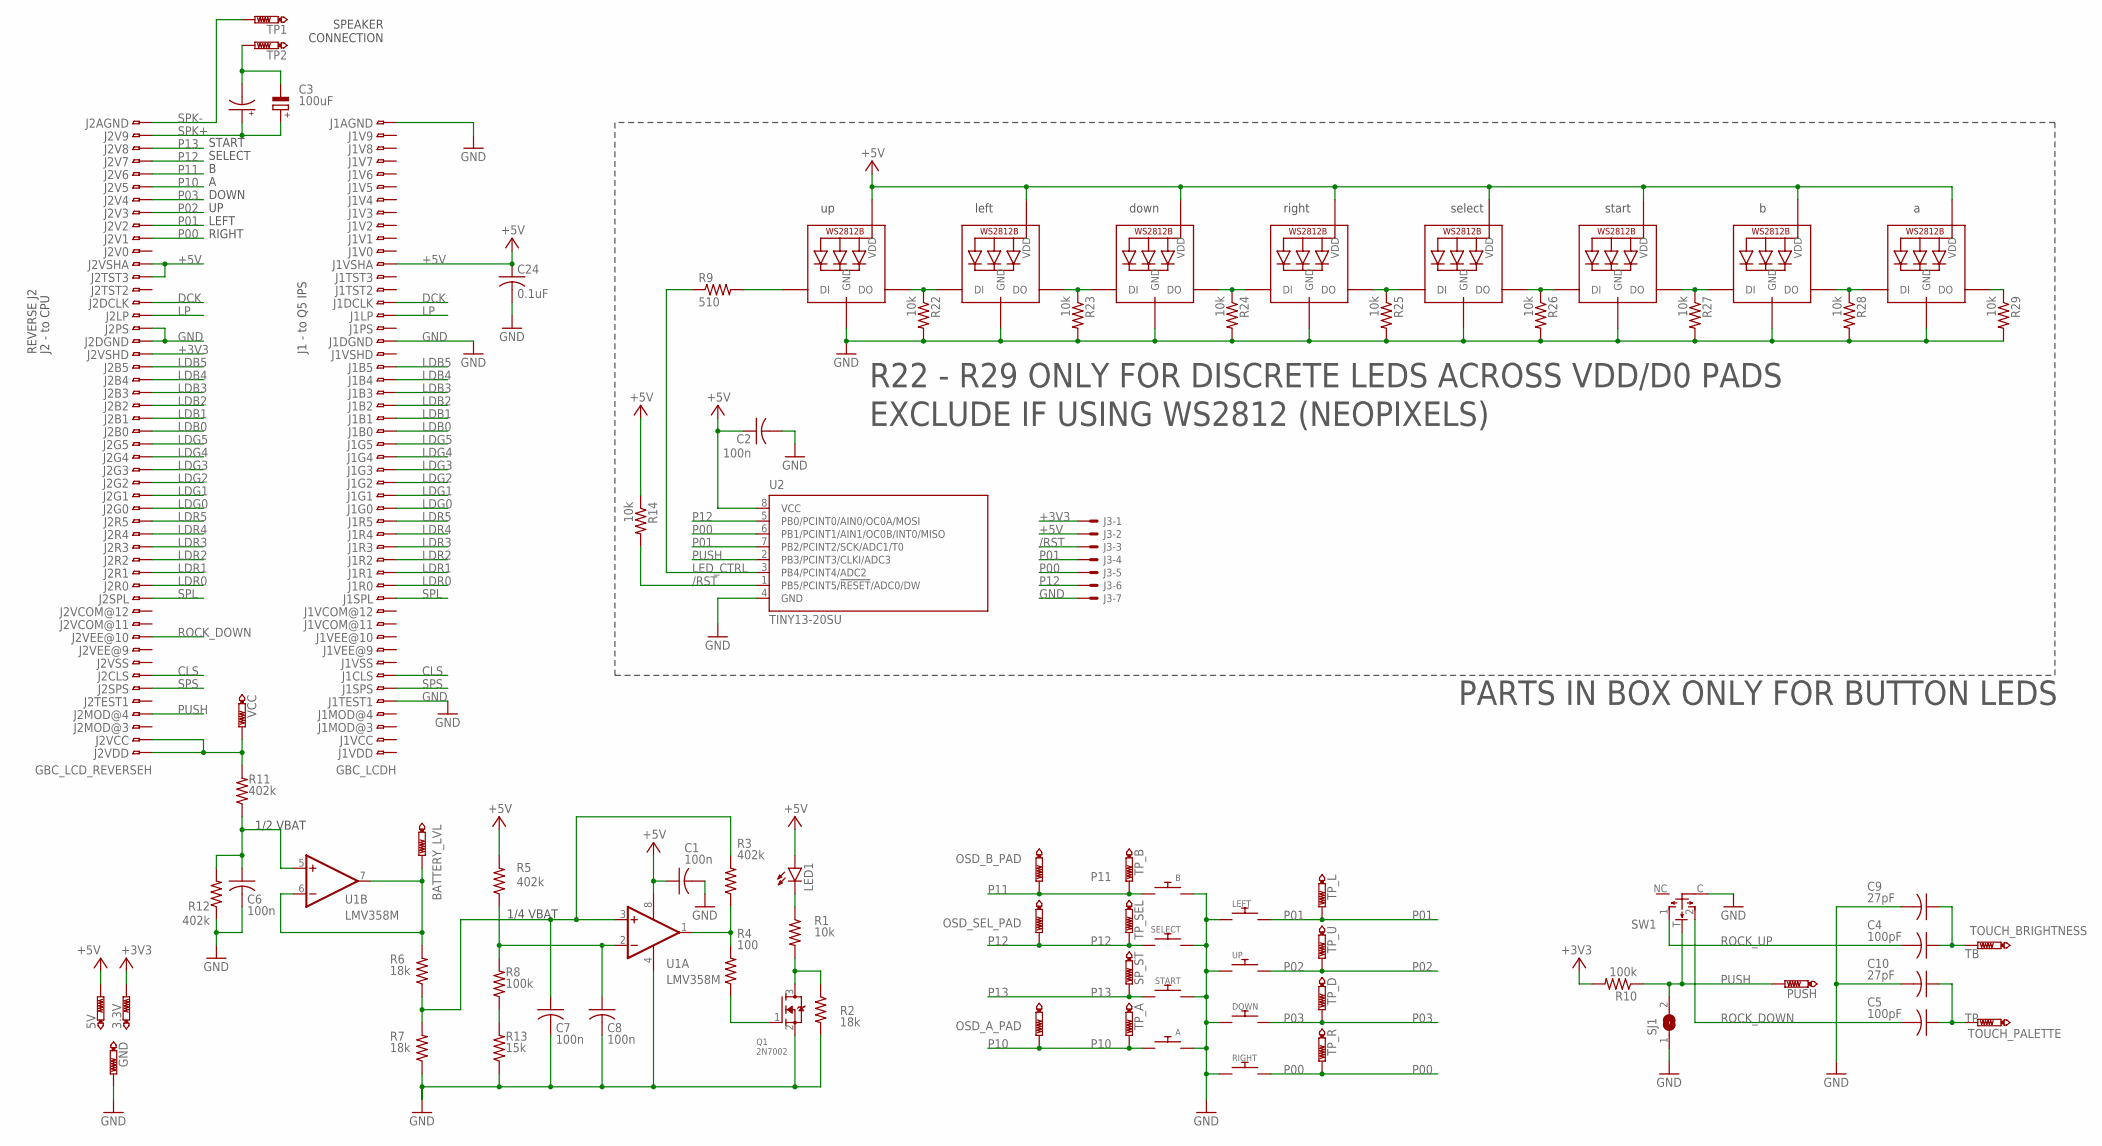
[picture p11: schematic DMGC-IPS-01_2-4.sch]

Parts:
3.3V, 5V: PTR1TP20R; TP20R
A: DMG-BTN; DMG_BTN1
B: DMG-BTN; DMG_BTN1
BATTERY_LVL: PTR1TP20R; TP20R
C1, C2, C6, C7, C8: 100n; C0603
C3: 100uF; CT3528
C3TH: CPOL-EUE2,5-6E; E2,5-6E
C4, C5: 100pF; C0603
C9, C10: 27pF; C0603
C24: 0.1uF; C0603
DOWN: DMG-BTN; DMG_BTN1
GND: PTR1TP20R; TP20R
J1: GBC_LCDH; 62684-502100AHLF
J2: GBC_LCD_REVERSEH; 62684-502100AHLF_REVERSE
J3: C-GRID-07-15-91; 15-91-07
LED1: LED3MM
LED10, LED11, LED12, LED13, LED14, LED15, LED16, LED17: WS2812B3535; LED3535
LEFT: DMG-BTN; DMG_BTN1
OSD_A_PAD: PTR1TP20R; TP20R
OSD_B_PAD: PTR1TP20R; TP20R
OSD_SEL_PAD: PTR1TP20R; TP20R
PUSH: PTR1TP20R; TP20R
Q1: 2N7002; SOT23
R1, R14, R22, R23, R24, R25, R26, R27, R28, R29: 10k; R0603
R2, R6, R7: 18k; R0603
R3, R5, R11, R12: 402k; R0603
R4: 100; R0603
R8, R10: 100k; R0603
R9: 510; R0603
R13: 15k; R0603
RIGHT: DMG-BTN; DMG_BTN1
SELECT: DMG-BTN; DMG_BTN2_TACT2
SJ1: SJ
SP_ST: PTR1TP20R; TP20R
START: DMG-BTN; DMG_BTN2_TACT2
SW1: NAV_SWITCH
TOUCH_BRIGHTNESS: PTR1TP20R; TP20R
TOUCH_PALETTE: PTR1TP20R; TP20R
TP1, TP2: PTR1PAD1-13; P1-13
TP_A: PTR1TP20R; TP20R
TP_B: PTR1TP20R; TP20R
TP_D: PTR1TP20R; TP20R
TP_L: PTR1TP20R; TP20R
TP_R: PTR1TP20R; TP20R
TP_SEL: PTR1TP20R; TP20R
TP_U: PTR1TP20R; TP20R
U1: LMV358M; SO08
U2: TINY13-20SU; 8S2
UP: DMG-BTN; DMG_BTN1
VCC: PTR1TP20R; TP20R

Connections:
+3V3: 3.3V.TP, J2.19, J3.1, R10.2
+5V: 5V.TP, C1.1, C2.1, C24.1, J1.39, J2.12, J2.13, J3.2, LED1.A, LED10.4 (VDD), LED11.4 (VDD), LED12.4 (VDD), LED13.4 (VDD), LED14.4 (VDD), LED15.4 (VDD), LED16.4 (VDD), LED17.4 (VDD), R5.2, R14.1, U1.8 (V+), U2.8 (VCC)
/RST: J3.3, R14.2, U2.1 (PB5/PCINT5/!RESET!/ADC0/DW)
BATT: J2.49, J2.50, R11.2, VCC.TP
CLS: J1.7, J2.44
DCK: J1.36, J2.15
GND: A.P$2, B.P$2, C1.2, C2.2, C6.2, C7.2, C8.2, C9.2, C10.2, C24.2, DOWN.P$2, GND.TP, J1.5, J1.33, J1.50, J2.17, J2.18, J3.7, LED10.2 (GND), LED11.2 (GND), LED12.2 (GND), LED13.2 (GND), LED14.2 (GND), LED15.2 (GND), LED16.2 (GND), LED17.2 (GND), LEFT.P$2, Q1.2 (S), R2.2, R7.1, R12.1, R13.1, R22.2, R23.2, R24.2, R25.2, R26.2, R27.2, R28.2, R29.2, RIGHT.P$2, SELECT.P$1, SJ1.1, START.P$1, SW1.C, U1.4 (V-), U2.4 (GND), UP.P$2
LDB0: J1.26, J2.25
LDB1: J1.27, J2.24
LDB2: J1.28, J2.23
LDB3: J1.29, J2.22
LDB4: J1.30, J2.21
LDB5: J1.31, J2.20
LDG0: J1.20, J2.31
LDG1: J1.21, J2.30
LDG2: J1.22, J2.29
LDG3: J1.23, J2.28
LDG4: J1.24, J2.27
LDG5: J1.25, J2.26
LDR0: J1.14, J2.37
LDR1: J1.15, J2.36
LDR2: J1.16, J2.35
LDR3: J1.17, J2.34
LDR4: J1.18, J2.33
LDR5: J1.19, J2.32
LED_CTRL: R9.1, U2.3 (PB4/PCINT4/ADC2)
LP: J1.35, J2.16
unnamed: Q1.3 (D), R1.2, R2.1
unnamed: LED1.K (C), R1.1
unnamed: BATTERY_LVL.TP, R6.2, U1.6 (-IN), U1.7 (OUT)
unnamed: LED13.1 (DO), LED16.3 (DI), R27.1
unnamed: LED15.3 (DI), LED16.1 (DO), R28.1
unnamed: LED10.1 (DO), LED14.3 (DI), R22.1
unnamed: C8.1, R5.1, R8.2, U1.2 (-IN)
unnamed: LED11.3 (DI), LED14.1 (DO), R23.1
unnamed: LED11.1 (DO), LED12.3 (DI), R24.1
unnamed: LED12.1 (DO), LED17.3 (DI), R25.1
unnamed: LED13.3 (DI), LED17.1 (DO), R26.1
unnamed: LED15.1 (DO), R29.1
unnamed: LED10.3 (DI), R9.2
unnamed: C6.1, R11.1, R12.2, U1.5 (+IN)
unnamed: C3.-, C3TH.-, TP2.TP
unnamed: R8.1, R13.2
unnamed: C7.1, R3.2, R6.1, R7.2, U1.3 (+IN)
unnamed: R3.1, R4.2, U1.1 (OUT)
P00: J2.10, J3.5, RIGHT.P$1, TP_R.TP, U2.6 (PB1/PCINT1/AIN1/OC0B/INT0/MISO)
P01: J2.9, J3.4, LEFT.P$1, TP_L.TP, U2.7 (PB2/PCINT2/SCK/ADC1/T0)
P02: J2.8, TP_U.TP, UP.P$1
P03: DOWN.P$1, J2.7, TP_D.TP
P10: A.P$1, J2.6, OSD_A_PAD.TP, TP_A.TP
P11: B.P$1, J2.5, OSD_B_PAD.TP, TP_B.TP
P12: J2.4, J3.6, OSD_SEL_PAD.TP, SELECT.P$2, TP_SEL.TP, U2.5 (PB0/PCINT0/AIN0/OC0A/MOSI)
P13: J2.3, SP_ST.TP, START.P$2
PSU_EN: Q1.1 (G), R4.1
PUSH: J2.47, PUSH.TP, R10.1, SJ1.2, SW1.T, U2.2 (PB3/PCINT3/CLKI/ADC3)
ROCK_DOWN: C5.2, J2.41, SW1.2
ROCK_UP: C4.2, SW1.1
SPK+: C3.+, C3TH.+, J2.2
SPK-: J2.1, TP1.TP
SPL: J1.13, J2.38
SPS: J1.6, J2.45
TB: C4.1, C9.1, TOUCH_BRIGHTNESS.TP
TP: C5.1, C10.1, TOUCH_PALETTE.TP

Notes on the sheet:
REVERSE J2
J1 - to Q5 IPS
J2 - to CPU
1/2 VBAT
left
down
right
select
start
1/4 VBAT
R22 - R29 ONLY FOR DISCRETE LEDS ACROSS VDD/D0 PADS
START SELECT B A DOWN UP LEFT RIGHT
SPEAKER CONNECTION
EXCLUDE IF USING WS2812 (NEOPIXELS)
PARTS IN BOX ONLY FOR BUTTON LEDS

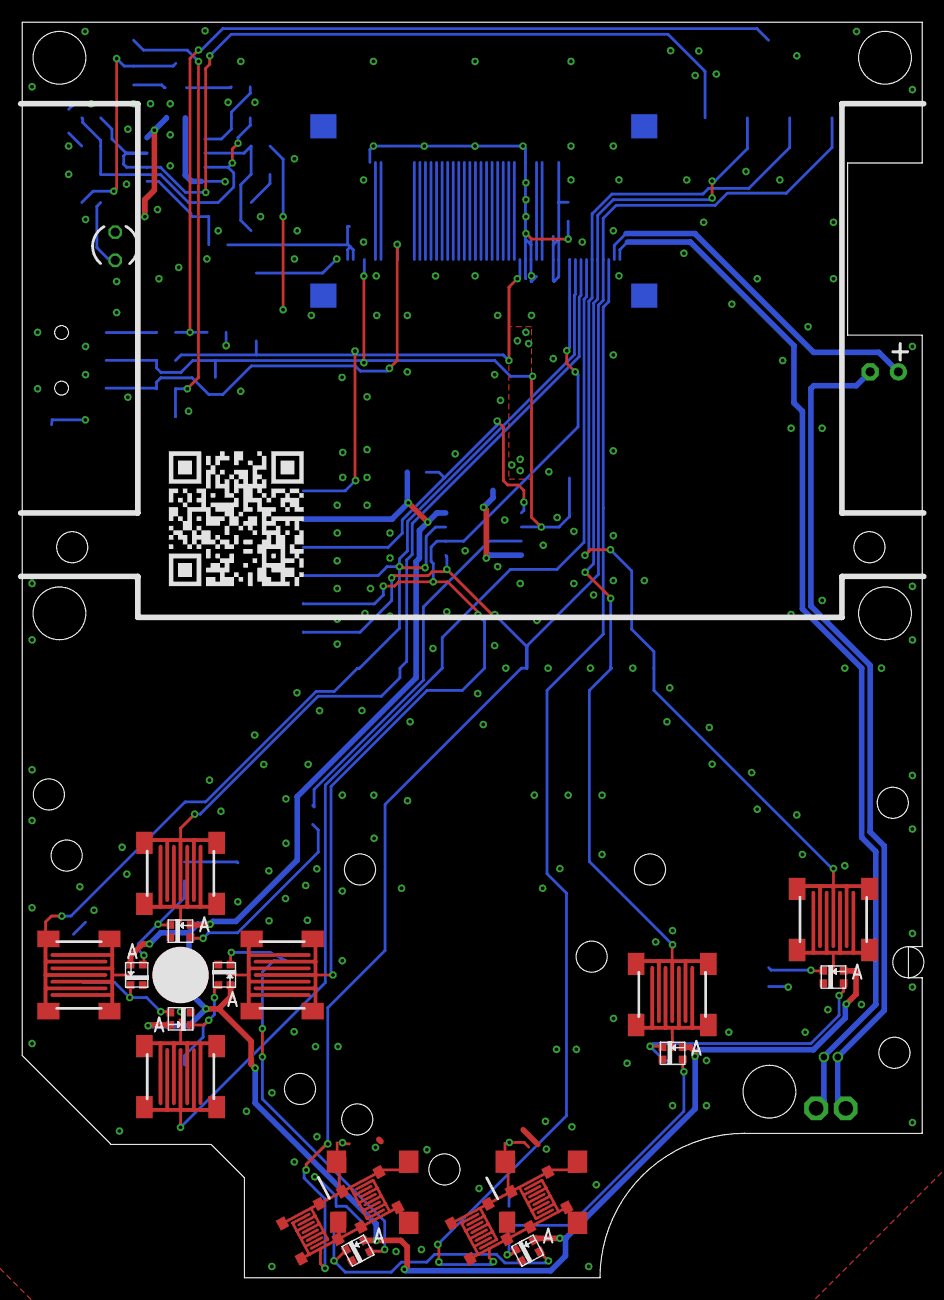
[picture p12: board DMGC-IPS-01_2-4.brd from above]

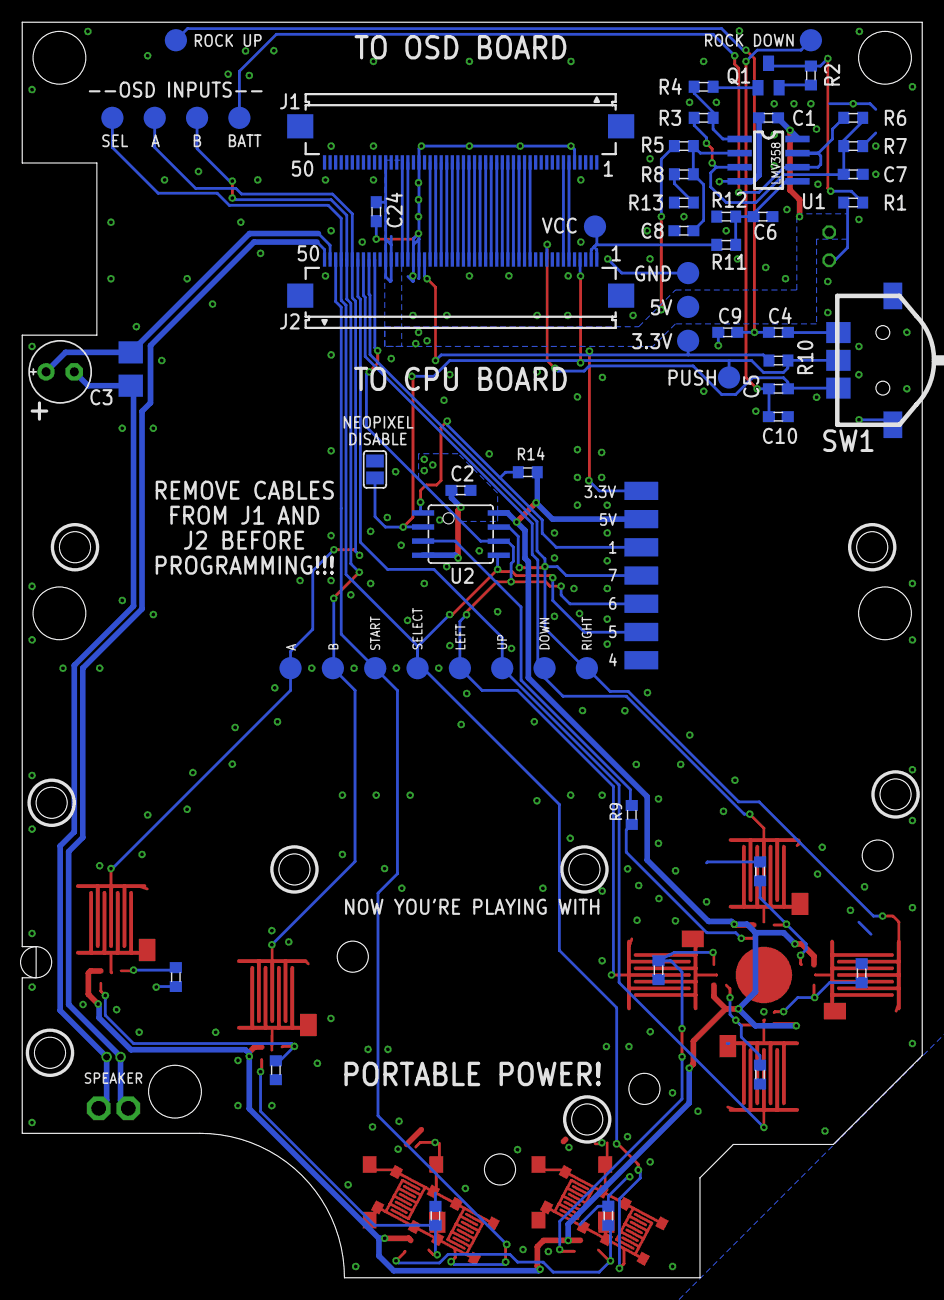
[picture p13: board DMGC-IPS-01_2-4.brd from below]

Board: 2 copper layers, 81.0 x 113.0 mm, 80 parts (61 on the bottom side), 63 nets.

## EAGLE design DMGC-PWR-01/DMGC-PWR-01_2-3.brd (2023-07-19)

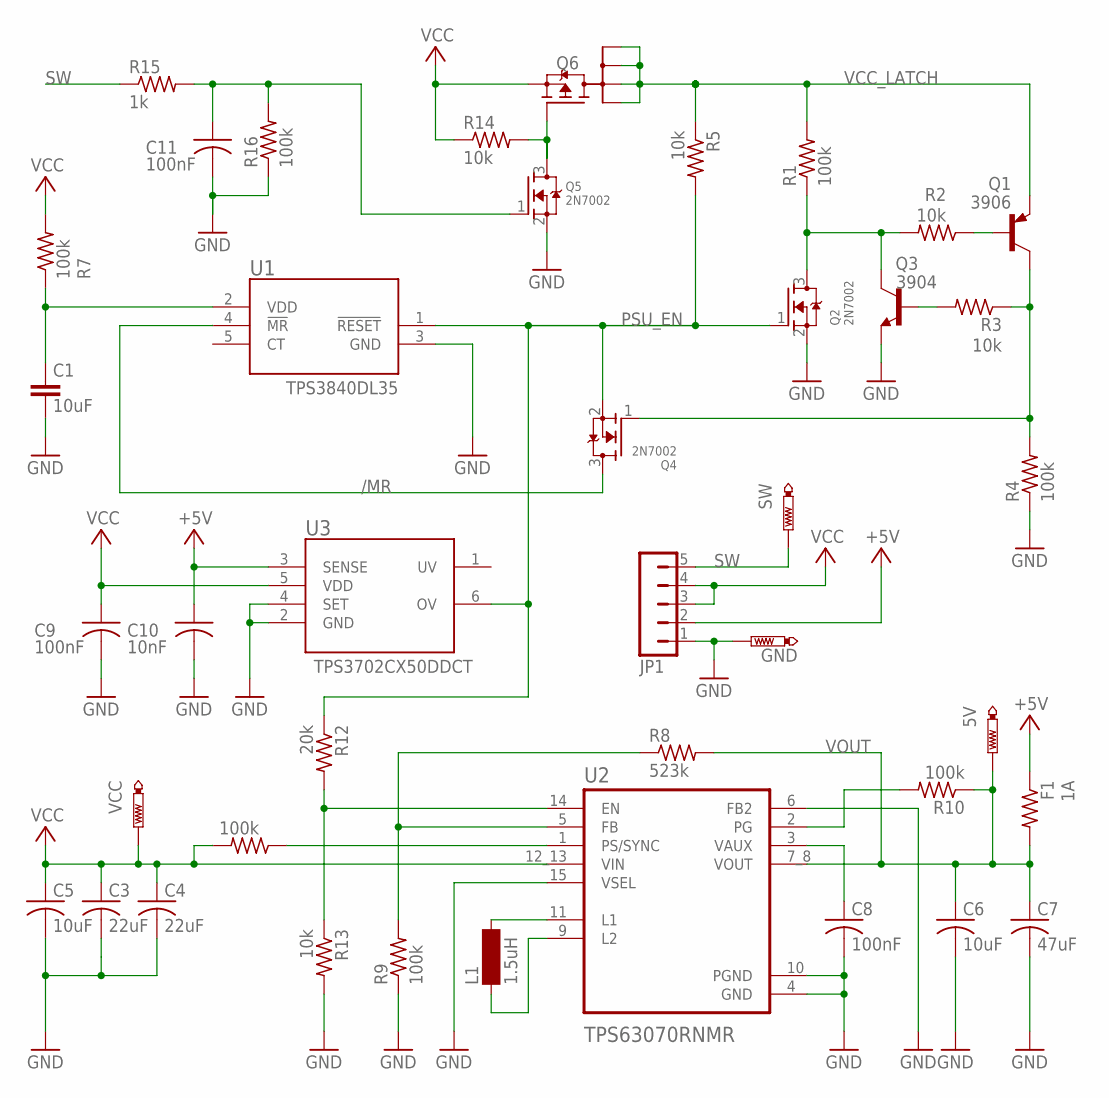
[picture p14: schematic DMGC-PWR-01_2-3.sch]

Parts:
5V: PTR1B1,27; B1,27
C1, C5, C6: 10uF; C0603
C3, C4: 22uF; C1206
C7: 47uF; C1206
C8, C9, C11: 100nF; C0603
C10: 10nF; C0603
F1: 1A; R0603
GND: PTR1B1,27; B1,27
JP1: JP5
L1: 1.5uH; 1212
Q1: MMBT3906LT1SMD; SOT23-BEC
Q2, Q4, Q5: 2N7002; SOT23
Q3: 3904; SOT23-BEC
Q6: SI1401EDH; SOT363_INFINEON
R1, R4, R7, R9, R10, R11, R16: 100k; R0603
R2, R3, R5, R13, R14: 10k; R0603
R8: 523k; R0603
R12: 20k; R0603
R15: 1k; R0603
SW: PTR1B1,27; B1,27
U1: TPS3840; SOT-23-5
U2: TPS63070RNMR; VREG_TPS63070RNMR
U3: TPS3702; SOT-23-6
VCC: PTR1B1,27; B1,27

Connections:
+5V: C10.1, F1.1, JP1.2, U3.3 (SENSE)
/MR: Q4.3 (D), U1.4 (!MR)
EN: R12.2, R13.1, U2.14 (EN)
GND: C1.2, C3.2, C4.2, C5.2, C6.2, C7.2, C8.2, C9.2, C10.2, C11.2, GND.TP, JP1.1, Q2.2 (S), Q3.E, Q5.2 (S), R4.1, R9.1, R13.2, R16.1, U1.3 (GND), U2.4 (GND), U2.6 (FB2), U2.10 (PGND), U2.15 (VSEL), U3.2 (GND), U3.4 (SET)
unnamed: C1.1, R7.1, U1.2 (VDD)
unnamed: L1.2, U2.11 (L1)
unnamed: L1.1, U2.9 (L2)
unnamed: R10.2, U2.2 (PG)
unnamed: C8.1, U2.3 (VAUX)
unnamed: R8.1, R9.2, U2.5 (FB)
unnamed: Q5.3 (D), Q6.3 (G), R14.2
unnamed: C11.1, Q5.1 (G), R15.2, R16.2
unnamed: Q1.B, R2.1
unnamed: Q1.C, Q4.1 (G), R3.1, R4.2
unnamed: Q3.B, R3.2
unnamed: Q2.3 (D), Q3.C, R1.1, R2.2
PS: R11.1, U2.1 (PS/SYNC)
PSU_EN: Q2.1 (G), Q4.2 (S), R5.2, R12.1, U1.1 (!RESET), U3.6 (OV)
SW: JP1.5, R15.1, SW.TP
VCC: C3.1, C4.1, C5.1, C9.1, JP1.3, JP1.4, Q6.4 (S), R7.2, R11.2, R14.1, U2.12_13 (VIN), U3.5 (VDD), VCC.TP
VCC_LATCH: Q1.E, Q6.1 (D1), Q6.2 (D2), Q6.5 (D5), Q6.6 (D6), R1.2, R5.1
VOUT: 5V.TP, C6.1, C7.1, F1.2, R8.2, R10.1, U2.7_8 (VOUT)

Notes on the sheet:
3906
TPS3840DL35
TPS3702CX50DDCT

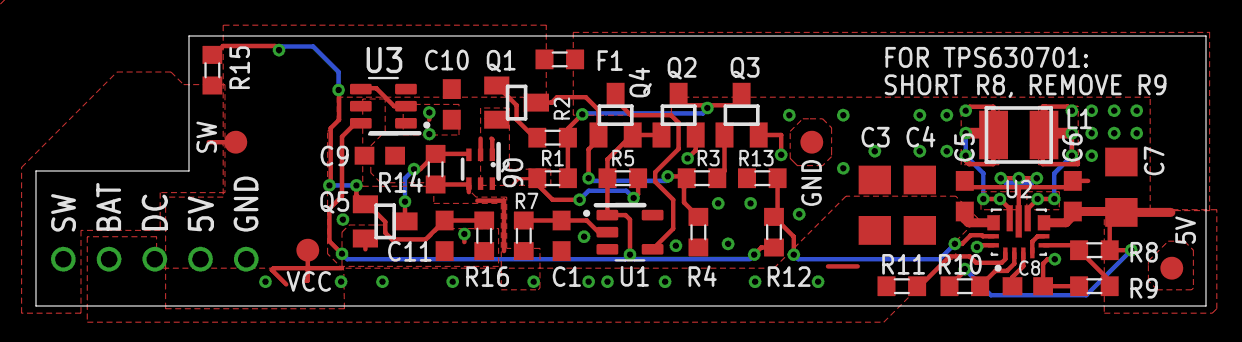
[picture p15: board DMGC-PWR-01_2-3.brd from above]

Board: 2 copper layers, 65.0 x 15.0 mm, 41 parts (0 on the bottom side), 22 nets.

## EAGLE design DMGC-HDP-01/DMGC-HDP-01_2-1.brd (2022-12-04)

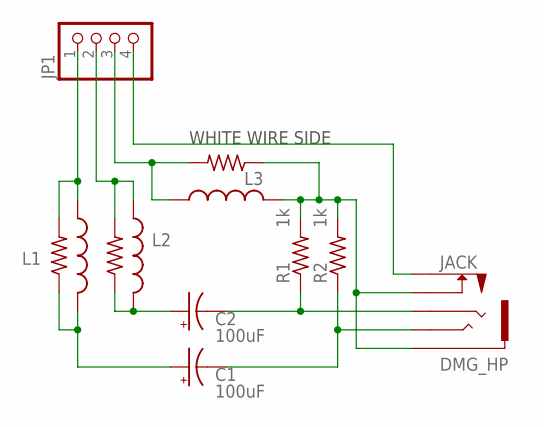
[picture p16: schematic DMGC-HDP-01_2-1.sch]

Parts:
C1, C2: 100uF; E2,5-5
EM1, EM2, EM9: BLM21P221SG; R0603
JACK: DMG_HP
JP1: PINHD-1X4; 1X04
L1, L2, L3: 33µH; 0204/7
R1, R2: 1k; R0603

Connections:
unnamed: EM9.2, JP1.1, L1.1
unnamed: EM2.2, JP1.3, L3.1
unnamed: EM1.2, JP1.2, L2.1
unnamed: C1.+, EM9.1, L1.2
unnamed: C2.+, EM1.1, L2.2
unnamed: EM2.1, JACK.GND (S), JACK.SWGND (SWB), L3.2, R1.2, R2.2
unnamed: JACK.SW (SWA), JP1.4
unnamed: C2.-, JACK.R, R1.1
unnamed: C1.-, JACK.T, R2.1

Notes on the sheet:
WHITE WIRE SIDE

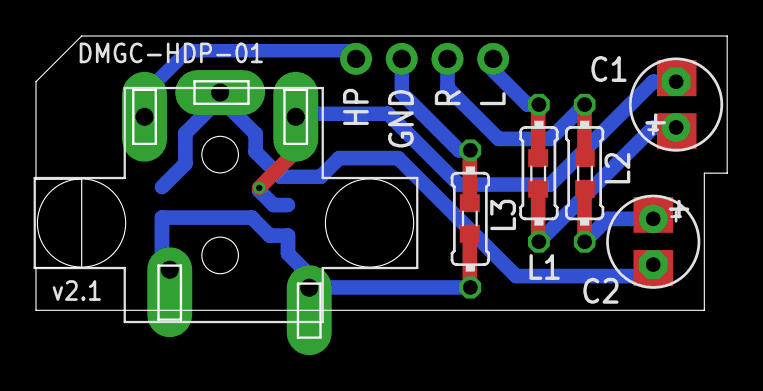
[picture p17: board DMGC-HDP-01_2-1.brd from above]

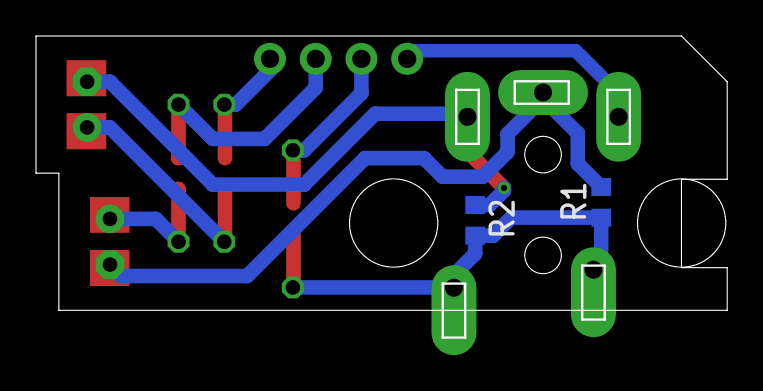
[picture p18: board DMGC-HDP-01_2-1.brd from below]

Board: 2 copper layers, 38.4 x 16.8 mm, 12 parts (2 on the bottom side), 9 nets.

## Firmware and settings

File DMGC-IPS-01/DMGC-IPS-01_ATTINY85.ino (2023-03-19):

// ********************************************************************
// *DISCONNECT THE CPU AND Q5 KIT RIBBON CABLES BEFORE PROGRAMMING!!!!*
// ********************************************************************

#include <Adafruit_NeoPixel.h>
#include <EEPROM.h>
#include <avr/interrupt.h>
#include <avr/power.h>
#include <avr/sleep.h>

// Which pin on the Arduino is connected to the NeoPixels?
#define OUT           PCINT4 // PB4
#define pushbtn       PCINT3 // PB3
#define leftbtn       PCINT2 // PB2
#define rightbtn      PCINT1 // PB1
#define selbtn        PCINT0 // PB0

// Define order of LEDs in string, starting with 0
#define l             1
#define u             0
#define d             2
#define r             3
#define se            4
#define st            5
#define b             6
#define a             7

#define NUMPIXELS 8 // Popular NeoPixel ring size

Adafruit_NeoPixel pixels(NUMPIXELS, OUT, NEO_GRB + NEO_KHZ800);

volatile uint8_t brightness;
volatile uint8_t color_type;
const uint8_t    COLOR_QTY  = 14;
const uint8_t    RAINBOW_START_IDX = 10;
const uint8_t    DEBOUNCE_DELAY = 50;
const uint8_t    LOOP_DELAY = 10;
const uint8_t    BRIGHTNESS_INC = 5;
const uint8_t    MIN_BRIGHTNESS = 5;
const uint8_t    MAX_BRIGHTNESS = 50;

volatile uint8_t brightness_change_flag = 0;

// cycles through different colors:  red  org  ylw  grn  cyan blue purp pink wht  off rainbow rainbow_slow rainbow_med rainbow_fast
const uint8_t red[COLOR_QTY]     = { 255, 255, 255, 0,   0,   0,   255, 242, 255, 0,  0,      0,           0,          0};
const uint8_t green[COLOR_QTY]   = { 0,   100, 200, 255, 255, 0,   0,   90,  255, 0,  0,      0,           0,          0};
const uint8_t blue[COLOR_QTY]    = { 0,   0,   0,   0,   255, 255, 255, 255, 255, 0,  0,      0,           0,          0};
// Rainbow animation speed
const uint8_t rainbow[COLOR_QTY] = { 0,   0,   0,   0,   0,   0,   0,   0,   0,   0,  0,      37,          76,         151};

const uint8_t RAINBOW_SAT    = 255; // Rainbow saturation (S in HSV)
const uint8_t RAINBOW_VAL    = 255; // Rainbow value (V in HSV)
const uint16_t RAINBOW_START = 10240; // Chosen a bit arbitrarily
volatile uint16_t rainbow_current = RAINBOW_START;

void setup() {

  // Disable the ADC to save a slight amount of power
  ADCSRA = 0;
  power_adc_disable();

  // Set SLEEP_MODE_PWR_DOWN, the lowest power sleep mode
  set_sleep_mode(SLEEP_MODE_PWR_DOWN);

  pixels.begin();

  EEPROM.get(0, brightness);
  EEPROM.get(1, color_type);

  // Check if EPROM data was corrupted, set brightness to max or min values
  if (brightness>MAX_BRIGHTNESS){
    brightness=MAX_BRIGHTNESS;
    EEPROM.put(0,brightness);
  }
  if (brightness<MIN_BRIGHTNESS){
    brightness=MIN_BRIGHTNESS;
    EEPROM.put(0,brightness);
  }

  // Set color_type back to 0 if it's an invalid value
  if (color_type>COLOR_QTY-1){
    color_type=0;
    EEPROM.put(1,color_type);
  }

  pixels.setBrightness(brightness);

  // Inputs *MUST NOT* use ATTINY's pull-ups. These will rely on the GBC CPU's internal pull-ups to 3.3V. The ATTINY is powered by 5V!!
  // When developing without the CPU board plugged in, change these to INPUT_PULLUP. Change them back to INPUT before reassembly!
  pinMode(pushbtn, INPUT);
  pinMode(leftbtn, INPUT);
  pinMode(rightbtn, INPUT);
  pinMode(selbtn, INPUT);

  // Skip intro if nav switch is pushed in
  if (digitalRead(pushbtn)==HIGH){

      pixels.clear();
      pixels.show();
      delay(1100);

      const int y=6;
      int k=0;

      const uint8_t introarray[24] = {9,9,9,9,9,9,9,2,2,0,0,6,6,3,3,5,5,5,5,5,5,5,5,5};

      // Loop through values in introarray. Delays were timed experimentally.
      for(int j=0; j<16; j++){
        for(int i=0; i<NUMPIXELS; i++){
          if(i==l){
            k=introarray[j+6];
          }
          if(i==u){
            k=introarray[j+5];
          }
          if(i==d){
            k=introarray[j+5];
          }
          if(i==r){
            k=introarray[j+4];
          }
          if(i==se){
            k=introarray[j+3];
          }
          if(i==st){
            k=introarray[j+2];
          }
          if(i==b){
            k=introarray[j+1];
          }
          if(i==a){
            k=introarray[j];
          }
        pixels.setPixelColor(i, pixels.Color(red[k],green[k],blue[k]));
        pixels.show();
        delay(y);
        }
      }
      delay(2000);
  }else{
    while(1){
      sleep(false); // Sleep forever!
    };
  }
//  while(!digitalRead(pushbtn)){
//    delay(10);
//  }
}

void loop() {
  // If nav switch is pressed
  if(digitalRead(pushbtn)==LOW){
    // Pause the program to debounce the switch, check to make sure it's still pressed
    delay(DEBOUNCE_DELAY);
    if(digitalRead(pushbtn)==LOW){

      // I'm sorry, I forgot to comment this, and now I'm reading it months later
      while(!digitalRead(pushbtn) && !digitalRead(pushbtn)){
        if(digitalRead(rightbtn)==LOW){
        delay(DEBOUNCE_DELAY);
          if(digitalRead(rightbtn)==LOW){
            while(!digitalRead(rightbtn)){
              delay(DEBOUNCE_DELAY);
            }
            if(brightness+BRIGHTNESS_INC>MAX_BRIGHTNESS){
              brightness=MAX_BRIGHTNESS;
            }else{
              brightness=brightness+BRIGHTNESS_INC;
            }
            brightness_change_flag = 1;
            pixels.setBrightness(brightness);
            outputLED(color_type);
          }
        }

        if(digitalRead(leftbtn)==LOW){
          delay(DEBOUNCE_DELAY);
          if(digitalRead(leftbtn)==LOW){
            while(!digitalRead(leftbtn) && !digitalRead(pushbtn)){
              delay(DEBOUNCE_DELAY);
            }
            if(brightness-BRIGHTNESS_INC<MIN_BRIGHTNESS){
              brightness=MIN_BRIGHTNESS;
            }else{
              brightness=brightness-BRIGHTNESS_INC;
            }
            brightness_change_flag = 1;
            pixels.setBrightness(brightness);
            outputLED(color_type);
          }
        }
        delay(DEBOUNCE_DELAY);
      }

      if(brightness_change_flag==0){
        if(color_type==COLOR_QTY-1){
          color_type=0;
          rainbow_current=RAINBOW_START;
        }else{
          color_type = color_type+1;
        }
      }
      // Save brightness and color setting to EPROM
      EEPROM.update(0,brightness);
      EEPROM.update(1,color_type);
      brightness_change_flag = 0;
      }
    }

    // Update LED outputs
    outputLED(color_type);

    // Sleep if showing a static color or static rainbow
    if (color_type <= RAINBOW_START_IDX) {
      sleep(true);
    } else {
      // Delay just a bit so we're not refreshing the LEDs so fast
      delay(LOOP_DELAY);
    }
  }

void outputLED(uint8_t x){
  // Rainbow logic; similar to NeoPixel library's, except with first two pixels swapped
  if (x >= RAINBOW_START_IDX) {
    for (uint16_t i=0; i<NUMPIXELS; i++) { // For each pixel...
      uint16_t j = i; // Swap left and up
      if (j == u) {
        j = l;
      } else if (j == l) {
        j = u;
      }
      uint16_t hue = rainbow_current + (i * 65536) / NUMPIXELS;
      uint32_t color = pixels.ColorHSV(hue, RAINBOW_SAT, RAINBOW_VAL);
      pixels.setPixelColor(j, pixels.gamma32(color));
    }
    rainbow_current += rainbow[x];
  } else {
    for(int i=0; i<NUMPIXELS; i++) { // For each pixel..
      pixels.setPixelColor(i, pixels.Color(red[x],green[x],blue[x]));
    }
  }
  pixels.show();   // Send the updated pixel colors to the hardware.
}

// ISR - called when push is pushed during sleep to wake up
ISR(PCINT0_vect) {
  GIMSK &= ~0b00100000;  // Turn off pin change interrupts
  sleep_disable();
}

// Sleeps to save ~25 mW
void sleep(bool can_wake) {
  sleep_enable();
  if (can_wake) { // Enable interrupts so we can wake up
    noInterrupts();
    GIMSK |= 0b00100000;  // Turn on pin change interrupts
    PCMSK |= 1 << pushbtn; // For pin 3 - pushbtn
    interrupts();
  }
  sleep_cpu();
}

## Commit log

2022-06-28 Add BOM and in-text links
2022-06-28 Add files via upload
    Here's some advice everyone (including me) always gives but never follows: comment your code when you write it, don't try to do it months later
    Written for the ATTINY85.
    **If you modify the code, make sure all inputs are simply declared "inputs" WITHOUT pull-ups, as the GBC CPU provides internal pull-ups to 3.3 V**
2022-06-28 Update BOM
2022-06-28 Add master BOM
    [BOM.xlsx]
2022-07-20 Add files via upload
    Bracket for holding Q5 screen in place
    [dmgc_q5_bracket.stl]
2022-07-21 Add files via upload
    Add board scans
2022-07-21 Add board scans
2022-07-21 Add schematic image
2022-07-22 Update schematic
2022-07-22 Add files via upload
    Update schematic
2022-07-22 Add files via upload
    Update schematic, upload source files and gerbers
    [DMGC-IPS-01_1-3.brd, DMGC-IPS-01_1-3.sch]
2022-07-22 Add files via upload
    Update master BOM
    [BOM.xlsx]
2022-07-23 Add board blank picture
2022-07-23 Add schematic
2022-07-23 Upload source files and gerbers
    [DMGC-CPU-01_1-2.brd, DMGC-CPU-01_1-2.sch]
2022-07-23 Upload HEX file for LED code
2022-08-12 Update README.md
    Add assembly pictures
2022-08-12 Update README.md
    Update assembly pictures
2022-08-12 Add files via upload
    Upload gerbers, schematic, and board files
    [DMGC-CPU-01_1-3.brd, DMGC-CPU-01_1-3.sch]
2022-08-12 Update README.md
    Update board characteristics
2022-08-12 Update README.md
    Update circuit explanation
2022-08-12 Add files via upload
    Upload updated schematic
2022-08-12 Update README.md
    Add detail on Q5 board pads
2022-08-13 Update README.md
    Updated schematic in-text
2022-08-13 Update board characteristics section
2022-08-15 Updated BOM
    [BOM.xlsx]
2022-08-16 Update README.md
    Add photo of power switch cut
2022-08-17 Upload board scans and new schematic
2022-08-17 Upload gerbers and source files
    [DMGC-PWR-01_2-0.brd, DMGC-PWR-01_2-0.sch]
2022-08-17 Upload schematic, board scans, and assembled pictures
2022-08-18 Add source files and gerbers
    [DMGC-CPU-01_1-3.brd, DMGC-CPU-01_1-3.sch]
2022-08-19 Update BOM Excel
    [BOM.xlsx]
2022-08-26 Add note about board preview tool
2022-09-08 Add note about PWR board testing in assembly section
2022-09-09 Add note about taping off button pads
2022-09-15 Add note about how to adjust the brightness of the power LED
2022-09-15 Add note about shorting EM filters
2022-09-29 Update README.md
    Add note about Arduino IDE version
2022-10-01 Update R1 value in BOM
2022-10-16 Add pictures of black boards
2022-10-16 Update BOM with in-stock parts
2022-10-19 Add note about programming ATTINY on-board
2022-10-19 Add programming warning
    Ensure CPU and Q5 kit ribbon cables are disconnected before programming
2022-10-20 Update in-text BOM
2022-10-23 Add v2.0 files
    [DMGC-CPU-01_2-0.brd, DMGC-CPU-01_2-0.sch]
2022-10-23 Add information about silkscreen error
2022-10-24 Added PCBWay link
2022-10-24 Added links to PCBWay and Etsy for PCBs
2022-10-25 Update filter note
2022-10-31 Add note about OSD buttons
2022-10-31 Update note about OSD buttons
2022-11-11 Update Assembly section
2022-12-04 Add v2.1 files
    [DMGC-HDP-01_2-1.brd, DMGC-HDP-01_2-1.sch]
2022-12-04 Add note about tantalum electrolytic capacitors
2022-12-08 Add v2.2 files
    [DMGC-CPU-01_2-2.brd, DMGC-CPU-01_2-2.sch]
2022-12-08 Added v2.2 schematics
2022-12-09 Add v2.2 board scans
2022-12-28 Update README.md
    Update BOM
2023-01-13 Update BOM and v2.3 information
2023-01-13 Added v2.3 information, update BOM
2023-01-14 Add v2.3 files
    [DMGC-IPS-01_2-3.brd, DMGC-IPS-01_2-3.sch]
2023-01-14 Add v2.3 board scan
2023-01-14 Update reset button explanation
2023-01-14 Update reset button instructions
2023-01-14 Add v2.3 board scans
2023-01-16 Update tactile switch instructions
2023-01-16 Add reset button instructions
2023-01-16 Update assembly notes
2023-01-19 Added extra PWR board test
2023-04-09 Add note about Arduino programming
2023-04-15 Update holes per Cody
